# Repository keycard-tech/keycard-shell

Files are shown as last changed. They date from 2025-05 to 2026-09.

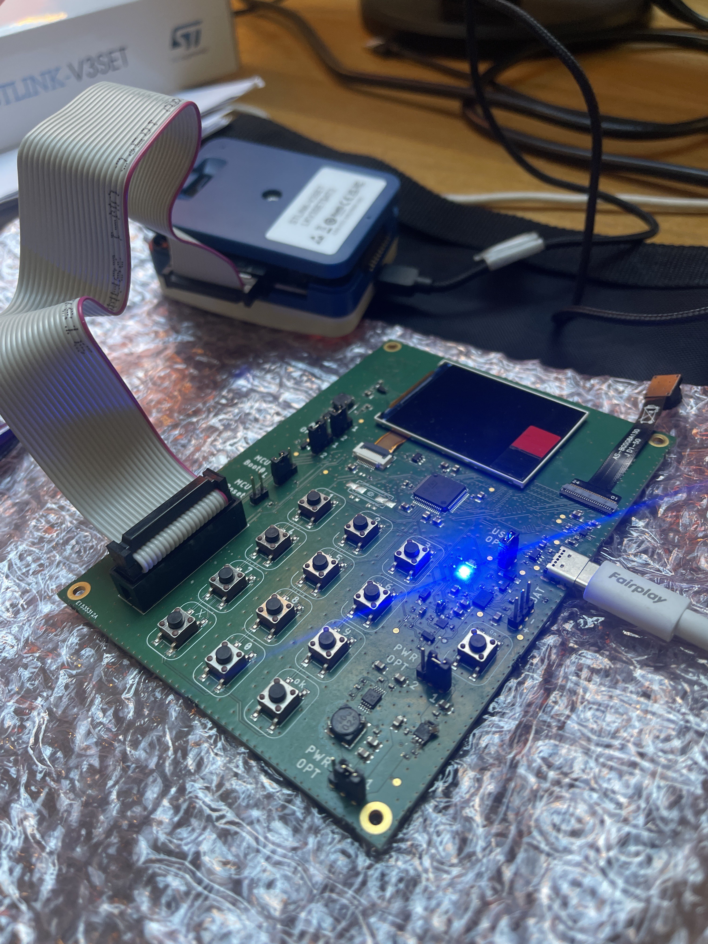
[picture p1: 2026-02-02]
hardware/development_board/IMG_6706.jpg

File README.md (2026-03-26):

# Keycard Shell

Keycard Shell transforms any Keycard into a standalone, air-gapped hardware wallet with built-in keypad, display, camera, and USB (which can be turned off). Fully open-source and EAL6+ certified, it uses ERC-4527 QR codes for secure signing and supports infinite removable backups.

## Main features

### Modular & Open Source

All firmware, hardware designs, and toolchain scripts are fully open source under the MIT license.

### Air-gapped Operation

Scan and display QR codes (ERC-4527) to sign transactions without ever exposing your keys.

### High-Security Secure Element

EAL6+ certified secure element for key storage and signing.

### Removable Smartcards

Support for an infinite number of Keycard smartcards, each with its own key & PIN.

### Wide Compatibility

Works seamlessly with MetaMask, imToken, Rabby, BlueWallet, Sparrow, Specter, and more.

### Built to Last

Powered by a replaceable Nokia BL-4C battery (25+ year expectancy), water & dust resistant.

### Duress PIN

A second PIN stops bad actors from stealing crypto by physical force

## About this repo

This repo contains everything needed to build a Keycard Shell.

### Repo structure

* `app`: the main firmware code. This is what makes everything happen.
* `bootloader`: the bootloader. Since it is non-upgradable we kept its complexity to a minimum.
* `cddl`: contains definitions for the various CBOR messages defined by the UR standard
* `deployment`: git-ignored folder containing the signing keys and build results
* `freertos`: we use FreeRTOS as our task scheduler.
* `hardware`: everything hardware related. From schematics up to case designs.
* `json`: example json files for abi, token and chain db. These files are unused.
* `stm32`: all platform-specific code for the STM32H5 MCU. It also contains the project file for STM32CubeIDE needed to build the firmware.
* `test`: the tests firmware we run in the factory on each unit to check it has been properly assembled.
* `tools`: some tools used during the build process or during development.
* `zcbor`: the library we use to parse CBOR messages.

### Building the firmware

The Keycard Shell firmware build system uses CMake for the main firmware compilation and Python tools for post-processing (signing, image creation, database generation).

#### Getting the Code

First, clone the repository and switch to the release tag you want to build:

```bash
git clone https://github.com/keycard-tech/keycard-shell.git
cd keycard-shell
git checkout v1.1.1   # use the tag matching the official release you want to verify
```

make sure you follow the build instructions directly for the tag you checked out since some steps and toolchain versions can differ.

#### Prerequisites

##### Install Build Tools

**CMake** (3.15 or later) and **Ninja** are required for building the firmware.

On Ubuntu/Debian:
```bash
sudo apt install cmake ninja-build
```

On macOS (with Homebrew):
```bash
brew install cmake ninja
```

On Windows (with Chocolatey):
```bash
choco install cmake ninja
```

Alternatively, download from [cmake.org](https://cmake.org/download/) and [ninja-build.org](https://ninja-build.org/).

##### Install uv

```bash
curl -LsSf https://astral.sh/uv/install.sh | sh
```

or follow your OS instructions for installing uv.

##### Install ARM GCC Toolchain

Required for compiling STM32 firmware. The toolchain is automatically downloaded by the build script:

```bash
./tools/download-toolchain.sh
```

The script supports:
- Linux x86_64
- Linux aarch64
- macOS (Apple Silicon / arm64)
- Windows x86_64

After downloading, the toolchain is installed in `toolchain/`.

#### Setup Signing Keys

Create a `deployment` directory with two files:

- `bootloader-pubkey.txt`: Contains the public key the bootloader will use to verify the firmware. The key must be hex-encoded, uncompressed, and without the leading `04` byte.
- `fw-test-key.txt`: Contains a hex-encoded private key (the private part of the key in `bootloader-pubkey.txt`) used to sign the firmware.

#### Setup Virtual Environment

```bash
uv venv
uv sync
```

#### Build Firmware

```bash
cmake --preset release
cmake --build --preset release
```

#### Verifying the Firmware

After building, run:

```bash
uv run python tools/firmware-hash.py -b build/shellos.bin
```

Download the official binary from the [GitHub releases page](https://github.com/keycard-tech/keycard-shell/releases) and hash it the same way:

```bash
uv run python tools/firmware-hash.py -b ~/Downloads/shellos-<date>-<version>.bin
```

The two hashes must match.

#### Creating a Full Firmware Image

If you want to generate a full image to load on a device you built yourself, take a look at the `tools/create-image.py` script.

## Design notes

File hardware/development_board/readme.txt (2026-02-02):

For security reasons Shell in presales and sales have a locked bootloader that can only run firmwares which have been signed by Keycard CA key. This insures our users that they can trust the software they run. 

For developers who want to develop Shell firmware, you will find in this folder the full design of a development board for Shell

The folder '/devboard_v1' contains this design. Please note that there are some differences in the STM32 pinout between this development board version and shell board.

We'd need someone to update the layout of this dev board based on latest shell designs so that the dev board can actually run the shell builds.

Probably the best way to do this, would be to use the design and schematic from 'serial_run' version and make it in the form factor of this development board 

Get in touch with us either 
- on our discord server https://discord.gg/uJAXk7jFhZ
- our here with a GitHub issue or GitHub discussion

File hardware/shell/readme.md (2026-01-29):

This directory contains the full open-source design for Keycard Shell. It includes electronics, mechanical parts, and certification documents grouped by release series.

## Versions
- `serial_run` corresponds to the design of Keycard Shell launched officially in January 2026
- `pilot_run` ⚠️ deprecated 
- `prototype_v2` ⚠️ deprecated

## Detail of content 
- electronic design: schematics (PDF and editable files), Gerbers, bill of materials, and PCB data archives
- mechanical design: 3D `.step` files for each part, 2D definitions, and a full `.step` of the assembled Keycard Shell
- list of parts of the full assembly, including reference sub-assemblies like screen, battery, camera, and packaging
- certification: full qualification and regulatory reports covering EMC, safety, and transportation

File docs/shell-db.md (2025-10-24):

# Keycard Shell Database

The Keycard Shell Database contains data about Ethereum ABIs, Chains and ERC20 tokens. The script contained in `tools/shell-db.py` is able to generate the database binary files starting from JSON files. For details about the format of the input JSON files look at:

* Ethereum ABI: list of functions, as generated by the [Solidity compiler](https://docs.soliditylang.org/en/latest/abi-spec.html#json)
* Chainlist: format defined by [https://chainlist.org/](https://chainlist.org/)
* ERC20 List: format defined by [https://tokenlists.org/](https://tokenlists.org/)

You are able to reproduce the bin file used to update the database on your Keycard Shell by downloading the source JSON files from https://shell.keycard.tech/update/db-version-history and following the below instructions. The generated file will be identical to the one generated by us, except for the last 64 bytes which are the signature.

## Requirements

All commands in this guide assume you are in the keycard-shell repository. Adjust paths accordingly if needed.

You need to have Python >= 3.12 and install the dependencies with

`pip install -r tools/requirements.txt`

## Building the database

Once you have downloaded the source files for the database version you wish to reproduce, unzip the files and run the following command.

`python tools/shell-db.py -t /path/to/json/files/erc20.json -c /path/to/json/files/chain.json -a /path/to/json/files/abi.json -v VERSIONDATE -d -o db-out.bin`

you can then verify that the binary file included in the downloaded zip and file you just generated differ only in the last 64 bytes. The easiest way to do this is to run the included hashing tool (check the code, it just does SHA256 excluding the last 64 bytes) on both files and check that the output is the same.

`python tools/database-hash.py -b db-out.bin`

and

`python tools/database-hash.py -b /path/to/json/files/db.bin`

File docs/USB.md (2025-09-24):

# Keycard Shell USB protocol

Keycard Shell presents itself to the USB host a HID device with VID 0x1209 and PID 0x21f7. The protocol has been inspired by the one by used by Ledger, being compatible at the transport layer but diverging at the command level.

## Command transport

Keycard Shell exchanges commands with the host following a format closely resembling ISO7816 APDUs. Communication is always started by the host by sending a C-APDU and will receive a single R-APDU in reply by Shell. Timeouts should be handled at USB host level but must account for the fact that many actions require user interaction before a R-APDU is generated.

### C-APDU format

* CLA: 1 byte, set to 0xe0
* INS: 1 byte, identifies the command to execute
* P1: 1 byte, first parameter of the command. Used mostly for command chaining
* P2: 1 byte, second parameter of the command
* Lc: 1 byte, 0-255, length of following Data field
* Data: additional data length. Absent if Lc = 0

### R-APDU format

* Data: 0-253 bytes, response data
* Status Words (SW): 2 bytes error code of the command.

### Command chaining

Since C-APDU are limited to 255 bytes for their data field, it is often necessary to split the payload across multiple APDUs. This is achieved the following way:

1. the host prepares the full payload and splits in chunks of maximum 255 bytes
2. the first chunk is sent with P1 = 0
3. Shell will respond with SW = 0x9000 and no other response data (unless this was the only chunk)
4. all other chunks are sent with P1 = 1
5. Shell will acknowledge each intermediate chunk with SW = 0x9000 while the response to the last chunk will contain the actual reponse.

For this chaining scheme to work Shell must be able to detect when data ends. The way this is handled depends on each command but it either involves including the total length in the first segment or by transmitting data that instrinsically allows detecting its end.

### Encoding conventions

1. All multibyte integers are encoded in big endian byte order
2. BIP32 paths are encoded by 1 byte representing the number of elements (max 10) followed by a sequence of 32-bit integers

### Status Words used by Shell:

* 0x9000: no error
* 0x61XX: more data available (XX is how much data will be in the next chunk)
* 0x6e00: invalid CLA
* 0x6d00: invalid INS (unknown command)
* 0x6982: operation denied (usually by the user)
* 0x6985: conditions not satified
* 0x6a80: invalid Data field
* 0x6501: feature not supported
* 0x6fXX: internal error

## Commands

### GET RESPONSE

* INS: 0xc0
* P1: 0x00
* P2: 0x00
* Data: None

This is a transport level command. In case the SW of the latest received R-APDU was 0x61XX send this command to receive the next chunk of the response. Repeat until you get a SW different from 0x61XX. 

If sent where not more data available, the command will respond with SW = 0x6985.

### GET DEVICE INFO

* INS: 0x06
* P1: 0x00
* P2: 0x00
* Data: None

Returns informations about the device. The format is as follow:

* Firmware version: 3 bytes, representing major, minor, patch revision version respectively.
* Database version: 4 bytes. It's integer value is a date in YYYYMMDD format.
* Device UID: 16 bytes. Unique identifier of this Shell unit.
* Public Key: 33 bytes. A public key that can be used for device verification purposes.

### GET PUBLIC

* INS: 0x02
* P1: 0x00
* P2: 0x00 for normal public key, 0x01 for extended public key
* Data: BIP32 path

Exports the public key of the given BIP32 derivation path. This operation requires user approval. The output format is as follows:

* Length of fingerprint: 1 byte
* Fingerprint: 4 bytes, the master key fingerprint. Useful to identify the wallet.
* Length of public key: 1 byte
* Public key: the public key either in compressed (33-bytes) or uncompressed (65 bytes).
* Length of chain code: 1 byte. If P2 = 0, the value is always 0.
* Chain code: extension to the public key, allowing the client to derive deeper level of public keys

### SIGN ETH TX

* INS: 0x04
* P1: used for command chaining
* P2: 0x00
* Data: BIP32 path, unsigned Ethereum transaction

Signs the given Ethereum transaction. This operation requires user approval. Returns a 65-bytes signature in (v, r, s) format.

### SIGN ETH MSG

* INS: 0x08
* P1: used for command chaining
* P2: 0x00
* Data: BIP32 path, message length on 4 bytes, message to sign

Signs the given message in a way compatible with Ethereum's `personal_sign` function. This operation requires user approval. Returns a 65-bytes signature in (v, r, s) format.

### SIGN EIP712

* INS: 0x0c
* P1: used for command chaining
* P2: 0x00
* Data: BIP32 path, message length on 4 bytes, EIP712 message to sign

Signs the given EIP712 message. This operation requires user approval. Returns a 65-bytes signature in (v, r, s) format.

### SIGN PSBT

* INS: 0x0e
* P1: used for command chaining
* P2: 0x00
* Data: PSBT length on 4 bytes, PSBT to sign

Signs the given PSBT. This operation requires user approval. Returns the entire PSBT with added signatures. Retrieving the full response is likely to require the usage of the `GET RESPONSE` command.

### FW UPGRADE

* INS: 0xf2
* P1: used for command chaining
* P2: 0x00
* Data: firmware length on 4 bytes, firmware to load

Performs a firmware upgrade. This operation requires user approval and the firmware's signature will be verified. The length fo each data chunk must be a multiple of 16 bytes, meaning that the maximum chunk length is 240 bytes. Shell will reply with SW = 0x9000 on success and reboot, which will interrupt the USB connection.

### DB UPGRADE

* INS: 0xf4
* P1: used for command chaining
* P2: 0x00
* Data: databse length on 4 bytes, database to load

Performs a database upgrade. This operation requires user approval and the database's signature will be verified.

## HID framing

Since we are using the USB HID profile, the APDUs will need to be packed into HID frames, which have a length of 64 bytes and thus will require further segmentation/reassembly.

Each frame has the following format

Channel ID: 2 bytes, arbitrarely chosen by the host and repeated by Shell
Frame type: 1 byte. Set to 0x05 for APDU and 0x02 for PING
Segment number: 2 bytes indicating the current segment number (starting from 0)
Total data length: 2 bytes, only present if the segment number = 0 and is the total length of the APDU being transmitted
Data: the chunk of the APDU being transmitted, filling the remaining bytes of the HID frame

If frame type is PING, the Shell will answer with the exact same data received. This is ony useful for link diagnostic.

The APDU frame type is used for both C-APDU and R-APDU and the segmentation/reassembly procedure are exactly the same for both.

### Segmentation

1. Split the data to send into chunks of (64 - 5) bytes, with the first chunk being (64 - 7) bytes.
2. Send the first chunk with segment number = 0 and total data length set to the APDU size.
3. If there is more data to send, increment segment number by 1 and send the next chunk.
4. Repeat until no more chunks. Signal the upper layer that transmission succeded.

### Reassembly

1. If segment number == 0 reset the receiving buffer and set it's final length to the to value of the total data length field.
2. Append the data chunk to the receiving buffer. Increment the expected segment number by 1.
3. Upon receiving the next chunk (if any) check the segment number to matches the expected segment number and append its data to the receiving buffer.
4. When received data matches the total data length, signal the upper layer that reception succeded. Note that the last chunk might contain extra bytes since HID frames are always 64 bytes long. These bytes must be ignored and not added to the receiving buffer.

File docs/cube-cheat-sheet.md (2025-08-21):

# STM3 Programmer CLI cheatsheet

Some commands useful during development

## Write protect bootloader

```shell
.\STM32_Programmer_CLI.exe -c port=SWD ap=1 mode=Hotplug -ob wrpsgn1=0xfffffffe -ob wrpsgn2=0xfffffffe
```

## Disable write protection

```shell
.\STM32_Programmer_CLI.exe -c port=SWD ap=1 mode=Hotplug -ob wrpsgn1=0xffffffff -ob wrpsgn2=0xffffffff
```

## Product state Provisioning

```shell
.\STM32_Programmer_CLI.exe -c port=SWD ap=1 mode=Hotplug -ob product_state=0x17
```

## Product state Locked

```shell
.\STM32_Programmer_CLI.exe -c port=SWD ap=1 mode=Hotplug -ob product_state=0x5c
```

## Swap banks

```shell
.\STM32_Programmer_CLI.exe -c port=SWD ap=1 mode=Hotplug -ob swap_bank=0
```

## Erase all

```shell
.\STM32_Programmer_CLI.exe -c port=SWD ap=1 mode=Hotplug -e all
```

## Erase bootloader

```shell
.\STM32_Programmer_CLI.exe -c port=SWD ap=1 mode=Hotplug -e [0 3] -e [128 131]
```

## Erase firmware

```shell
.\STM32_Programmer_CLI.exe -c port=SWD ap=1 mode=Hotplug -e [4 79] -e [132 207]
```

## Download full

```shell
.\STM32_Programmer_CLI.exe -c port=SWD ap=1 mode=Hotplug --skiperase -w stm32h5.bin 0x08000000 -v
```

## Download bootloader

```shell
.\STM32_Programmer_CLI.exe -c port=SWD ap=1 mode=Hotplug --skiperase -w stm32-bootloader.bin 0x08000000 -v
.\STM32_Programmer_CLI.exe -c port=SWD ap=1 mode=Hotplug --skiperase -w stm32-bootloader.bin 0x08100000 -v
```

## Download firmware

```shell
.\STM32_Programmer_CLI.exe -c port=SWD ap=1 mode=Hotplug --skiperase -w stm32.bin 0x08008000 -v
.\STM32_Programmer_CLI.exe -c port=SWD ap=1 mode=Hotplug --skiperase -w stm32.bin 0x08108000 -v
```

## Full bootloader replace sequence

```shell
.\STM32_Programmer_CLI.exe -c port=SWD ap=1 mode=Hotplug -ob wrpsgn1=0xffffffff -ob wrpsgn2=0xffffffff
.\STM32_Programmer_CLI.exe -c port=SWD ap=1 mode=Hotplug -ob swap_bank=0
.\STM32_Programmer_CLI.exe -c port=SWD ap=1 mode=Hotplug -e [0 3] -e [128 131]
.\STM32_Programmer_CLI.exe -c port=SWD ap=1 mode=Hotplug --skiperase -w C:\Users\tanuki\git\keycard-pro\stm32\BL\stm32-bootloader.bin 0x08000000 -v
.\STM32_Programmer_CLI.exe -c port=SWD ap=1 mode=Hotplug --skiperase -w C:\Users\tanuki\git\keycard-pro\stm32\BL\stm32-bootloader.bin 0x08100000 -v
.\STM32_Programmer_CLI.exe -c port=SWD ap=1 mode=Hotplug -ob wrpsgn1=0xfffffffe -ob wrpsgn2=0xfffffffe
```

## Full fw replace sequence

```shell
.\STM32_Programmer_CLI.exe -c port=SWD ap=1 mode=Hotplug -ob swap_bank=0
.\STM32_Programmer_CLI.exe -c port=SWD ap=1 mode=Hotplug -e [4 79] -e [132 207]
.\STM32_Programmer_CLI.exe -c port=SWD ap=1 mode=Hotplug --skiperase -w stm32.bin 0x08008000 -v
.\STM32_Programmer_CLI.exe -c port=SWD ap=1 mode=Hotplug --skiperase -w stm32.bin 0x08108000 -v
```

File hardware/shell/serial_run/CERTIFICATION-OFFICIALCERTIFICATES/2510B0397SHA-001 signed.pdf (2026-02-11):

Disclaimer: This document is controlled and has been released electronically. Only the version on the IECEE Website is the current document version

Test Report issued under the responsibility of:

### TEST REPORT IEC 62368-1

## Audio/video, information and communication technology equipment Part 1: Safety requirements

Report Number | : | 2510B0397SHA-001
Date of issue | : | 2026-02-02
Total number of pages | : | 57 pages
Name of Testing Laboratory preparing the Report | : | Intertek Testing Services (Shanghai FTZ) Co., Ltd.
Applicant’s name | : | Status Research and Development GmbH
Address | : | Baarerstrasse 10, 6302 Zug, Switzerland

Test specification:

Standard | : | UL 62368-1:2019 Ed.3+R:22Oct2021
| CSA C22.2#62368-1:2019 Ed.3+U1
Test procedure | : | Testing
Non-standard test method | : | N/A
TRF template used | : | IECEE OD-2020-F1:2021, Ed.1.4
Test Report Form No | : | IEC62368_1E
Test Report Form(s) Originator.... : | UL(US)
Master TRF | : | Dated 2022-04-14

Copyright © 2022 IEC System of Conformity Assessment Schemes for Electrotechnical Equipment and Components (IECEE System). All rights reserved.

This publication may be reproduced in whole or in part for non-commercial purposes as long as the IECEE is acknowledged as copyright owner and source of the material. IECEE takes no responsibility for and will not assume liability for damages resulting from the reader's interpretation of the reproduced material due to its placement and context.
If this Test Report Form is used by non-IECEE members, the IECEE/IEC logo and the reference to the CB Scheme procedure shall be removed.

This report is not valid as a CB Test Report unless signed by an approved CB Testing Laboratory and appended to a CB Test Certificate issued by an NCB in accordance with IECEE 02.

General disclaimer:

The test results presented in this report relate only to the object tested.
This report shall not be reproduced, except in full, without the written approval of the Issuing CB Testing Laboratory. The authenticity of this Test Report and its contents can be verified by contacting the NCB, responsible for this Test Report.

Page 2 of 57 | Report No. 2510B0397SHA-001

TRF No. IEC62368_1E

Test item description | : | Keycard shell
Trade Mark(s) | : | Keycard
Manufacturer | : | Same as applicant
Model/Type reference | : | Shell
Ratings | : | 5Vdc, 1A, Class III

Responsible Testing Laboratory (as applicable), testing procedure and testing location(s):

| CB Testing Laboratory: | Intertek Testing Services (Shanghai FTZ) Co., Ltd.
Testing location/ address | : | | Building 86, No.1198, Qinzhou North Road, Shanghai, China
Tested by (name, function, signature) ....... : | Henry Huang/ Adage Zhang (Engineer)
Approved by (name, function, signature) .. : | Sam Li (Mandated Reviewer)
| Testing procedure: CTF Stage 1:
Testing location/ address | :

Tested by (name, function, signature) ....... :

Approved by (name, function, signature) .. :

| Testing procedure: CTF Stage 2:
Testing location/ address | :
Tested by (name, function, signature) |

Witnessed by (name, function, signature). :

Approved by (name, function, signature) .. :

| Testing procedure: CTF Stage 3:
| Testing procedure: CTF Stage 4:
Testing location/ address | :

Tested by (name, function, signature) ....... :

Witnessed by (name, function, signature). :

Approved by (name, function, signature) .. :

Supervised by (name, function, signature) :

Page 3 of 57 | Report No. 2510B0397SHA-001

TRF No. IEC62368_1E

List of Attachments (including a total number of pages in each attachment): Page 48 - 54: National differences for USA and Canada
Page 55 - 57: Photograph of the Equipment under test (EUT).

Summary of testing:

All tests are performed and the most disadvantageous results are recorded. We conclude that the appliances comply with this standard.

Tests performed (name of test and test clause):
5.2, Classification of electrical energy sources

5.4.1.4, 6.3, 6.4, 9.0, B.2.6, B.3, B.4,

Annex G.5.3, G.5.4, Heating test and abnormal &fault condition test

6.2.2, Electrical power sources (PS) measurements for classification

Annex B.2.5 Input test

Annex B.3, B.4, Abnormal operating and fault condition tests

Annex M.3, Protection circuits for batteries provided within the equipment

Annex M.4.2, Charging safeguards for equipment containing a secondary lithium battery

Testing location:
Intertek Testing Services (Shanghai FTZ) Co., Ltd. Building 86, No.1198, Qinzhou North Road, Shanghai, China

Summary of compliance with National Differences (List of countries addressed):

National differences for USA and Canada have been checked.

The product fulfils the requirements of UL 62368-1:2019 Ed.3+R:22Oct2021 and

CSA C22.2#62368-1:2019 Ed.3+U1

Page 4 of 57 | Report No. 2510B0397SHA-001

TRF No. IEC62368_1E

Use of uncertainty of measurement for decisions on conformity (decision rule) :

No decision rule is specified by the IEC standard, when comparing the measurement result with the applicable limit according to the specification in that standard. The decisions on conformity are made without applying the measurement uncertainty (“simple acceptance” decision rule, previously known as “accuracy method”).

Other:… (to be specified, for example when required by the standard or client, or if national accreditation requirements apply)

Information on uncertainty of measurement:
The uncertainties of measurement are calculated by the laboratory based on application of criteria given by OD-5014 for test equipment and application of test methods, decision sheets and operational procedures of IECEE.
IEC Guide 115 provides guidance on the application of measurement uncertainty principles and applying the decision rule when reporting test results within IECEE scheme, noting that the reporting of the measurement uncertainty for measurements is not necessary unless required by the test standard or customer.

Calculations leading to the reported values are on file with the NCB and testing laboratory that conducted the testing.

Copy of marking plate:

The artwork below may be only a draft. The use of certification marks on a product must be authorized by the respective NCBs that own these marks.

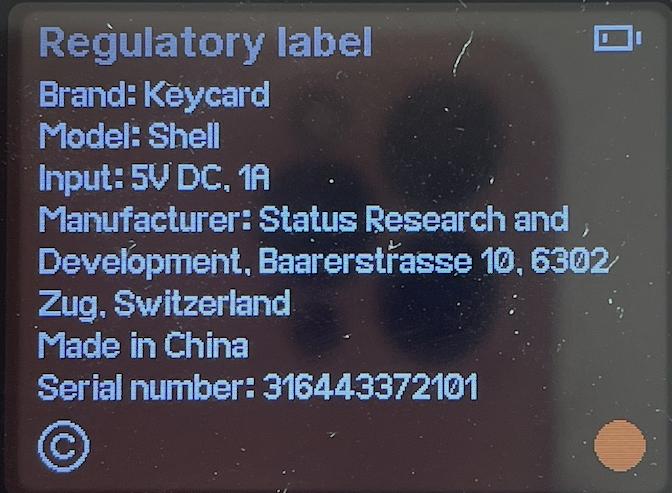
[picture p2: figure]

Page 5 of 57 | Report No. 2510B0397SHA-001

TRF No. IEC62368_1E

Test item particulars:

Product group | : | end product | built-in component
Classification of use by | : | Ordinary person | Children likely present
Instructed person
Skilled person
Supply connection | : | AC mains | DC mains
not mains connected:
| | ES1 | ES2 | ES3
Supply tolerance | : | +10%/-10%
+20%/-15%
| + | %/ - | %
| None
Supply connection – type | : | pluggable equipment type A -
non-detachable supply cord appliance coupler
direct plug-in
pluggable equipment type B -non-detachable supply cord appliance coupler
permanent connection
mating connector
other: Not direct connected to the mains Considered current rating of protective
device | :

A;
Location: | building | equipment
| N/A
Equipment mobility | : | movable | hand-held | transportable
direct plug-in | stationary | for building-in
wall/ceiling-mounted | SRME/rack-mounted
| other:
Overvoltage category (OVC) | : | OVC I | OVC II | OVC III
| OVC IV
other: Not direct connected to the mains
Class of equipment | : | Class I | Class II | Class III
Not classified
Special installation location | : | N/A | restricted access area
outdoor location
Pollution degree (PD) | : | PD 1 | PD 2 | PD 3
Manufacturer’s specified Tma | : 40 °C | Outdoor: minimum | °C
IP protection class | : | IPX0 | | IP___
Power systems | : | TN | TT | IT - | V L-L
not AC mains
Altitude during operation (m) | : | 2000 m or less | m
Altitude of test laboratory (m) | : | 2000 m or less | m
Mass of equipment (kg) | : <1 kg

Page 6 of 57 | Report No. 2510B0397SHA-001

TRF No. IEC62368_1E

Possible test case verdicts:

- test case does not apply to the test object....: N/A
- test object does meet the requirement | : P (Pass)
- test object does not meet the requirement....: F (Fail)

Testing:

Date of receipt of test item | : 2025-10-21
Date (s) of performance of tests | : 2025-10-21 to 2025-12-8

General remarks:
"(See Enclosure #)" refers to additional information appended to the report.
"(See appended table)" refers to a table appended to the report.
Throughout this report a | comma / | point is used as the decimal separator.
Determination of the test conclusion is based on IEC Guide 115 in consideration of measurement uncertainty.
This report is for the exclusive use of Intertek's Client and is provided pursuant to the agreement between Intertek and its Client. Intertek's responsibility and liability are limited to the terms and conditions of the agreement. Intertek assumes no liability to any party, other than to the Client in accordance with the agreement, for any loss, expense or damage occasioned by the use of this report. Only the Client is authorized to permit copying or distribution of this report and then only in its entirety. Any use of the Intertek name or one of its marks for the sale or advertisement of the tested material, product or service must first be approved in writing by Intertek. The observations and test results in this report are relevant only to the sample tested. This report by itself does not imply that the material, product, or service is or has ever been under an Intertek certification program.
When determining the test conclusion, the Measurement Uncertainty of test has been considered.

Manufacturer’s Declaration per sub-clause 4.2.5 of IECEE 02:

The application for obtaining a CB Test Certificate
includes more than one factory location and a
declaration from the Manufacturer stating that the
sample(s) submitted for evaluation is (are) representative of the products from each factory
has been provided | :
| | Yes
| | Not applicable

When differences exist; they shall be identified in the General product information section.

Name and address of factory (ies) | : ALTYOR Industries (Shanghai) Co., Ltd

152/1421 Zhuan Xing Dong Road Minhang District,

Shanghai, 201108, CHINA

General product information and other remarks:

The EUT is a keycard shell, class III of equipment for indoor use only, which supplied by built-in lithium battery, 3.7Vdc, the adaptor output is considered as ES1 and PS1 circuit.

Maximum recommended ambient (Tmra):40℃

Model Differences
N/A

Page 7 of 57 | Report No. 2510B0397SHA-001

TRF No. IEC62368_1E

OVERVIEW OF ENERGY SOURCES AND SAFEGUARDS

Clause | Possible Hazard
5 | Electrically-caused injury
Class and Energy Source (e.g. ES3: Primary circuit) | Body Part (e.g. Ordinary) | Safeguards
B | S | R
ES1: All circuits | Ordinary | N/A | N/A | N/A
6 | Electrically-caused fire
Class and Energy Source (e.g. PS2: 100 Watt circuit) | Material part (e.g. Printed board) | Safeguards
| | B | 1 st S | 2 nd S
PS1: Input circuits | All combustible materials on mainboard | N/A | N/A | N/A
PS1: Battery output circuits | All combustible materials on mainboard | N/A | N/A | N/A
7 | Injury caused by hazardous substances
Class and Energy Source (e.g. Ozone) | Body Part (e.g., Skilled) | Safeguards
| | B | S | R
Li-ion battery | Ordinary | Internal protection circuit | Enclosure | N/A
8 | Mechanically-caused injury
Class and Energy Source (e.g. MS3: Plastic fan blades) | Body Part (e.g. Ordinary) | Safeguards
| | B | S | R
MS1: Sharp edges and corners | Ordinary | N/A | N/A | N/A
MS1: Equipment mass | Ordinary | N/A | N/A | N/A
9 | Thermal burn
Class and Energy Source (e.g. TS1: Keyboard caps) | Body Part (e.g., Ordinary) | Safeguards
| | B | S | R
TS1: Accessible part | Ordinary | N/A | N/A | N/A
10 | Radiation
Class and Energy Source (e.g. RS1: PMP sound output) | Body Part (e.g., Ordinary) | Safeguards
| | B | S | R
N/A | N/A | N/A | N/A | N/A

Supplementary Information:

“B” – Basic Safeguard; “S” – Supplementary Safeguard; “R” – Reinforced Safeguard

a) represent for “Ignition not occur; not greater than 90% of the spontaneous ignition temperature limit”

Page 8 of 57 | Report No. 2510B0397SHA-001

TRF No. IEC62368_1E

ENERGY SOURCE DIAGRAM

Optional. Manufacturers are to provide the energy sources diagram identify declared energy sources and identifying the demarcations are between power sources. Recommend diagram be provided included in power supply and multipart systems.

Insert diagram below. Example diagram designs are; Block diagrams; image(s) with layered data; mechanical drawings

ES | PS | MS | TS | RS

Page 9 of 57 | Report No. 2510B0397SHA-001

IEC 62368-1

Clause | Requirement + Test | Result - Remark | Verdict

TRF No. IEC62368_1E

4 | GENERAL REQUIREMENTS | P
4.1.1 | Acceptance of materials, components and subassemblies | See appended table 4.1.2. | P
4.1.2 | Use of components | (See appended table 4.1.2) | P
4.1.3 | Equipment design and construction | No accessible part which could cause injury. | P
4.1.4 | Specified ambient temperature for outdoor use (oC) | : | | N/A
4.1.5 | Constructions and components not specifically covered | | N/A
4.1.8 | Liquids and liquid filled components (LFC) | (See G.15) | N/A
4.1.15 | Markings and instructions | (See Annex F) | P
4.4.3 | Safeguard robustness | | N/A
4.4.3.1 | General | | N/A
4.4.3.2 | Steady force tests | (See Clause T.3, T.4, T.5) | N/A
4.4.3.3 | Drop tests | | N/A
4.4.3.4 | Impact tests | | N/A
4.4.3.5 | Internal accessible safeguard tests | | N/A
4.4.3.6 | Glass impact tests | (See Clause T.9, Annex U) | N/A
4.4.3.7 | Glass fixation tests | | N/A
| Glass impact test (1J) | | N/A
| Push/pull test (10 N) | | N/A
4.4.3.8 | Thermoplastic material tests | (See Clause T.8) | N/A
4.4.3.9 | Air comprising a safeguard | | N/A
4.4.3.10 | Accessibility, glass, safeguard effectiveness | | N/A
4.4.4 | Displacement of a safeguard by an insulating liquid | | N/A
4.4.5 | Safety interlocks | (See Annex K) | N/A
4.5 | Explosion | | P
4.5.1 | General | (See Annex M for batteries) | P
4.5.2 | No explosion during normal/abnormal operating condition | (See Clause B.2, B.3) | P
| No harm by explosion during single fault conditions | (See Clause B.4) | P
4.6 | Fixing of conductors | | N/A
| Fix conductors not to defeat a safeguard | | N/A
| Compliance is checked by test | : | (See Clause T.2) | N/A
4.7 | Equipment for direct insertion into mains socket–outlets | | N/A

Page 10 of 57 | Report No. 2510B0397SHA-001

IEC 62368-1

Clause | Requirement + Test | Result - Remark | Verdict

TRF No. IEC62368_1E

4.7.2 | Mains plug part complies with relevant standard .. : | | N/A
4.7.3 | Torque (Nm) | : | | N/A
4.8 | Equipment containing coin/button cell batteries | | N/A
4.8.1 | General | | N/A
4.8.2 | Instructional safeguard | : | | N/A
4.8.3 | Battery compartment door/cover construction | | N/A
| Open torque test | | N/A
4.8.4.2 | Stress relief test | | N/A
4.8.4.3 | Battery replacement test | | N/A
4.8.4.4 | Drop test | | N/A
4.8.4.5 | Impact test | | N/A
4.8.4.6 | Crush test | | N/A
4.8.5 | Compliance | | N/A
| 30N force test with test probe | | N/A
| 20N force test with test hook | | N/A
4.9 | Likelihood of fire or shock due to entry of conductive object | | N/A
4.10 | Component requirements | | N/A
4.10.1 | Disconnect Device | (See Annex L) | N/A
4.10.2 | Switches and relays | (See Annex G) | N/A
5 | ELECTRICALLY-CAUSED INJURY | P
5.2 | Classification and limits of electrical energy sources | P
5.2.2 | ES1, ES2 and ES3 limits | | P
5.2.2.2 | Steady-state voltage and current limits | : | (See appended table 5.2) | P
5.2.2.3 | Capacitance limits | : | (See appended table 5.2) | N/A
5.2.2.4 | Single pulse limits | : | (See appended table 5.2) | N/A
5.2.2.5 | Limits for repetitive pulses | : | (See appended table 5.2) | N/A
5.2.2.6 | Ringing signals | (See Annex H) | N/A
5.2.2.7 | Audio signals | (See Clause E.1) | N/A
5.3 | Protection against electrical energy sources | | N/A
5.3.1 | General Requirements for accessible parts to ordinary, instructed and skilled persons | | N/A
5.3.1 a) | Accessible ES1/ES2 derived from ES2/ES3 circuits | | N/A
5.3.1 b) | Skilled persons not unintentional contact ES3 bare conductors | | N/A

Page 11 of 57 | Report No. 2510B0397SHA-001

IEC 62368-1

Clause | Requirement + Test | Result - Remark | Verdict

TRF No. IEC62368_1E

5.3.2.1 | Accessibility to electrical energy sources and safeguards | | N/A
| Accessibility to outdoor equipment bare parts | | N/A
5.3.2.2 | Contact requirements | | N/A
| Test with test probe from Annex V | | ⎯
5.3.2.2 a) | Air gap – electric strength test potential (V) | : | (See appended table 5.4.9) | N/A
5.3.2.2 b) | Air gap – distance (mm) | : | | N/A
5.3.2.3 | Compliance | | N/A
5.3.2.4 | Terminals for connecting stripped wire | | N/A
5.4 | Insulation materials and requirements | | N/A
5.4.1.2 | Properties of insulating material | | N/A
5.4.1.3 | Material is non-hygroscopic | | N/A
5.4.1.4 | Maximum operating temperature for insulating materials | : | (See appended table) | N/A
5.4.1.5 | Pollution degrees | : | | N/A
5.4.1.5.2 | Test for pollution degree 1 environment and for an insulating compound | | N/A
5.4.1.5.3 | Thermal cycling test | | N/A
5.4.1.6 | Insulation in transformers with varying dimensions | | N/A
5.4.1.7 | Insulation in circuits generating starting pulses | | N/A
5.4.1.8 | Determination of working voltage | : | (See appended table 5.4.1.8) | N/A
5.4.1.9 | Insulating surfaces | | N/A
5.4.1.10 | Thermoplastic parts on which conductive metallic parts are directly mounted | | N/A
5.4.1.10.2 | Vicat test | : | (See appended table 5.4.1.10.2) | N/A
5.4.1.10.3 | Ball pressure test | : | (See appended table 5.4.1.10.3) | N/A
5.4.2 | Clearances | | N/A
5.4.2.1 | General requirements | | N/A
| Clearances in circuits connected to AC Mains, Alternative method | (See Annex X) | N/A
5.4.2.2 | Procedure 1 for determining clearance | | N/A
| Temporary overvoltage | : | | ⎯
5.4.2.3 | Procedure 2 for determining clearance | | N/A
5.4.2.3.2.2 | a.c. mains transient voltage | : | | ⎯
5.4.2.3.2.3 | d.c. mains transient voltage | : | | ⎯

Page 12 of 57 | Report No. 2510B0397SHA-001

IEC 62368-1

Clause | Requirement + Test | Result - Remark | Verdict

TRF No. IEC62368_1E

5.4.2.3.2.4 | External circuit transient voltage | : | | ⎯
5.4.2.3.2.5 | Transient voltage determined by measurement ......: | | ⎯
5.4.2.4 | Determining the adequacy of a clearance using an electric strength test | : | (See appended table 5.4.2) | N/A
5.4.2.5 | Multiplication factors for clearances and test voltages | : | | N/A
5.4.2.6 | Clearance measurement | : | (See appended table 5.4.2) | N/A
5.4.3 | Creepage distances | | N/A
5.4.3.1 | General | | N/A
5.4.3.3 | Material group | : | | ⎯
5.4.3.4 | Creepage distances measurement | : | (See appended table 5.4.3) | N/A
5.4.4 | Solid insulation | | N/A
5.4.4.1 | General requirements | | N/A
5.4.4.2 | Minimum distance through insulation | : | (See appended table 5.4.4.2) | N/A
5.4.4.3 | Insulating compound forming solid insulation | | N/A
5.4.4.4 | Solid insulation in semiconductor devices | | N/A
5.4.4.5 | Insulating compound forming cemented joints | | N/A
5.4.4.6 | Thin sheet material | | N/A
5.4.4.6.1 | General requirements | | N/A
5.4.4.6.2 | Separable thin sheet material | | N/A
| Number of layers (pcs) | : | | N/A
5.4.4.6.3 | Non-separable thin sheet material | | N/A
| Number of layers (pcs) | : | | N/A
5.4.4.6.4 | Standard test procedure for non-separable thin sheet material | : | (See appended table 5.4.9) | N/A
5.4.4.6.5 | Mandrel test | | N/A
5.4.4.7 | Solid insulation in wound components | | N/A
5.4.4.9 | Solid insulation at frequencies >30 kHz, EP, KR, d, VPW (V) | : | (See appended Table 5.4.4.9) | N/A
| Alternative by electric strength test, tested voltage (V), KR | : | (See appended Tables 5.4.4.9 and 5.4.9) | N/A
5.4.5 | Antenna terminal insulation | | N/A
5.4.5.1 | General | | N/A
5.4.5.2 | Voltage surge test | | N/A
5.4.5.3 | Insulation resistance (MΩ) | : | | N/A
| Electric strength test | : | (See appended table 5.4.9) | N/A

Page 13 of 57 | Report No. 2510B0397SHA-001

IEC 62368-1

Clause | Requirement + Test | Result - Remark | Verdict

TRF No. IEC62368_1E

5.4.6 | Insulation of internal wire as part of supplementary safeguard | | N/A
5.4.7 | Tests for semiconductor components and for cemented joints | | N/A
5.4.8 | Humidity conditioning | | N/A
| Relative humidity (%), temperature (°C), duration (h) | : | | ⎯
5.4.9 | Electric strength test | | N/A
5.4.9.1 | Test procedure for type test of solid insulation.......: | (See appended table 5.4.9) | N/A
5.4.9.2 | Test procedure for routine test | | N/A
5.4.10 | Safeguards against transient voltages from external circuits | | N/A
5.4.10.1 | Parts and circuits separated from external circuits | | N/A
5.4.10.2 | Test methods | | N/A
5.4.10.2.1 | General | | N/A
5.4.10.2.2 | Impulse test | : | (See appended table 5.4.9) | N/A
5.4.10.2.3 | Steady-state test | : | (See appended table 5.4.9) | N/A
5.4.10.3 | Verification for insulation breakdown for impulse test | : | | N/A
5.4.11 | Separation between external circuits and earth | | N/A
5.4.11.1 | Exceptions to separation between external circuits and earth | | N/A
5.4.11.2 | Requirements | | N/A
| SPDs bridge separation between external circuit and earth | | N/A
| Rated operating voltage Uop (V) | : | | ⎯
| Nominal voltage Upeak (V) | : | | ⎯
| Max increase due to variation ΔUsp | : | | ⎯
| Max increase due to ageing ΔUsa | : | | ⎯
5.4.11.3 | Test method and compliance | : | (See appended table 5.4.9) | N/A
5.4.12 | Insulating liquid | | N/A
5.4.12.1 | General requirements | | N/A
5.4.12.2 | Electric strength of an insulating liquid | : | (See appended table 5.4.9) | N/A
5.4.12.3 | Compatibility of an insulating liquid | : | (See appended table 5.4.9) | N/A
5.4.12.4 | Container for insulating liquid | : | | N/A
5.5 | Components as safeguards | | N/A
5.5.1 | General | | N/A

Page 14 of 57 | Report No. 2510B0397SHA-001

IEC 62368-1

Clause | Requirement + Test | Result - Remark | Verdict

TRF No. IEC62368_1E

5.5.2 | Capacitors and RC units | | N/A
5.5.2.1 | General requirement | | N/A
5.5.2.2 | Safeguards against capacitor discharge after disconnection of a connector | : | (See appended table 5.5.2.2) | N/A
5.5.3 | Transformers | | N/A
5.5.4 | Optocouplers | (See sub-clause 5.4 or Clause G.12) | N/A
5.5.5 | Relays | (See sub-clause 5.4) | N/A
5.5.6 | Resistors | (See Clause G.10) | N/A
5.5.7 | SPDs | (See Clause G.8) | N/A
5.5.8 | Insulation between the mains and an external circuit consisting of a coaxial cable | : | | N/A
5.5.9 | Safeguards for socket-outlets in outdoor equipment | | N/A
| RCD rated residual operating current (mA) | : | | ⎯
5.6 | Protective conductor | | N/A
5.6.2 | Requirement for protective conductors | | N/A
5.6 | Protective conductor | | N/A
5.6.2 | Requirement for protective conductors | | N/A
5.6.2.1 | General requirements | | N/A
5.6.2.2 | Colour of insulation | | N/A
5.6.3 | Requirement for protective earthing conductors | | N/A
| Protective earthing conductor size (mm² ) | : | | ⎯
| Protective earthing conductor serving as a reinforced safeguard | | N/A
| Protective earthing conductor serving as a double safeguard | | N/A
5.6.4 | Requirements for protective bonding conductors | | N/A
5.6.4.1 | Protective bonding conductors | | N/A
| Protective bonding conductor size (mm² ) | : | | ⎯
5.6.4.2 | Protective current rating (A) | : | | N/A
5.6.5 | Terminals for protective conductors | | N/A
5.6.5.1 | Terminal size for connecting protective earthing conductors (mm) | : | | N/A
| Terminal size for connecting protective bonding conductors (mm) | : | | N/A
5.6.5.2 | Corrosion | | N/A
5.6.6 | Resistance of the protective bonding system | | N/A

Page 15 of 57 | Report No. 2510B0397SHA-001

IEC 62368-1

Clause | Requirement + Test | Result - Remark | Verdict

TRF No. IEC62368_1E

5.6.6.1 | Requirements | | N/A
5.6.6.2 | Test Method | : | (See appended table 5.6.6) | N/A
5.6.6.3 | Resistance (Ω) or voltage drop | : | (See appended table 5.6.6) | N/A
5.6.7 | Reliable connection of a protective earthing conductor | | N/A
5.6.8 | Functional earthing | | N/A
| Conductor size (mm² ) | : | | N/A
| Class II with functional earthing marking | : | | N/A
| Appliance inlet cl & cr (mm) | : | | N/A
5.7 | Prospective touch voltage, touch current and protective conductor current | | N/A
5.7.2 | Measuring devices and networks | | N/A
5.7.2.1 | Measurement of touch current | | N/A
5.7.2.2 | Measurement of voltage | | N/A
5.7.3 | Equipment set-up, supply connections and earth connections | | N/A
5.7.4 | Unearthed accessible parts | : | (See appended table 5.7.4) | N/A
5.7.5 | Earthed accessible conductive parts | : | (See appended table 5.7.5) | N/A
5.7.6 | Requirements when touch current exceeds ES2 limits | | N/A
| Protective conductor current (mA) | : | | N/A
| Instructional Safeguard | : | | N/A
5.7.7 | Prospective touch voltage and touch current associated with external circuits | | N/A
5.7.7.1 | Touch current from coaxial cables | | N/A
5.7.7.2 | Prospective touch voltage and touch current associated with paired conductor cables | | N/A
5.7.8 | Summation of touch currents from external circuits | | N/A
| a) Equipment connected to earthed external circuits, current (mA) | : | | N/A
| b) Equipment connected to unearthed external circuits, current (mA) | : | | N/A
5.8 | Backfeed safeguard in battery backed up supplies | | N/A
| Mains terminal ES | : | (See appended table 5.8) | N/A
| Air gap (mm) | : | | N/A
6 | ELECTRICALLY- CAUSED FIRE | P
6.2 | Classification of PS and PIS | P
6.2.2 | Power source circuit classifications | : | (See appended table 6.2.2) | P

Page 16 of 57 | Report No. 2510B0397SHA-001

IEC 62368-1

Clause | Requirement + Test | Result - Remark | Verdict

TRF No. IEC62368_1E

6.2.3 | Classification of potential ignition sources | | N/A
6.2.3.1 | Arcing PIS | : | (See appended table 6.2.3.1) | N/A
6.2.3.2 | Resistive PIS | : | (See appended table 6.2.3.2) | N/A
6.3 Safeguards against fire under normal operating and abnormal operating | conditions | | P
6.3.1 | No ignition and attainable temperature value less than 90 % defined by ISO 871 or less than 300 °C for unknown materials | : | (See appended table B.1.5 and B.3) | P
| Combustible materials outside fire enclosure | : | | N/A
6.4 | Safeguards against fire under single fault conditions | | P
6.4.1 | Safeguard method | Control fire spread method. | P
6.4.2 | Reduction of the likelihood of ignition under single fault conditions in PS1 circuits | | N/A
6.4.3 | Reduction of the likelihood of ignition under single fault conditions in PS2 and PS3 circuits | | N/A
6.4.3.1 | Supplementary safeguards | | N/A
6.4.3.2 | Single Fault Conditions | : | (See appended table B.4) | N/A
| Special conditions for temperature limited by fuse | | N/A
6.4.4 | Control of fire spread in PS1 circuits | | P
6.4.5 | Control of fire spread in PS2 circuits | | N/A
6.4.5.2 | Supplementary safeguards | | N/A
6.4.6 | Control of fire spread in PS3 circuits | | N/A
6.4.7 | Separation of combustible materials from a PIS | | N/A
6.4.7.2 | Separation by distance | | N/A
6.4.7.3 | Separation by a fire barrier | | N/A
6.4.8 | Fire enclosures and fire barriers | | N/A
6.4.8.2 | Fire enclosure and fire barrier material properties | | N/A
6.4.8.2.1 | Requirements for a fire barrier | | N/A
6.4.8.2.2 | Requirements for a fire enclosure | | N/A
6.4.8.3 | Constructional requirements for a fire enclosure and a fire barrier | | N/A
6.4.8.3.1 | Fire enclosure and fire barrier openings | | N/A
6.4.8.3.2 | Fire barrier dimensions | | N/A
6.4.8.3.3 | Top openings and properties | | N/A
| Openings dimensions (mm) | : | | N/A
6.4.8.3.4 | Bottom openings and properties | | N/A
| Openings dimensions (mm) | : | | N/A

Page 17 of 57 | Report No. 2510B0397SHA-001

IEC 62368-1

Clause | Requirement + Test | Result - Remark | Verdict

TRF No. IEC62368_1E

| Flammability tests for the bottom of a fire enclosure | (See Clause S.3) | N/A
| Instructional Safeguard | : | | N/A
6.4.8.3.5 | Side openings and properties | | N/A
| Openings dimensions (mm) | : | | N/A
6.4.8.3.6 | Integrity of a fire enclosure, condition met: a), b) or c) | : | | N/A
6.4.8.4 | Separation of a PIS from a fire enclosure and a fire barrier distance (mm) or flammability rating | : | | N/A
6.4.9 | Flammability of insulating liquid | : | | N/A
6.5 | Internal and external wiring | | N/A
6.5.1 | General requirements | | N/A
6.5.2 | Requirements for interconnection to building wiring | : | | N/A
6.5.3 | Internal wiring size (mm² ) for socket-outlets | : | | N/A
6.6 | Safeguards against fire due to the connection to additional equipment | | N/A
7 | INJURY CAUSED BY HAZARDOUS SUBSTANCES | P
7.2 | Reduction of exposure to hazardous substances | N/A
7.3 | Ozone exposure | N/A
7.4 | Use of personal safeguards or personal protective equipment (PPE) | N/A
| Personal safeguards and instructions | : | | ⎯
7.5 | Use of instructional safeguards and instructions | | N/A
| Instructional safeguard (ISO 7010) | : | | ⎯
7.6 | Batteries and their protection circuits | | P
8 | MECHANICALLY-CAUSED INJURY | P
8.2 | Mechanical energy source classifications | P
8.3 | Safeguards against mechanical energy sources | N/A
8.4 | Safeguards against parts with sharp edges and corners | N/A
8.4.1 | Safeguards | | N/A
| Instructional Safeguard | : | | N/A
8.4.2 | Sharp edges or corners | | N/A
8.5 | Safeguards against moving parts | | N/A
8.5.1 | Fingers, jewellery, clothing, hair, etc., contact with MS2 or MS3 parts | | N/A
| MS2 or MS3 part required to be accessible for the function of the equipment | | N/A

Page 18 of 57 | Report No. 2510B0397SHA-001

IEC 62368-1

Clause | Requirement + Test | Result - Remark | Verdict

TRF No. IEC62368_1E

| Moving MS3 parts only accessible to skilled person | N/A
8.5.2 | Instructional safeguard | : | N/A
8.5.4 | Special categories of equipment containing moving parts | N/A
8.5.4.1 | General | N/A
8.5.4.2 | Equipment containing work cells with MS3 parts | N/A
8.5.4.2.1 | Protection of persons in the work cell | N/A
8.5.4.2.2 | Access protection override | N/A
8.5.4.2.2.1 | Override system | N/A
8.5.4.2.2.2 | Visual indicator | N/A
8.5.4.2.3 | Emergency stop system | N/A
| Maximum stopping distance from the point of activation (m) | : | N/A
| Space between end point and nearest fixed mechanical part (mm) | : | N/A
8.5.4.2.4 | Endurance requirements | N/A
| Mechanical system subjected to 100 000 cycles of operation | N/A
| - Mechanical function check and visual inspection | N/A
| - Cable assembly | : | N/A
8.5.4.3 | Equipment having electromechanical device for destruction of media | N/A
8.5.4.3.1 | Equipment safeguards | N/A
8.5.4.3.2 | Instructional safeguards against moving parts ........: | N/A
8.5.4.3.3 | Disconnection from the supply | N/A
8.5.4.3.4 | Cut type and test force (N) | : | N/A
8.5.4.3.5 | Compliance | N/A
8.5.5 | High pressure lamps | N/A
| Explosion test | : | N/A
8.5.5.3 | Glass particles dimensions (mm) | : | N/A
8.6 | Stability of equipment | N/A
8.6.1 | General | N/A
| Instructional safeguard | : | N/A
8.6.2 | Static stability | N/A
8.6.2.2 | Static stability test | : | N/A
8.6.2.3 | Downward force test | N/A

Page 19 of 57 | Report No. 2510B0397SHA-001

IEC 62368-1

Clause | Requirement + Test | Result - Remark | Verdict

TRF No. IEC62368_1E

8.6.3 | Relocation stability | N/A
| Wheels diameter (mm) | : | ⎯
| Tilt test | N/A
8.6.4 | Glass slide test | N/A
8.6.5 | Horizontal force test | : | N/A
8.7 | Equipment mounted to wall, ceiling or other structure | N/A
8.7.1 | Mount means type | : | N/A
8.7.2 | Test methods | N/A
| Test 1, additional downwards force (N) | : | N/A
| Test 2, number of attachment points and test force (N) | : | N/A
| Test 3 Nominal diameter (mm) and applied torque (Nm) | : | N/A
8.8 | Handles strength | N/A
8.8.1 | General | N/A
8.8.2 | Handle strength test | N/A
| Number of handles | : | ⎯
| Force applied (N) | : | ⎯
8.9 | Wheels or casters attachment requirements | N/A
8.9.2 | Pull test | N/A
8.10 | Carts, stands and similar carriers | N/A
8.10.1 | General | N/A
8.10.2 | Marking and instructions | : | N/A
8.10.3 | Cart, stand or carrier loading test | N/A
| Loading force applied (N) | : | N/A
8.10.4 | Cart, stand or carrier impact test | N/A
8.10.5 | Mechanical stability | N/A
| Force applied (N) | : | ⎯
8.10.6 | Thermoplastic temperature stability | N/A
8.11 | Mounting means for slide-rail mounted equipment (SRME) | N/A
8.11.1 | General | N/A
8.11.2 | Requirements for slide rails | N/A
| Instructional Safeguard | : | N/A
8.11.3 | Mechanical strength test | N/A
8.11.3.1 | Downward force test, force (N) applied | : | N/A

Page 20 of 57 | Report No. 2510B0397SHA-001

IEC 62368-1

Clause | Requirement + Test | Result - Remark | Verdict

TRF No. IEC62368_1E

8.11.3.2 | Lateral push force test | N/A
8.11.3.3 | Integrity of slide rail end stops | N/A
8.11.4 | Compliance | N/A
8.12 | Telescoping or rod antennas | N/A
| Button/ball diameter (mm) | : | ⎯
9 | THERMAL BURN INJURY | P
9.2 | Thermal energy source classifications | P
9.3 | Touch temperature limits | P
9.3.1 | Touch temperatures of accessible parts | : | (See appended table) | P
9.3.2 | Test method and compliance | | P
9.4 | Safeguards against thermal energy sources | | N/A
9.5 | Requirements for safeguards | | N/A
9.5.1 | Equipment safeguard | | N/A
9.5.2 | Instructional safeguard | : | | N/A
9.6 | Requirements for wireless power transmitters | | N/A
9.6.1 | General | | N/A
9.6.2 | Specification of the foreign objects | | N/A
9.6.3 | Test method and compliance | : | (See appended table 9.6) | N/A
10 | RADIATION | N/A
10.2 | Radiation energy source classification | N/A
10.2.1 | General classification | | N/A
| Lasers | : | | ⎯
| Lamps and lamp systems | : | | ⎯
| Image projectors | : | | ⎯
| X-Ray | : | | ⎯
| Personal music player | : | | ⎯
10.3 | Safeguards against laser radiation | | N/A
| The standard(s) equipment containing laser(s) comply | : | | N/A
10.4 Safeguards against optical radiation from lamps and lamp systems (including | LED types) | | N/A
10.4.1 | General requirements | | N/A
| Instructional safeguard provided for accessible radiation level needs to exceed | | N/A

Page 21 of 57 | Report No. 2510B0397SHA-001

IEC 62368-1

Clause | Requirement + Test | Result - Remark | Verdict

TRF No. IEC62368_1E

| Risk group marking and location | : | | N/A
| Information for safe operation and installation | | N/A
10.4.2 | Requirements for enclosures | | N/A
| UV radiation exposure | : | (See Annex C) | N/A
10.4.3 | Instructional safeguard | : | | N/A
10.5 | Safeguards against X-radiation | | N/A
10.5.1 | Requirements | | N/A
| Instructional safeguard for skilled persons | : | | ⎯
10.5.3 | Maximum radiation (pA/kg) | : | (See appended tables B.3 & B.4) | ⎯
10.6 | Safeguards against acoustic energy sources | | N/A
10.6.1 | General | | N/A
10.6.2 | Classification | | N/A
| Acoustic output LAeq,T, dB(A) | : | | N/A
| Unweighted RMS output voltage (mV) | : | | N/A
| Digital output signal (dBFS) | : | | N/A
10.6.3 | Requirements for dose-based systems | | N/A
10.6.3.1 | General requirements | | N/A
10.6.3.2 | Dose-based warning and automatic decrease | | N/A
10.6.3.3 | Exposure-based warning and requirements | | N/A
| 30 s integrated exposure level (MEL30) | : | | N/A
| Warning for MEL ≥ 100 dB(A) | : | | N/A
10.6.4 | Measurement methods | | N/A
10.6.5 | Protection of persons | | N/A
| Instructional safeguards | : | | N/A
10.6.6 | Requirements for listening devices (headphones, earphones, etc.) | | N/A
10.6.6.1 | Corded listening devices with analogue input | | N/A
| Listening device input voltage (mV) | : | | N/A
10.6.6.2 | Corded listening devices with digital input | | N/A
| Max. acoustic output LAeq,T, dB(A) | : | | N/A
10.6.6.3 | Cordless listening devices | | N/A
| Max. acoustic output LAeq,T, dB(A) | : | | N/A

Page 22 of 57 | Report No. 2510B0397SHA-001

IEC 62368-1

Clause | Requirement + Test | Result - Remark | Verdict

TRF No. IEC62368_1E

B | NORMAL OPERATING CONDITION TESTS, ABNORMAL OPERATING CONDITION TESTS AND SINGLE FAULT CONDITION TESTS | P
B.1 | General | P
B.1.5 | Temperature measurement conditions | (See appended table B.1.5) | P
B.2 | Normal operating conditions | | P
B.2.1 | General requirements | : | (See Test Item Particulars and appended test tables) | P
| Audio Amplifiers and equipment with audio amplifiers | : | (See Annex E) | N/A
B.2.3 | Supply voltage and tolerances | | N/A
B.2.5 | Input test | : | (See appended table B.2.5) | P
B.3 | Simulated abnormal operating conditions | | P
B.3.1 | General | | P
B.3.2 | Covering of ventilation openings | | N/A
| Instructional safeguard | : | | N/A
B.3.3 | DC mains polarity test | | N/A
B.3.4 | Setting of voltage selector | | N/A
B.3.5 | Maximum load at output terminals | | N/A
B.3.6 | Reverse battery polarity | | N/A
B.3.7 | Audio amplifier abnormal operating conditions | | N/A
B.3.8 | Safeguards functional during and after abnormal operating conditions | : | During an abnormal operating condition that does not lead to a single fault condition, all safeguards are remained effective. After restoration of normal operating conditions, all safeguards are compliant with applicable requirements. | P
B.4 | Simulated single fault conditions | | P
B.4.1 | General | | P
B.4.2 | Temperature controlling device | | N/A
B.4.3 | Blocked motor test | | P
B.4.4 | Functional insulation | | P
B.4.4.1 | Short circuit of clearances for functional insulation | | P

Page 23 of 57 | Report No. 2510B0397SHA-001

IEC 62368-1

Clause | Requirement + Test | Result - Remark | Verdict

TRF No. IEC62368_1E

B.4.4.2 | Short circuit of creepage distances for functional insulation | | P
B.4.4.3 | Short circuit of functional insulation on coated printed boards | | N/A
B.4.5 | Short-circuit and interruption of electrodes in tubes and semiconductors | | P
B.4.6 | Short circuit or disconnection of passive components | | P
B.4.7 | Continuous operation of components | | N/A
B.4.8 | Compliance during and after single fault conditions | : | (See appended table B.4) | P
B.4.9 | Battery charging and discharging under single fault conditions | (See Annex M) | P
C | UV RADIATION | | N/A
C.1 | Protection of materials in equipment from UV radiation | | N/A
C.1.2 | Requirements | | N/A
C.1.3 | Test method | | N/A
C.2 | UV light conditioning test | | N/A
C.2.1 | Test apparatus | : | | N/A
C.2.2 | Mounting of test samples | | N/A
C.2.3 | Carbon-arc light-exposure test | | N/A
C.2.4 | Xenon-arc light-exposure test | | N/A
D | TEST GENERATORS | | N/A
D.1 | Impulse test generators | | N/A
D.2 | Antenna interface test generator | | N/A
D.3 | Electronic pulse generator | | N/A
E | TEST CONDITIONS FOR EQUIPMENT CONTAINING AUDIO AMPLIFIERS | | N/A
E.1 | Electrical energy source classification for audio signals | | N/A
| Maximum non-clipped output power (W) | : | | ⎯
| Rated load impedance (Ω) | : | | ⎯
| Open-circuit output voltage (V) | : | | ⎯
| Instructional safeguard | : | See Clause F.5 | ⎯
E.2 | Audio amplifier normal operating conditions | | N/A
| Audio signal source type | : | | ⎯
| Audio output power (W) | : | | ⎯
| Audio output voltage (V) | : | | ⎯
| Rated load impedance (Ω) | : | | ⎯

Page 24 of 57 | Report No. 2510B0397SHA-001

IEC 62368-1

Clause | Requirement + Test | Result - Remark | Verdict

TRF No. IEC62368_1E

| Requirements for temperature measurement | (See Table B.1.5) | N/A
E.3 | Audio amplifier abnormal operating conditions | (See Table B.3, B.4) | N/A
F | EQUIPMENT MARKINGS, INSTRUCTIONS, AND INSTRUCTIONAL SAFEGUARDS | | P
F.1 | General | | P
| Language | : | In English. | ⎯
F.2 | Letter symbols and graphical symbols | | P
F.2.1 | Letter symbols according to IEC60027-1 | | P
F.2.2 | Graphic symbols according to IEC, ISO or manufacturer specific | | P
F.3 | Equipment markings | | P
F.3.1 | Equipment marking locations | | P
F.3.2 | Equipment identification markings | | P
F.3.2.1 | Manufacturer identification | : | See marking page | P
F.3.2.2 | Model identification | : | See marking page | P
F.3.3 | Equipment rating markings | | P
F.3.3.1 | Equipment with direct connection to mains | | N/A
F.3.3.2 | Equipment without direct connection to mains | | P
F.3.3.3 | Nature of the supply voltage | : | See marking page | P
F.3.3.4 | Rated voltage | : | See marking page | P
F.3.3.5 | Rated frequency | : | | N/A
F.3.3.6 | Rated current or rated power | : | See marking page | P
F.3.3.7 | Equipment with multiple supply connections | | N/A
F.3.4 | Voltage setting device | | N/A
F.3.5 | Terminals and operating devices | | N/A
F.3.5.1 | Mains appliance outlet and socket-outlet markings | : | | N/A
F.3.5.2 | Switch position identification marking | : | | N/A
F.3.5.3 | Replacement fuse identification and rating markings | : | | N/A
| Instructional safeguards for neutral fuse | : | | N/A
F.3.5.4 | Replacement battery identification marking | : | | N/A
F.3.5.5 | Neutral conductor terminal | | N/A
F.3.5.6 | Terminal marking location | | N/A
F.3.6 | Equipment markings related to equipment classification | | N/A
F.3.6.1 | Class I equipment | | N/A

Page 25 of 57 | Report No. 2510B0397SHA-001

IEC 62368-1

Clause | Requirement + Test | Result - Remark | Verdict

TRF No. IEC62368_1E

F.3.6.1.1 | Protective earthing conductor terminal | : | | N/A
F.3.6.1.2 | Protective bonding conductor terminals | : | | N/A
F.3.6.2 | Equipment class marking | : | | N/A
F.3.6.3 | Functional earthing terminal marking | : | | N/A
F.3.7 | Equipment IP rating marking | : | IPX0 | N/A
F.3.8 | External power supply output marking | : | | N/A
F.3.9 | Durability, legibility and permanence of marking | | P
F.3.10 | Test for permanence of markings | | P
F.4 | Instructions | | P
| a) Information prior to installation and initial use | | P
| b) Equipment for use in locations where children not likely to be present | | P
| c) Instructions for installation and interconnection | | N/A
| d) Equipment intended for use only in restricted access area | | N/A
| e) Equipment intended to be fastened in place | | N/A
| f) Instructions for audio equipment terminals | | N/A
| g) Protective earthing used as a safeguard | | N/A
| h) Protective conductor current exceeding ES2 limits | | N/A
| i) Graphic symbols used on equipment | | P
| j) Permanently connected equipment not provided with all-pole mains switch | | N/A
| k) Replaceable components or modules providing safeguard function | | N/A
| l) Equipment containing insulating liquid | | N/A
| m) Installation instructions for outdoor equipment | | N/A
F.5 | Instructional safeguards | | P
G | COMPONENTS | | P
G.1 | Switches | | N/A
G.1.1 | General | | N/A
G.1.2 | Ratings, endurance, spacing, maximum load | | N/A
G.1.3 | Test method and compliance | | N/A
G.2 | Relays | | N/A
G.2.1 | Requirements | | N/A
G.2.2 | Overload test | | N/A

Page 26 of 57 | Report No. 2510B0397SHA-001

IEC 62368-1

Clause | Requirement + Test | Result - Remark | Verdict

TRF No. IEC62368_1E

G.2.3 | Relay controlling connectors supplying power to other equipment | | N/A
G.2.4 | Test method and compliance | | N/A
G.3 | Protective devices | | P
G.3.1 | Thermal cut-offs | | N/A
| Thermal cut-outs separately approved according to IEC 60730 with conditions indicated in a) & b) | | N/A
| Thermal cut-outs tested as part of the equipment as indicated in c) | | N/A
G.3.1.2 | Test method and compliance | | N/A
G.3.2 | Thermal links | | N/A
G.3.2.1 | a) Thermal links tested separately according to IEC 60691 with specifics | | N/A
| b) Thermal links tested as part of the equipment | | N/A
G.3.2.2 | Test method and compliance | | N/A
G.3.3 | PTC thermistors | | P
G.3.4 | Overcurrent protection devices | | N/A
G.3.5 | Safeguards components not mentioned in G.3.1 to G.3.4 | | N/A
G.3.5.1 | Non-resettable devices suitably rated and marking provided | | N/A
G.3.5.2 | Single faults conditions | : | (See appended table B.4) | N/A
G.4 | Connectors | | N/A
G.4.1 | Spacings | | N/A
G.4.2 | Mains connector configuration | : | | N/A
G.4.3 | Plug is shaped that insertion into mains socket-outlets or appliance coupler is unlikely | | N/A
G.5 | Wound components | | P
G.5.1 | Wire insulation in wound components | | N/A
G.5.1.2 | Protection against mechanical stress | | N/A
G.5.2 | Endurance test | | N/A
G.5.2.1 | General test requirements | | N/A
G.5.2.2 | Heat run test | | N/A
| Test time (days per cycle) | : | | ⎯
| Test temperature (°C) | : | | ⎯
G.5.2.3 | Wound components supplied from the mains | | N/A
G.5.2.4 | No insulation breakdown | | N/A

Page 27 of 57 | Report No. 2510B0397SHA-001

IEC 62368-1

Clause | Requirement + Test | Result - Remark | Verdict

TRF No. IEC62368_1E

G.5.3 | Transformers | | N/A
G.5.3.1 | Compliance method | : | | N/A
| Position | : | | N/A
| Method of protection | : | | N/A
G.5.3.2 | Insulation | | N/A
| Protection from displacement of windings | : | | ⎯
G.5.3.3 | Transformer overload tests | | N/A
G.5.3.3.1 | Test conditions | | N/A
G.5.3.3.2 | Winding temperatures | | N/A
G.5.3.3.3 | Winding temperatures - alternative test method | | N/A
G.5.3.4 | Transformers using FIW | | N/A
G.5.3.4.1 | General | | N/A
| FIW wire nominal diameter | : | | ⎯
G.5.3.4.2 | Transformers with basic insulation only | | N/A
G.5.3.4.3 | Transformers with double insulation or reinforced insulation | : | | N/A
G.5.3.4.4 | Transformers with FIW wound on metal or ferrite core | | N/A
G.5.3.4.5 | Thermal cycling test and compliance | | N/A
G.5.3.4.6 | Partial discharge test | | N/A
G.5.3.4.7 | Routine test | | N/A
G.5.4 | Motors | | P
G.5.4.1 | General requirements | | P
G.5.4.2 | Motor overload test conditions | | P
G.5.4.3 | Running overload test | | P
G.5.4.4.2 | Locked-rotor overload test | | P
| Test duration (days) | : | | ⎯
G.5.4.5 | Running overload test for DC motors | | N/A
G.5.4.5.2 | Tested in the unit | | N/A
G.5.4.5.3 | Alternative method | | N/A
G.5.4.6 | Locked-rotor overload test for DC motors | | P
G.5.4.6.2 | Tested in the unit | | P
| Maximum Temperature | : | 73.5°C | P
G.5.4.6.3 | Alternative method | | N/A
G.5.4.7 | Motors with capacitors | | N/A
G.5.4.8 | Three-phase motors | | N/A

Page 28 of 57 | Report No. 2510B0397SHA-001

IEC 62368-1

Clause | Requirement + Test | Result - Remark | Verdict

TRF No. IEC62368_1E

G.5.4.9 | Series motors | N/A
| Operating voltage | : | ⎯
G.6 | Wire Insulation | N/A
G.6.1 | General | N/A
G.6.2 | Enamelled winding wire insulation | N/A
G.7 | Mains supply cords | N/A
G.7.1 | General requirements | N/A
| Type | : | ⎯
G.7.2 | Cross sectional area (mm² or AWG) | : | N/A
G.7.3 | Cord anchorages and strain relief for non-detachable power supply cords | N/A
G.7.3.2 | Cord strain relief | N/A
G.7.3.2.1 | Requirements | N/A
| Strain relief test force (N) | : | N/A
G.7.3.2.2 | Strain relief mechanism failure | N/A
G.7.3.2.3 | Cord sheath or jacket position, distance (mm) ......: | N/A
G.7.3.2.4 | Strain relief and cord anchorage material | N/A
G.7.4 | Cord Entry | N/A
G.7.5 | Non-detachable cord bend protection | N/A
G.7.5.1 | Requirements | N/A
G.7.5.2 | Test method and compliance | N/A
| Overall diameter or minor overall dimension, D (mm) | : | ⎯
| Radius of curvature after test (mm) | : | ⎯
G.7.6 | Supply wiring space | N/A
G.7.6.1 | General requirements | N/A
G.7.6.2 | Stranded wire | N/A
G.7.6.2.1 | Requirements | N/A
G.7.6.2.2 | Test with 8 mm strand | N/A
G.8 | Varistors | N/A
G.8.1 | General requirements | N/A
G.8.2 | Safeguards against fire | N/A
G.8.2.1 | General | N/A
G.8.2.2 | Varistor overload test | N/A
G.8.2.3 | Temporary overvoltage test | N/A
G.9 | Integrated circuit (IC) current limiters | N/A

Page 29 of 57 | Report No. 2510B0397SHA-001

IEC 62368-1

Clause | Requirement + Test | Result - Remark | Verdict

TRF No. IEC62368_1E

G.9.1 | Requirements | | N/A
| IC limiter output current (max. 5A) | : | | ⎯
| Manufacturers’ defined drift | : | | ⎯
G.9.2 | Test Program | | N/A
G.9.3 | Compliance | | N/A
G.10 | Resistors | | N/A
G.10.1 | General | | N/A
G.10.2 | Conditioning | | N/A
G.10.3 | Resistor test | | N/A
G.10.4 | Voltage surge test | | N/A
G.10.5 | Impulse test | | N/A
G.10.6 | Overload test | | N/A
G.11 | Capacitors and RC units | | N/A
G.11.1 | General requirements | | N/A
G.11.2 | Conditioning of capacitors and RC units | | N/A
G.11.3 | Rules for selecting capacitors | | N/A
G.12 | Optocouplers | | N/A
| Optocouplers comply with IEC 60747-5-5 with specifics | | N/A
| Type test voltage Vini,a | : | | ⎯
| Routine test voltage, Vini, b | : | | ⎯
G.13 | Printed boards | | P
G.13.1 | General requirements | | P
G.13.2 | Uncoated printed boards | | P
G.13.3 | Coated printed boards | | N/A
G.13.4 | Insulation between conductors on the same inner surface | | N/A
G.13.5 | Insulation between conductors on different surfaces | | N/A
| Distance through insulation | : | | N/A
| Number of insulation layers (pcs) | : | | ⎯
G.13.6 | Tests on coated printed boards | | N/A
G.13.6.1 | Sample preparation and preliminary inspection | | N/A
G.13.6.2 | Test method and compliance | | N/A
G.14 | Coating on components terminals | | N/A
G.14.1 | Requirements | : | (See Clause G.13) | N/A
G.15 | Pressurized liquid filled components | | N/A

Page 30 of 57 | Report No. 2510B0397SHA-001

IEC 62368-1

Clause | Requirement + Test | Result - Remark | Verdict

TRF No. IEC62368_1E

G.15.1 | Requirements | N/A
G.15.2 | Test methods and compliance | N/A
G.15.2.1 | Hydrostatic pressure test | N/A
G.15.2.2 | Creep resistance test | N/A
G.15.2.3 | Tubing and fittings compatibility test | N/A
G.15.2.4 | Vibration test | N/A
G.15.2.5 | Thermal cycling test | N/A
G.15.2.6 | Force test | N/A
G.15.3 | Compliance | N/A
G.16 | IC including capacitor discharge function (ICX) | N/A
G.16.1 | Condition for fault tested is not required | N/A
| ICX with associated circuitry tested in equipment | N/A
| ICX tested separately | N/A
G.16.2 | Tests | N/A
| Smallest capacitance and smallest resistance specified by ICX manufacturer for impulse test .....: | ⎯
| Mains voltage that impulses to be superimposed on | : | ⎯
| Largest capacitance and smallest resistance for ICX tested by itself for 10000 cycles test | : | ⎯
G.16.3 | Capacitor discharge test | : | N/A
H | CRITERIA FOR TELEPHONE RINGING SIGNALS | N/A
H.1 | General | N/A
H.2 | Method A | N/A
H.3 | Method B | N/A
H.3.1 | Ringing signal | N/A
H.3.1.1 | Frequency (Hz) | : | ⎯
H.3.1.2 | Voltage (V) | : | ⎯
H.3.1.3 | Cadence; time (s) and voltage (V) | : | ⎯
H.3.1.4 | Single fault current (mA): | : | ⎯
H.3.2 | Tripping device and monitoring voltage | N/A
H.3.2.1 | Conditions for use of a tripping device or a monitoring voltage | N/A
H.3.2.2 | Tripping device | N/A
H.3.2.3 | Monitoring voltage (V) | : | N/A

Page 31 of 57 | Report No. 2510B0397SHA-001

IEC 62368-1

Clause | Requirement + Test | Result - Remark | Verdict

TRF No. IEC62368_1E

J | INSULATED WINDING WIRES FOR USE WITHOUT INTERLEAVED INSULATION | N/A
J.1 | General | N/A
| Winding wire insulation | : | | ⎯
| Solid round winding wire, diameter (mm) | : | | N/A
| Solid square and rectangular (flatwise bending) winding wire, cross-sectional area (mm² ) | : | | N/A
J.2/J.3 | Tests and Manufacturing | (See separate test report) | ⎯
K | SAFETY INTERLOCKS | | N/A
K.1 | General requirements | | N/A
| Instructional safeguard | : | | N/A
K.2 | Components of safety interlock safeguard mechanism | | N/A
K.3 | Inadvertent change of operating mode | | N/A
K.4 | Interlock safeguard override | | N/A
K.5 | Fail-safe | | N/A
K.5.1 | Under single fault condition | | N/A
K.6 | Mechanically operated safety interlocks | | N/A
K.6.1 | Endurance requirement | | N/A
K.6.2 | Test method and compliance | : | | N/A
K.7 | Interlock circuit isolation | | N/A
K.7.1 | Separation distance for contact gaps & interlock circuit elements | | N/A
| In circuit connected to mains, separation distance for contact gaps (mm) | : | | N/A
| In circuit isolated from mains, separation distance for contact gaps (mm) | : | | N/A
| Electric strength test before and after the test of K.7.2 | : | (See appended table 5.4.9) | N/A
K.7.2 | Overload test, Current (A) | : | | N/A
K.7.3 | Endurance test | | N/A
K.7.4 | Electric strength test | | N/A
L | DISCONNECT DEVICES | | N/A
L.1 | General requirements | | N/A
L.2 | Permanently connected equipment | | N/A
L.3 | Parts that remain energized | | N/A
L.4 | Single-phase equipment | | N/A
L.5 | Three-phase equipment | | N/A
L.6 | Switches as disconnect devices | | N/A

Page 32 of 57 | Report No. 2510B0397SHA-001

IEC 62368-1

Clause | Requirement + Test | Result - Remark | Verdict

TRF No. IEC62368_1E

L.7 | Plugs as disconnect devices | | N/A
L.8 | Multiple power sources | | N/A
| Instructional safeguard | : | | N/A
M | EQUIPMENT CONTAINING BATTERIES AND THEIR PROTECTION CIRCUITS | | P
M.1 | General requirements | | P
M.2 | Safety of batteries and their cells | | P
M.2.1 | Batteries and their cells comply with relevant IEC standards | : | (see appended table 4.1.2) | P
M.3 | Protection circuits for batteries provided within the equipment | | P
M.3.1 | Requirements | | P
M.3.2 | Test method | | P
| Overcharging of a rechargeable battery | IEC 62133 approved battery pack used, and were considered to meet this requirement. | P
| Excessive discharging | Evaluated in approved (IEC 62133 approved), and were considered to meet this requirement. | P
| Unintentional charging of a non-rechargeable battery | | N/A
| Reverse charging of a rechargeable battery | | P
M.3.3 | Compliance | All internal batteries comply with IEC 62133 were considered to meet this requirement. | P
M.4 | Additional safeguards for equipment containing a portable secondary lithium battery | | P
M.4.1 | General | | P
M.4.2 | Charging safeguards | | P
M.4.2.1 | Requirements | | P
M.4.2.2 | Compliance | : | (See appended table M.4.2) | P
M.4.3 | Fire enclosure | : | | N/A
M.4.4 | Drop test of equipment containing a secondary lithium battery | | N/A
M.4.4.2 | Preparation and procedure for the drop test | | N/A
M.4.4.3 | Drop, Voltage on reference and dropped batteries (V); voltage difference during 24 h period (%): .....: | | N/A
M.4.4.4 | Check of the charge/discharge function | | N/A
M.4.4.5 | Charge / discharge cycle test | | N/A
M.4.4.6 | Compliance | | N/A

Page 33 of 57 | Report No. 2510B0397SHA-001

IEC 62368-1

Clause | Requirement + Test | Result - Remark | Verdict

TRF No. IEC62368_1E

M.5 | Risk of burn due to short-circuit during carrying | N/A
M.5.1 | Requirement | | N/A
M.5.2 | Test method and compliance | | N/A
M.6 | Safeguards against short-circuits | | P
M.6.1 | External and internal faults | Comply with IEC 62133-2:2017 | P
M.6.2 | Compliance | | P
M.7 | Risk of explosion from lead acid and NiCd batteries | | N/A
M.7.1 | Ventilation preventing explosive gas concentration | | N/A
| Calculated hydrogen generation rate | : | | N/A
M.7.2 | Test method and compliance | | N/A
| Minimum air flow rate, Q (m³ /h) | : | | N/A
M.7.3 | Ventilation tests | | N/A
M.7.3.1 | General | | N/A
M.7.3.2 | Ventilation test – alternative 1 | | N/A
| Hydrogen gas concentration (%) | : | | N/A
M.7.3.3 | Ventilation test – alternative 2 | | N/A
| Obtained hydrogen generation rate | : | | N/A
M.7.3.4 | Ventilation test – alternative 3 | | N/A
| Hydrogen gas concentration (%) | : | | N/A
M.7.4 | Marking | : | | N/A
M.8 | Protection against internal ignition from external spark sources of batteries with aqueous electrolyte | | N/A
M.8.1 | General | | N/A
M.8.2 | Test method | | N/A
M.8.2.1 | General | | N/A
M.8.2.2 | Estimation of hypothetical volume VZ (m³ /s) | : | | ⎯
M.8.2.3 | Correction factors | : | | ⎯
M.8.2.4 | Calculation of distance d (mm) | : | | ⎯
M.9 | Preventing electrolyte spillage | | N/A
M.9.1 | Protection from electrolyte spillage | | N/A
M.9.2 | Tray for preventing electrolyte spillage | | N/A
M.10 | Instructions to prevent reasonably foreseeable misuse | | N/A
| Instructional safeguard | : | | N/A
N | ELECTROCHEMICAL POTENTIALS | | N/A
| Material(s) used | : | | ⎯

Page 34 of 57 | Report No. 2510B0397SHA-001

IEC 62368-1

Clause | Requirement + Test | Result - Remark | Verdict

TRF No. IEC62368_1E

O | MEASUREMENT OF CREEPAGE DISTANCES AND CLEARANCES | N/A
| Value of X (mm) | : | | ⎯
P | SAFEGUARDS AGAINST CONDUCTIVE OBJECTS | | N/A
P.1 | General | | N/A
P.2 | Safeguards against entry or consequences of entry of a foreign object | | N/A
P.2.1 | General | | N/A
P.2.2 | Safeguards against entry of a foreign object | | N/A
| Location and Dimensions (mm) | : | | ⎯
P.2.3 | Safeguards against the consequences of entry of a foreign object | | N/A
P.2.3.1 | Safeguard requirements | | N/A
| The ES3 and PS3 keep-out volume in Figure P.3 not applicable to transportable equipment | | N/A
| Transportable equipment with metalized plastic parts | : | | N/A
P.2.3.2 | Consequence of entry test | : | | N/A
P.3 | Safeguards against spillage of internal liquids | | N/A
P.3.1 | General | | N/A
P.3.2 | Determination of spillage consequences | | N/A
P.3.3 | Spillage safeguards | | N/A
P.3.4 | Compliance | | N/A
P.4 | Metallized coatings and adhesives securing parts | | N/A
P.4.1 | General | | N/A
P.4.2 | Tests | | N/A
| Conditioning, TC (°C) | : | | ⎯
| Duration (weeks) | : | | ⎯
Q | CIRCUITS INTENDED FOR INTERCONNECTION WITH BUILDING WIRING | | N/A
Q.1 | Limited power sources | | N/A
Q.1.1 | Requirements | | N/A
| a) Inherently limited output | | N/A
| b) Impedance limited output | | N/A
| c) Regulating network limited output | | N/A
| d) Overcurrent protective device limited output | | N/A
| e) IC current limiter complying with G.9 | | N/A
Q.1.2 | Test method and compliance | : | (See appended table Q.1) | N/A

Page 35 of 57 | Report No. 2510B0397SHA-001

IEC 62368-1

Clause | Requirement + Test | Result - Remark | Verdict

TRF No. IEC62368_1E

| Current rating of overcurrent protective device (A) | : | N/A
Q.2 | Test for external circuits – paired conductor cable | N/A
| Maximum output current (A) | : | N/A
| Current limiting method | : | ⎯
R | LIMITED SHORT CIRCUIT TEST | N/A
R.1 | General | N/A
R.2 | Test setup | N/A
| Overcurrent protective device for test | : | ⎯
R.3 | Test method | N/A
| Cord/cable used for test | : | ⎯
R.4 | Compliance | N/A
S | TESTS FOR RESISTANCE TO HEAT AND FIRE | N/A
S.1 | Flammability test for fire enclosures and fire barrier materials of equipment where the steady state power does not exceed 4 000 W | N/A
| Samples, material | : | ⎯
| Wall thickness (mm) | : | ⎯
| Conditioning (°C) | : | ⎯
| Test flame according to IEC 60695-11-5 with conditions as set out | N/A
| - Material not consumed completely | N/A
| - Material extinguishes within 30s | N/A
| - No burning of layer or wrapping tissue | N/A
S.2 | Flammability test for fire enclosure and fire barrier integrity | N/A
| Samples, material | : | ⎯
| Wall thickness (mm) | : | ⎯
| Conditioning (°C) | : | ⎯
S.3 | Flammability test for the bottom of a fire enclosure | N/A
S.3.1 | Mounting of samples | N/A
S.3.2 | Test method and compliance | N/A
| Mounting of samples | : | ⎯
| Wall thickness (mm) | : | ⎯
S.4 | Flammability classification of materials | N/A
S.5 | Flammability test for fire enclosure materials of equipment with a steady state power exceeding 4 000 W | N/A

Page 36 of 57 | Report No. 2510B0397SHA-001

IEC 62368-1

Clause | Requirement + Test | Result - Remark | Verdict

TRF No. IEC62368_1E

| Samples, material | : | | ⎯
| Wall thickness (mm) | : | | ⎯
| Conditioning (°C) | : | | ⎯
T | MECHANICAL STRENGTH TESTS | | N/A
T.1 | General | | N/A
T.2 | Steady force test, 10 N | : | (See appended table T.2) | N/A
T.3 | Steady force test, 30 N | : | (See appended table T.3) | N/A
T.4 | Steady force test, 100 N | : | (See appended table T.4) | N/A
T.5 | Steady force test, 250 N | : | (See appended table T.5) | N/A
T.6 | Enclosure impact test | (See appended table T.6) | N/A
| Fall test | | N/A
| Swing test | | N/A
T.7 | Drop test | : | (See appended table T.7) | N/A
T.8 | Stress relief test | : | (See appended table T.8) | N/A
T.9 | Glass Impact Test | : | (See appended table T.9) | N/A
T.10 | Glass fragmentation test | | N/A
| Number of particles counted | : | | N/A
T.11 | Test for telescoping or rod antennas | | N/A
| Torque value (Nm) | : | | N/A
U MECHANICAL STRENGTH OF CATHODE RAY TUBES (CRT) AND PROTECTION | AGAINST THE EFFECTS OF IMPLOSION | | N/A
U.1 | General | | N/A
| Instructional safeguard : | | N/A
U.2 | Test method and compliance for non-intrinsically protected CRTs | | N/A
U.3 | Protective screen | | N/A
V | DETERMINATION OF ACCESSIBLE PARTS | | N/A
V.1 | Accessible parts of equipment | | N/A
V.1.1 | General | | N/A
V.1.2 | Surfaces and openings tested with jointed test probes | | N/A
V.1.3 | Openings tested with straight unjointed test probes | | N/A
V.1.4 | Plugs, jacks, connectors tested with blunt probe | | N/A
V.1.5 | Slot openings tested with wedge probe | | N/A
V.1.6 | Terminals tested with rigid test wire | | N/A
V.2 | Accessible part criterion | | N/A

Page 37 of 57 | Report No. 2510B0397SHA-001

IEC 62368-1

Clause | Requirement + Test | Result - Remark | Verdict

TRF No. IEC62368_1E

X ALTERNATIVE METHOD FOR DETERMINING CLEARANCES FOR INSULATION IN | CIRCUITS CONNECTED TO AN AC MAINS NOT EXCEEDING 420 V PEAK (300 V RMS) | N/A
| Clearance | : | (See appended table X) | N/A
Y | CONSTRUCTION REQUIREMENTS FOR OUTDOOR ENCLOSURES | | N/A
Y.1 | General | | N/A
Y.2 | Resistance to UV radiation | | N/A
Y.3 | Resistance to corrosion | | N/A
Y.3 | Resistance to corrosion | | N/A
Y.3.1 | Metallic parts of outdoor enclosures are resistant to effects of water-borne contaminants by | : | | N/A
Y.3.2 | Test apparatus | | N/A
Y.3.3 | Water – saturated sulphur dioxide atmosphere | | N/A
Y.3.4 | Test procedure | : | | N/A
Y.3.5 | Compliance | | N/A
Y.4 | Gaskets | | N/A
Y.4.1 | General | | N/A
Y.4.2 | Gasket tests | | N/A
Y.4.3 | Tensile strength and elongation tests | | N/A
| Alternative test methods | : | | N/A
Y.4.4 | Compression test | | N/A
Y.4.5 | Oil resistance | | N/A
Y.4.6 | Securing means | (See Annex P.4) | N/A
Y.5 | Protection of equipment within an outdoor enclosure | | N/A
Y.5.1 | General | | N/A
Y.5.2 | Protection from moisture | | N/A
| Relevant tests of IEC 60529 or Y.5.3 | : | | N/A
Y.5.3 | Water spray test | | N/A
Y.5.4 | Protection from plants and vermin | | N/A
Y.5.5 | Protection from excessive dust | | N/A
Y.5.5.1 | General | | N/A
Y.5.5.2 | IP5X equipment | | N/A
Y.5.5.3 | IP6X equipment | | N/A
Y.6 | Mechanical strength of enclosures | | N/A
Y.6.1 | General | | N/A
Y.6.2 | Impact test | : | (See Table T.6) | N/A

Page 38 of 57 | Report No. 2510B0397SHA-001

IEC 62368-1

Clause | Requirement + Test | Result - Remark | Verdict

TRF No. IEC62368_1E

5.2 | TABLE: Classification of electrical energy sources | P
Supply Voltage | Location (e.g. circuit designation) | Test conditions | Parameters | ES Class
U (Vdc) | I (mA) | Type¹⁾ | Additional Info 2)
5 Vdc | Input circuits | Normal | 5 Vdc | -- | SS | DC | ES1
| | Abnormal | 5 Vdc | -- | SS | DC
| | Single fault –SC | 5 Vdc | -- | SS | DC
3.7 Vdc | Battery supply | Normal | 3.7 Vdc | -- | SS | DC | ES1
| | Abnormal | 3.7 Vdc | -- | SS | DC
| | Single fault –SC | 3.7 Vdc | -- | SS | DC
Supplementary information: SC= short circuit
1) Type: Steady state (SS), Capacitance (CP), Single pulse (SP), Repetitive pulses (RP), etc.
2) Additional Info: Frequency, Pulse duration, Pulse off time, Capacitance value, etc.
5.4.1.8 | TABLE: Working voltage measurement | N/A
Location | RMS voltage (V) | Peak voltage (V) | Frequency (Hz) | Comments

Supplementary information:

5.4.1.10.2 | TABLE: Vicat softening temperature of thermoplastics | N/A
Method | : | ISO 306 / B50 | ⎯
Object/ Part No./Material | Manufacturer/trademark | Thickness (mm) | T softening (°C)

Supplementary information:

5.4.1.10.3 | TABLE: Ball pressure test of thermoplastics | N/A
Allowed impression diameter (mm) | : | ≤ 2 mm | ⎯
Object/Part No./Material | Manufacturer/trademark | Thickness (mm) | Test temperature (°C) | Impression diameter (mm)

Supplementary information:

Page 39 of 57 | Report No. 2510B0397SHA-001

IEC 62368-1

Clause | Requirement + Test | Result - Remark | Verdict

TRF No. IEC62368_1E

5.4.2, 5.4.3 | TABLE: Minimum Clearances/Creepage distance | N/A
Clearance (cl) and creepage distance (cr) at/of/between: | Up (V) | Urms (V) | Freq 1) (Hz) | Required cl (mm) | cl (mm) | E.S. 2) (V) | Required cr (mm) | cr (mm)

Supplementary information:

1) Only for frequency above 30 kHz
2) Complete Electric Strength voltage (E.S. (V) when 5.4.2.4 applied)
5.4.4.2 | TABLE: Minimum distance through insulation | N/A
Distance through insulation (DTI) at/of | Peak voltage (V) | Insulation | Required DTI (mm) | Measured DTI (mm)

Supplementary information:

5.4.4.9 | TABLE: Solid insulation at frequencies >30 kHz | N/A
Insulation material | EP | Frequency (kHz) | KR | Thickness d (mm) | Insulation | VPW (Vpk)

Supplementary information:

5.4.9 | TABLE: Electric strength tests | N/A
Test voltage applied between: | Voltage shape (Surge, Impulse, AC, DC, etc.) | Test voltage (V) | Breakdown Yes / No

Supplementary information:

5.5.2.2 | TABLE: Stored discharge on capacitors | N/A
Location | Supply voltage (V) | Operating and fault condition ¹⁾ | Switch position | Measured voltage (Vpk) | ES Class

Supplementary information:
X-capacitors installed for testing:
[ ] bleeding resistor rating:
[ ] ICX:
1) Normal operating condition (e.g., normal operation, or open fuse), SC= short circuit, OC= open circuit

Page 40 of 57 | Report No. 2510B0397SHA-001

IEC 62368-1

Clause | Requirement + Test | Result - Remark | Verdict

TRF No. IEC62368_1E

5.6.6 | TABLE: Resistance of protective conductors and terminations | N/A
Location | Test current (A) | Duration (min) | Voltage drop (V) | Resistance (Ω)

Supplementary information:

5.7.4 | TABLE: Unearthed accessible parts | N/A
Location | Operating and fault conditions | Supply Voltage (V) | Parameters | ES
(Vrms or Vpk) | Current (Arms or Apk) | Freq. (Hz) | class Voltage

Supplementary information:

Abbreviation: SC= short circuit; OC= open circuit

5.7.5 | TABLE: Earthed accessible conductive part | N/A
Supply voltage (V) | : | - | ⎯
Phase(s) | : | [ ] Single Phase; [ ] Three Phase: [ ] Delta [ ] Wye
Power Distribution System | : | [ ] TN [ ]TT [ ] IT
Location | Fault Condition No in IEC 60990 clause 6.2.2 | Touch current (mA) | Comment

Supplementary Information:

5.8 | TABLE: Backfeed safeguard in battery backed up supplies | N/A
Location | Supply voltage (V) | Operating and fault condition | Time (s) | Open-circuit voltage (V) | Touch current (A) | ES Class

Supplementary information:

Abbreviation: SC= short circuit, OC= open circuit

6.2.2 | TABLE: Power source circuit classifications | P
Location | Operating and fault condition | Voltage (Vdc) | Current (A) | Max. Power¹⁾ (W) | Time (S) | PS class
Input circuits | Normal | 5 | 0.45 | 2.25 | 3 | PS1
Battery cell output | Overload | 3.7 | 1.5 | 5.6 | 3 | PS1

Supplementary information:

Abbreviation: SC= short circuit; OC= open circuit

Page 41 of 57 | Report No. 2510B0397SHA-001

IEC 62368-1

Clause | Requirement + Test | Result - Remark | Verdict

TRF No. IEC62368_1E

1) Measured after 3 s for PS1 and measured after 5 s for PS2 and PS3.

*:The EUT is supplied by PS2 power source.

6.2.3.1 | TABLE: Determination of Arcing PIS | N/A
Location | Open circuit voltage after 3 s (Vpk) | Measured r.m.s current (A) | Calculated value | Arcing PIS? Yes / No

Supplementary information:

6.2.3.2 | TABLE: Determination of resistive PIS | N/A
Location | Operating and fault condition | Dissipate power (W) | Arcing PIS? Yes / No

Supplementary information:

* Internal circuits components (except battery cell) are regarded as Resistive PIS.

8.5.5 | TABLE: High pressure lamp | N/A
Lamp manufacturer | Lamp type | Explosion method | Longest axis of glass particle (mm) | Particle found beyond 1 m Yes / No

Supplementary information:

9.6 | TABLE: Temperature measurements for wireless power transmitters | N/A
Supply voltage (V) | : | -- | ⎯
Max. transmit power of transmitter (W) | : | -- | ⎯
Foreign objects | w/o receiver and direct contact | with receiver and direct contact | with receiver and at distance of 2 mm | with receiver and at distance of 5 mm
Object ( oC) | Ambient ( oC) | Object ( oC) | Ambient ( oC) | Object ( oC) | Ambient ( oC) | Object ( oC) | Ambient ( oC)

Supplementary information:

Page 42 of 57 | Report No. 2510B0397SHA-001

IEC 62368-1

Clause | Requirement + Test | Result - Remark | Verdict

TRF No. IEC62368_1E

5.4.1.4, 9.3, B.1.5, B.2.6 | TABLE: Temperature measurements | P
Supply voltage (V) | : | 5Vdc charge | 5Vdc charge | 3.7Vdc discharge | 3.7Vdc discharge | ⎯
Ambient temperature during test Tamb (°C) | : | 40.0 | 25.0 | 40.0 | 25.0 | ⎯
Maximum measured temperature T of part/at: | T (°C) | | | | Allowed Tmax (°C)
PCB near Type-C input | 43.5 | - | 40.6 | - | 130
PCB near U4 | 44.1 | - | 45.6 | - | 130
PCB near C31 | 44.0 | - | 44.8 | - | 130
Lithium-Ion Battery Body | 41.9 | - | 42.1 | - | 45/55*
PCB near U7 | 44.0 | - | 45.1 | - | 65
Internal enclosure | 40.9 | - | 41.0 | - | 60

Below temperatures are adjusted to ambient of 25 °C

Outside enclosure | - | 25.4 | - | 25.3 | 60
Temperature T of winding: | t1 (°C) | R1 (Ω) | t2 (°C) | R2 (Ω) | T (°C) | Allowed Tmax (°C) | Insulation class

Supplementary information:

1) Tma should be considered as directed by appliable requirement
2) Tma is not included in assessment of Touch Temperatures (Clause 9)
3) * For battery model BL-4C: Maximum battery charging temperature 45°C, Maximum battery discharging temperature 55°C
B.2.5 | TABLE: Input test | P
U (V) | Hz | I (A) | I rated (A) | P (W) | P rated (W) | Fuse No | I fuse (A) | Condition/status
5 | -- | 0.7 | 1.0 | 3.5 | -- | -- | -- | Normal work condition.

Supplementary information:

N/A

Page 43 of 57 | Report No. 2510B0397SHA-001

IEC 62368-1

Clause | Requirement + Test | Result - Remark | Verdict

TRF No. IEC62368_1E

B.3, B.4 | TABLE: Abnormal operating and fault condition tests | P
Ambient temperature Tamb (°C) | : | 25, if not stated below | ⎯
Power source for EUT: Manufacturer, model/type, outputrating .. : | Chroma 62012P-100-50 1.2KW/100Vdc/50A | ⎯
Component No. | Condition | Supply voltage (Vdc) | Test time | Fuse no. | Fuse current (A) | Observation
U7 | SC | 3.7Vdc | 30min | -- | -- | Circuit protected. No high temperature rise, no hazard.
U4 | SC | 3.7Vdc | 30min | -- | -- | Current Value:0.630A. Circuit normal work. No high temperature rise and no hazard.
C24 | SC | 3.7Vdc | 30min | -- | -- | Circuit protected immediately. No high temperature rise and no hazard.
C31 | SC | 3.7Vdc | 30min | -- | -- | Circuit protected immediately. No high temperature rise and no hazard.
U1 | SC | 3.7Vdc | 30min | -- | -- | Circuit normal work. No high temperature rise and no hazard.
D2 | SC | 5Vdc | 30min | -- | -- | Circuit protected immediately. No high temperature rise and no hazard.
Q1 | SC | 5Vdc | 30min | -- | -- | Circuit protected immediately. No high temperature rise and no hazard.

Supplementary information:

SC= short circuit

Test table is provided to record abnormal and fault conditions for all applicable energy sources including Thermal burn injury. Column “Abnormal/Fault.” Specify if test condition by indicating “Abnormal” then the condition for a Clause B.3 test or “Single Fault” then the condition for Clause B.4.

M.3 | TABLE: Protection circuits for batteries provided within the equipment | P
Is it possible to install the battery in a reverse polarity position? ..... : | No | ⎯
Equipment Specification | Charging
Voltage (V) | Current (A)
3.7 | 0.8
Manufacturer/type | Battery specification
Non-rechargeable batteries | Rechargeable batteries
Discha rging current (A) | Unintentional charging current (A) | Charging | Discharging current (A) | Reverse charging
| Current (A) | current (A) Voltage (V)

Page 44 of 57 | Report No. 2510B0397SHA-001

IEC 62368-1

Clause | Requirement + Test | Result - Remark | Verdict

TRF No. IEC62368_1E

Manufacturer: Status Research & Development Gmbh. Type: BL-4C Max. current during normal condition | -- | -- | 3.7 | 0.4 | 0.4 | --
Manufacturer: Status Research & Development Gmbh. Type: BL-4C Max. current during fault condition | -- | -- | 3.7 | 0.42 | 0.46 | --

Note: The tests of M.3.2 are applicable only when above appropriate data is not available.

Specified battery temperature (oC) | : | 60
Component No. | Fault condition | Charge/ discharge mode | Test time | Temp. ( oC) | Current (A) | Voltage (V) | Observation
BL-4C | R2 | Charging | 7h | Battery: 42.5 Ambient :40.0 | 0.4 | 3.7 | EUT normal operation, no danger, no high temperature.
BL-4C | U1 Pin2-3 | Discharging | 7h | Battery: 42.8 Ambient :40.0 | 0.42 | 3.7 | EUT normal operation, no danger, no high temperature.

Supplementary information:

Abbreviation: SC= short circuit; OC= open circuit NL= no chemical leakage; NS= no spillage of liquid; NE= no explosion; NF= no emission of flame or expulsion of molten metal.

M.4.2 | TABLE: Charging safeguards for equipment containing a secondary lithium battery | P
Maximum specified charging voltage (V) | : | 4.2V | ⎯
Maximum specified charging current (A) | : | 0.8 | ⎯
Highest specified charging temperature (oC) | : | 45
Lowest specified charging temperature (oC) | : | 0
Battery manufacturer/type | Operating and fault condition | Measurement | Observation
Charging voltage (V) | Charging current (A) | Temp. ( oC)
Manufacturer: Status Research & | Normal | 4.2 | 0.44 | Battery:42.1 Ambient:40.0 | Normal working, no danger, no high temperature.

Page 45 of 57 | Report No. 2510B0397SHA-001

IEC 62368-1

Clause | Requirement + Test | Result - Remark | Verdict

TRF No. IEC62368_1E

Development Gmbh Type: BL-4C | Abnormal | 4.2 | 0.44 → 0.01 | Ambient:0.0 | When battery temperature to 1.5°C, the battery charging current from 0.32A to 0.01A. battery stop charging. Protected, can’t charge.
| Abnormal | 4.2 | 0.44 → 0.01 | Ambient:40.0 | When battery temperature to 44.5°C, the battery charging current from 0.44A to 0.01A, battery stop charging. Protected, can’t charge.
| Single fault | 4.2 | 0.01 | Battery:43.3 Ambient:40.0 | No danger, no high temperature.

Supplementary information:

Abbreviation: SC= short circuit; OC= open circuit; MSCV= maximum specified charging voltage; MSCC= maximum specified charging current; HSCT= highest specified charging temperature; LSCT= lowest specified charging temperature

Q.1 | TABLE: Circuits intended for interconnection with building wiring (LPS) | N/A
Output Circuit | Condition | Uoc (V) | Time (s) | Isc (A) | S (VA)
Meas. | Limit | Meas. | Limit

Supplementary Information:

T.2, T.3, T.4, T.5 | TABLE: Steady force test | N/A
Location/Part | Material | Thickness (mm) | Probe | Force (N) | Test Duration (s) Observation

Supplementary information:

T.6, T.9 | TABLE: Impact test | N/A
Location/Part | Material | Thickness (mm) | Height (mm) | Observation

Supplementary information:N/A

T.7 | TABLE: Drop test | N/A
Location/Part | Material | Thickness (mm) | Height (mm) | Observation

Page 46 of 57 | Report No. 2510B0397SHA-001

IEC 62368-1

Clause | Requirement + Test | Result - Remark | Verdict

TRF No. IEC62368_1E

Supplementary information:

T.8 | TABLE: Stress relief test | N/A
Location/Part | Material | Thickness (mm) | Oven Temperature (°C) | Duration (h) Observation

Supplementary information:

X | TABLE: Alternative method for determining minimum clearances distances | N/A
Clearance distanced between: | Peak of working voltage (V) | Required cl (mm) | Measured cl (mm)

Supplementary information:

Page 47 of 57 | Report No. 2510B0397SHA-001

IEC 62368-1

Clause | Requirement + Test | Result - Remark | Verdict

TRF No. IEC62368_1E

4.1.2 | TABLE: Critical components information | P
Object / part No. | Manufacturer/ trademark | Type / model | Technical data | Standard | Mark(s) of conformity¹⁾
2) : - Description | Main body
Plastic enclosure | SABIC INNOVATIVE PLASTICS US L L C | 121R | HB, 60ºC, min. 1.5mm thickness | UL94 & IEC/EN 62368-1 | UL E45329 & Test with appliance
PCB | DONGGUAN DIHE ELECTRONIC CO LTD | DH-M | V-0,130°C, Min. 1.5mm thickness | UL796 & IEC/EN 62368-1 | UL E207844 & Test with appliance
Battery | Status Research & Development Gmbh | RB02 | 3.7VDC 800mAh,2.96Wh | IEC62133-2:2017 & IEC/EN 62368-1 | KTC CB Cer. No. KR-KTC5886& Test with appliance
LCD panel | Shenzhen Osprey Optoelectronics Technology Co.,Ltd | YDP200B00 3 | 34.6mm(H)*47.8 mm(V)*2.13(D) | IEC/EN 62368-1 | Test with appliance

Supplementary information:

1) Provided evidence ensures the agreed level of compliance. See OD-CB2039.
2) Description line content is optional. Main line description needs to clearly detail the component used for testing.
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

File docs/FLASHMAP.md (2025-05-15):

# Keycard Shell Flash Map

Total flash 2mb in 2 banks with 8kb pages and 128-bit writes.

each contiguous segment dedicated to data is called an area. Area addresses are remapped depending on bank swaps. Areas are transparent to higher layers and boundaries are handled internally.

fs entries are written sequentially, without a specific order. Entries are erased by rewriting the page they belong to, with the entries to delete omitted. Finding an entry has linear complexity and so does finding the next empty spot. Erasing is a slow operation and should be avoided whenever possible.

entries cannot spawn across pages. entries cannot spawn across areas.

if a write does not end at a 128-bit boundary and there is no other queued write padding is added to fill the word. The pattern for padding is 0b10XXXXXX where XXXXXX encode the length of the padding. This means that magic number of regular entries cannot have this bit sequence in its least significant byte. Padding is written in each remaining byte, for example if we need to add 3 bytes of padding it would be encoded as `0x83, 0x82, 0x81`

## Area map

Bank 1:

- 32kb bootloader (write protected)
- 608kb fw
- 384kb data

Bank 2:

- 32kb bootloader (write protected)
- 608kb fw
- 384kb data

## Data FS

magic: 2 bytes
len in bytes: 2 bytes (max len == page size)

### Magics

- 0xffff: empty (size 0)
- 0x4348: chain
- 0x3020: erc-20
- 0x5041: pairing
- 0x4f50: options
- 0x4142: ETH ABI

## Chain

- id: 4 bytes
- ticker: null-terminated ASCII
- network name: null-terminated ASCII
- short name: null-terminated ASCII

## ERC-20

- addr count: 1 byte
- sequence of:
  - chain id: 4 bytes
  - address : 20 bytes
- decimals: 1 byte
- ticker: null-terminated ASCII

## ABI

is composed of a function struct containing a linked list of argument structs. Internal pointers set to 0 are equivalent to NULL. Because of its nature length is very variable across entries

### Function struct

- func selector: 4 bytes
- func ext_selector: 4 bytes
- internal pointer to name: 2 bytes
- internal pointer to first argument: 2 bytes
- func attr: 1 byte
- name: null terminated string
- first argument: argument struct

### Argument struct

- argument type: 2 bytes
- internal pointer to next argument: 2 bytes
- internal pointer to child type (for composite types): 2 bytes
- next argument: argument struct
- child type: argument struct

## Pairing

- uid: 16 bytes
- key: 32 bytes
- index: 1 byte

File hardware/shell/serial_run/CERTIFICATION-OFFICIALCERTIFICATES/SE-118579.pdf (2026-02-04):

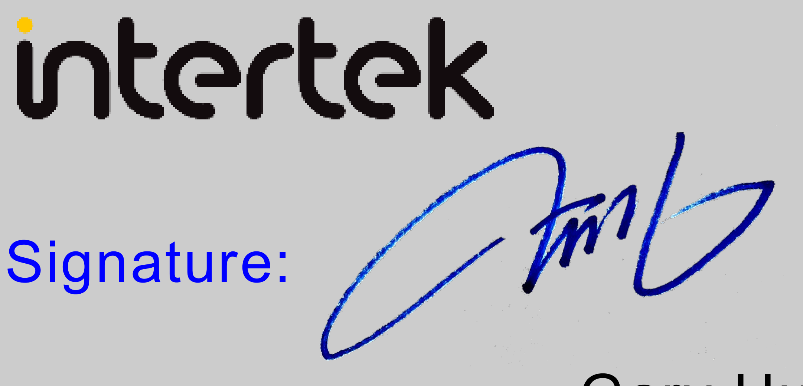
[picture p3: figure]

1/1 | ELJ

Ref. Certif. No.

SE-118579

IEC SYSTEM FOR MUTUAL RECOGNITION OF TEST CERTIFICATES FOR ELECTRICAL EQUIPMENT (IECEE) CB SCHEME

## CB TEST CERTIFICATE

Product | Keycard shell
Name and address of the applicant | Status Research and Development GmbH Baarerstrasse 10, 6302 Zug, Switzerland
Name and address of the manufacturer | Same as applicant

Name and address of the factory

Note: When more than one factory, please report on page 2

ALTYOR Industries (Shanghai) Co., Ltd
152/1421 Zhuan Xing Dong Road Minhang District, Shanghai, 201108, China

Additional Information on page 2

Ratings and principal characteristics | 5Vdc, 1A, Class III
Trademark / Brand (if any) | Keycard
Customer’s Testing Facility (CTF) Stage used | -
Model / Type Ref. | Shell

Additional information (if necessary may also be reported on page 2)

The group and national differences for the CENELEC countries have been checked.

Additional Information on page 2

A sample of the product was tested and found to be in conformity with

IEC 62368-1:2018

As shown in the Test Report Ref. No. which forms part of this Certificate

2510B0392SHA-001

This CB Test Certificate is issued by the National Certification Body

Intertek Semko AB
Torshamnsgatan 43
Box 1103
SE-164 22 Kista, Sweden
Date: 30 January, 2026 | Signature:

### Gary Hu

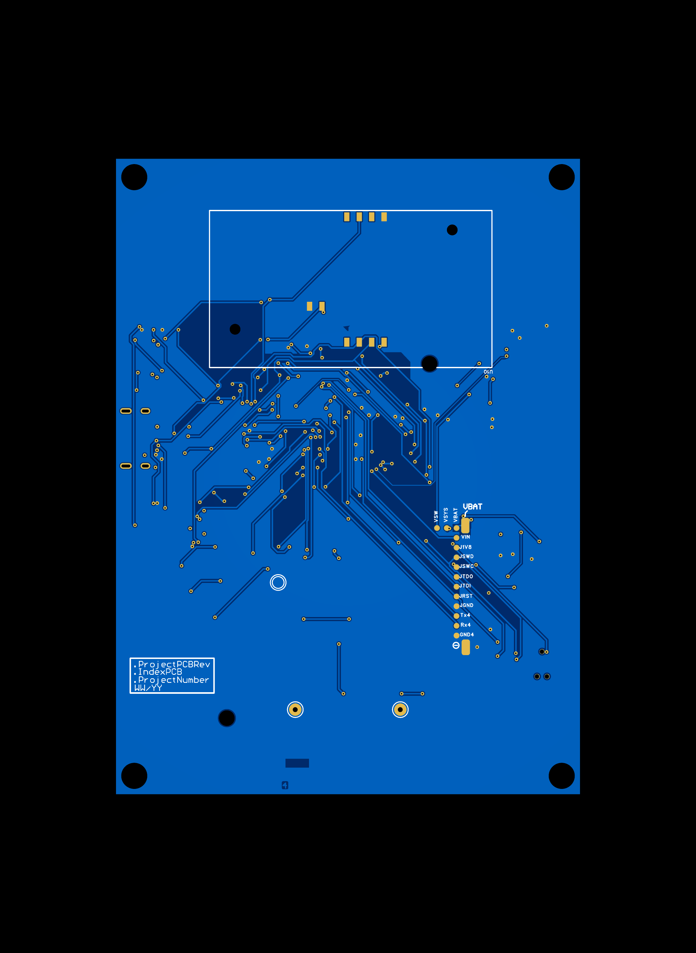
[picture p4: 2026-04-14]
hardware/development_board/devboard_v2/2D_KCP-2282-601-PCBV3.8_2026-03-03_1.png

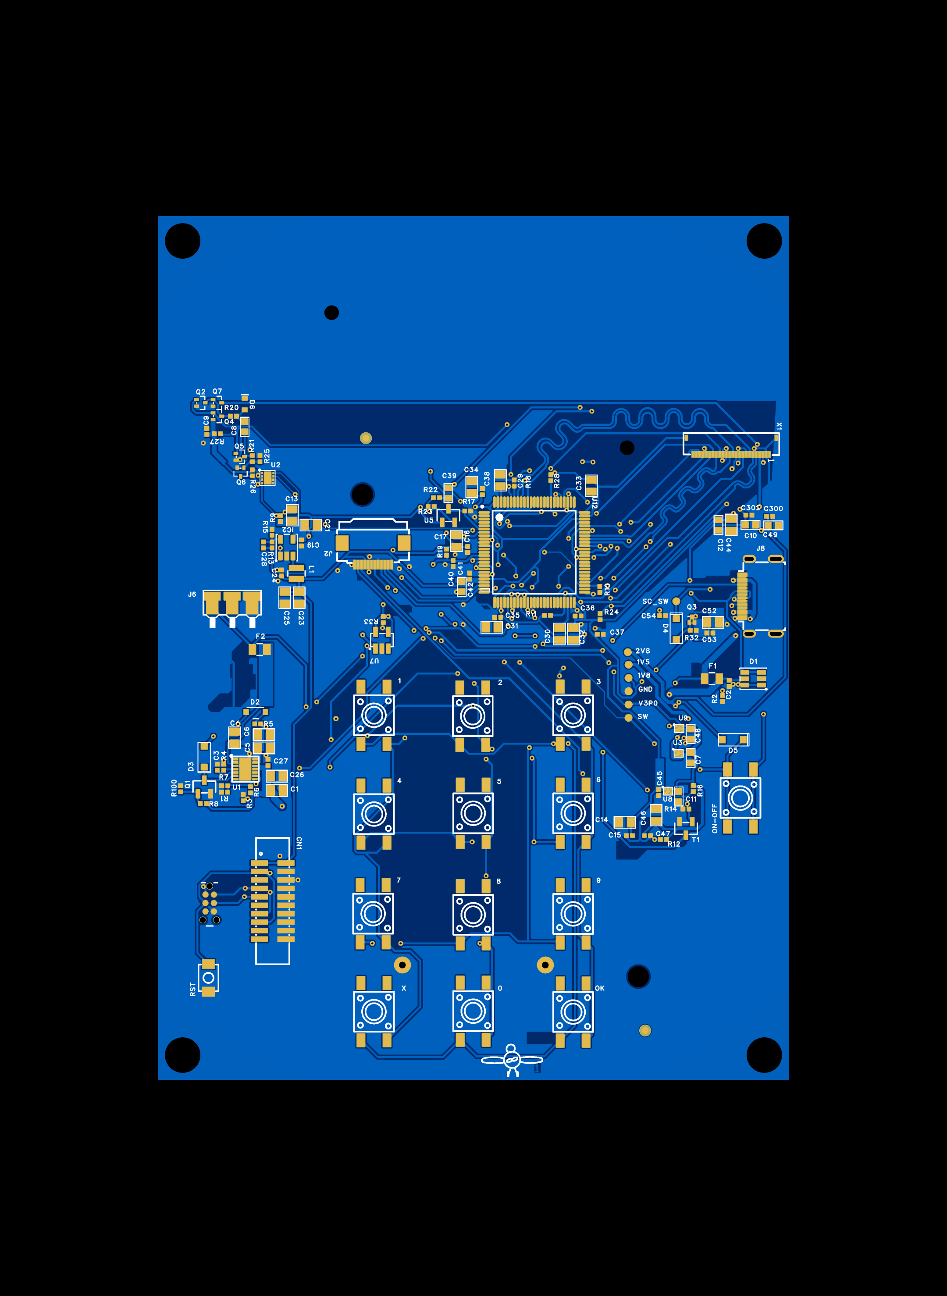
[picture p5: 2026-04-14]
hardware/development_board/devboard_v2/2D_KCP-2282-601-PCBV3.8_2026-03-03.png

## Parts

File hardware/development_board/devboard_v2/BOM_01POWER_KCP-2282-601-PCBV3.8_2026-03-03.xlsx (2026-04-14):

No. | Quantity | Designator | Footprint | Value | Manufacturer Part | Manufacturer | Supplier Part | Supplier | Name | Unique ID | Device | LCSC Part Name | Datasheet | LCSC Stock | LCSC Price | Pin Count | Primary Category | Secondary Category | Comment | JLCPCB Stock | JLCPCB Price | Layer
1 | 21 | 1V5,1V8,2V8,GND,GND4,J1V8,JGND,JRST,JSWC,JSWD,JTDI,JTDO,Rx4,SC_SW,SW,Tx4,V3P0,VBAT,VIN,VSW,VSYS | TESTPOINT 1MM |  |  |  |  |  | TP | 4a4fe6a51a1cc0a2,6c9f92e61b7c87b6,7cdf3eb797e9b109,65b9dc4ad4388d00,73e673facf065865,79d898a6d83a6344,80c733be09004c37,2561eb66f17f6d8d,68368f29bc3e734c,0965216dad8d261e,514519468c844713,61837040637907c0,ba73a10f2c2e20a8,c56bacb3fb01ac9d,c98e5e33ed0cbf90,cf869b2d7173def0,e34d38182fa778ff,eb7a29985d7dcb84,f70ff0b504d1d06d,f634fdef4b12e199,f04816b593461c73 | TP |  |  |  | 0.0349 | 1 |  |  | TP |  |  | T
2 | 1 | B | PLAGE - ROUGE |  |  |  |  |  | TP | fe57bcca61014095 | TP |  |  |  | 0.0349 | 1 |  |  | TP |  |  | T
3 | 18 | C1,C4,C5,C6,C13,C14,C17,C21,C23,C25,C26,C31,C32,C33,C34,C44,C46,C52 | C0805 | 4.7uF | 0805X475M250NT | FH(风华) | C2857998 | LCSC | 4.7uF |  | 0805X475M250NT | 4.7uF ±20% 25V | https://item.szlcsc.com/datasheet/0805X475M250NT/3058809.html |  |  | 2 | Capacitors | Multilayer Ceramic Capacitors MLCC - SMD/SMT | 4.7uF | 36 | 0.0024 | B
4 | 19 | C2,C9,C15,C16,C19,C24,C27,C35,C36,C37,C38,C40,C42,C45,C47,C53,C54,C300,C302 | C0402 | 100nF | 0402B104K500CT | Walsin(华新科) | C152814 | LCSC | 100nF |  | 0402B104K500CT | 100nF ±10% 50V | https://item.szlcsc.com/datasheet/0402B104K500CT/164155.html |  |  | 2 | Capacitors | Multilayer Ceramic Capacitors MLCC - SMD/SMT | 100nF | 3506320 | 0.0004 | T
5 | 1 | C3 | C0402 | 4.7uF | CC0402KRX5R6BB475 | YAGEO(国巨) | C326586 | LCSC | 4.7uF |  | CC0402KRX5R6BB475 | 4.7uF ±10% 10V | https://item.szlcsc.com/datasheet/CC0402KRX5R6BB475/306680.html |  |  | 2 | Capacitors | Multilayer Ceramic Capacitors MLCC - SMD/SMT | 4.7uF | 207401 | 0.0027 | T
6 | 9 | C7,C8,C10,C11,C12,C39,C41,C48,C49 | C0603 | 1uF | 0603X105K500CT | Walsin(华新科) | C141872 | LCSC | 1uF |  | 0603X105K500CT | 1uF ±10% 50V | https://atta.szlcsc.com/upload/public/pdf/source/20181012/C171757_24195D90CC6BA860ED294A8E1EED20EE.pdf |  |  | 2 | Capacitors | Multilayer Ceramic Capacitors MLCC - SMD/SMT | 1uF | 12805 | 0.0015 | T
7 | 1 | C28 | C0402 | 9pF | GJM1555C1H9R0CB01D | muRata(村田) | C85884 | LCSC | 9pF |  | GJM1555C1H9R0CB01D | ±0.25pF 9pF 50V | https://item.szlcsc.com/datasheet/GJM1555C1H9R0CB01D/87060.html |  |  | 2 | Capacitors | Multilayer Ceramic Capacitors MLCC - SMD/SMT | 9pF | 30460 | 0.0024 | T
8 | 2 | C29,C30 | C0805 | 2.2uF | CL21B225KAFNNNE | SAMSUNG(三星) | C19110 | LCSC | 2.2uF |  | CL21B225KAFNNNE | 2.2uF ±10% 25V | https://item.szlcsc.com/datasheet/CL21B225KAFNNNE/19814.html |  |  | 2 | Capacitors | Multilayer Ceramic Capacitors MLCC - SMD/SMT | 2.2uF | 795858 | 0.0023 | T
9 | 1 | CN1 | CONN-SMD_HX-JN1.27-2X10-TP-H4.9 |  | HX JN1.27-2x10 TP H4.9 | hanxia(韩下) | C42455947 | LCSC | HX JN1.27-2x10 TP H4.9 | gge18 | HX JN1.27-2x10 TP H4.9 | 1.27mm 2x10P 排数:2 每排P数:10 | https://item.szlcsc.com/datasheet/HX%2520JN1.27-2x10%2520TP%2520H4.9/44524770.html |  |  | 20 | Connectors | IDC Connectors | HX JN1.27-2x10 TP H4.9 | 349 | 0.0563 | T
10 | 1 | D1 | SOT-563_L1.6-W1.2-P0.50-LS1.6-BL |  | 82400152 | TECH PUBLIC(台舟) | C22435121 | LCSC | 82400152 |  | 82400152_C22435121 | 低电容TVS二极管阵列 | https://item.szlcsc.com/datasheet/82400152/24062289.html |  |  | 6 | Circuit Protection | ESD and Surge Protection (TVS/ESD) | 82400152 | 4005 | 0.0106 | T
11 | 1 | D2 | OSRAM LRY8SFU1V21 |  | LR Y8SF-U1V2-1-0-20-R18-Z | OSRAM | C2899969 | LCSC | LR_Y8SF-U1V2-1 | cca08e5caf06c018 | LR_Y8SF-U1V2-1 |  |  |  | 0.0349 | 2 |  |  | LR_Y8SF-U1V2-1 |  |  | T
12 | 1 | D3 | SOD-123_L2.7-W1.6-LS3.7-RD-1 |  | MBR0530 | YANGJIE(扬杰) | C699108 | LCSC | MBR0530 |  | MBR0530_C699108 | 电压:30V 电流:500mA | https://item.szlcsc.com/datasheet/MBR0530/733800.html |  |  | 2 | Diodes | Schottky Diodes | MBR0530 | 4211 | 0.0066 | T
13 | 2 | D4,D5 | SOD-123_L2.7-W1.6-LS3.7-RD-1 |  | MBR0530T1G | onsemi(安森美) | C82046 | LCSC | MBR0530T1G |  | MBR0530T1G | 电压:30V 电流:500mA | https://item.szlcsc.com/datasheet/MBR0530T1G/83201.html |  |  | 2 | Diodes | Schottky Diodes | MBR0530T1G | 19589 | 0.0105 | B
14 | 1 | D6 | SOD-523_L1.2-W0.8-LS1.6-RD |  | BZX585-C3V0,115 | Nexperia(安世) | C550648 | LCSC | BZX585-C3V0,115 |  | BZX585-C3V0,115 | 稳压二极管 | https://item.szlcsc.com/datasheet/BZX585-C3V0%252C115/571729.html |  |  | 2 | Diodes | Zener Diodes | BZX585-C3V0,115 | 1167 | 0.0194 | T
15 | 1 | F1 | 0805 - FUSE |  | 0805L050WR | Littelfuse | C207022 | LCSC | 0ZCK0075FF2E | 09f31a4987c8a883,dce76cdd9f7f4243 | 0ZCK0075FF2E |  |  |  | 0.0349 | 2 |  |  | 0ZCK0075FF2E,BNP05000F000 |  |  | T
 | 1 | F2 | 0805 - FUSE |  | 0805L050WR | Littelfuse | C207022 | LCSC | BNP05000F000 |  | BNP05000F000 |  |  |  |  |  |  |  |  |  |  | T
17 | 1 | IC2 | SOT23-5 0.95 VAR AA |  | SY8088IAAC | Silergy | C479072 | LCSC | SY8088IAAC | 9c081cc57a023191 | SY8088IAAC |  |  |  | 0.0349 | 5 |  |  | SY8088IAAC |  |  | T
18 | 1 | J2 | GCT FFC2B35-12-G |  | FPC-05F-12PH20 | XUNPU | C2856799 | LCSC | FFC2B35-12-G | 1fb9863844ab5169 | FFC2B35-12-G |  |  |  | 0.0349 | 12 |  |  | FFC2B35-12-G |  |  | B
19 | 1 | J6 | TE 19826331 |  | 1982633-1 | TE Connectivity | C5877665 | LCSC | 1982633-1 | be1703a8306ee88a | 1982633-1 |  |  |  | 0.0349 | 6 |  |  | 1982633-1 |  |  | T
20 | 1 | J8 | ANTENK U6252-35C |  | TYPE-C 16P CB1.6 073 | SHOU HAN | C2906290 | LCSC | U6252-35c | 5c2e899d33916bcd | U6252-35c |  |  |  | 0.0349 | 16 |  |  | U6252-35c |  |  | T
21 | 1 | L1 | IND-SMD_L2.5-W2.0-1 | 2.2uH | BWVF002520122R2M00 | Chilisin(奇力新) | C2838263 | LCSC | 2.2uH |  | BWVF002520122R2M00 | 2.2uH ±20% 1.8A | https://item.szlcsc.com/datasheet/BWVF002520122R2M00/3012588.html |  |  | 2 | Inductors, Coils, Chokes | Power Inductors | 2.2uH | 60 | 0.0073 | T
22 | 1 | M | PLAGE - NOIRE |  |  |  |  |  | TP | dcc3ce6d5d8a1361 | TP |  |  |  | 0.0349 | 1 |  |  | TP |  |  | T
23 | 2 | Mire Top 1,Mire Top 2 | MIRE |  |  |  |  |  | DNI | 6dfc160cef736230,c06f29e3df15be78 | DNI |  |  |  | 0.0349 | 0 |  |  | DNI |  |  | T
24 | 1 | P210 | TC2030-MCP-NL |  |  |  |  |  | TC2030-MCP-NL | 252b89c920cef1b9 | TC2030-MCP-NL |  |  |  | 0.0349 | 6 |  |  | TC2030-MCP-NL |  |  | T
25 | 1 | Q3 | SOT-723_L1.2-W0.8-P0.40-LS1.2-BR |  | RZM002P02T2L | ROHM(罗姆) | C253531 | LCSC | RZM002P02T2L |  | RZM002P02T2L | 1个P沟道 耐压:20V 电流:200mA | https://item.szlcsc.com/datasheet/RZM002P02T2L/248221.html |  |  | 3 | Transistors/Thyristors | MOSFETs | RZM002P02T2L | 6857 | 0.0086 | T
26 | 1 | Q4 | SC-89-3_L1.6-W0.9-P1.00-LS1.6-BR |  | RE1C001ZPTL | ROHM(罗姆) | C703629 | LCSC | RE1C001ZPTL |  | RE1C001ZPTL | 1个P沟道 耐压:20V 电流:100mA | https://item.szlcsc.com/datasheet/RE1C001ZPTL/739440.html |  |  | 3 | Transistors/Thyristors | MOSFETs | RE1C001ZPTL | 4229 | 0.0074 | T
27 | 4 | Q2,Q5,Q6,Q7 | SC-89-3_L1.6-W0.9-P1.00-LS1.6-BR |  | RE1C001UNTCL | ROHM(罗姆) | C253519 | LCSC | RE1C001UNTCL |  | RE1C001UNTCL | 1个N沟道 耐压:20V 电流:100mA | https://item.szlcsc.com/datasheet/RE1C001UNTCL/248209.html |  |  | 3 | Transistors/Thyristors | MOSFETs | RE1C001UNTCL | 4358 | 0.0056 | T
28 | 1 | Q1 | SOT-23-3_L2.9-W1.3-P0.95-LS2.4-BR |  | BSS123-TP | MCC(美微科) | C6521970 | LCSC | BSS123-TP |  | BSS123-TP | 1个N沟道 耐压:100V | https://item.szlcsc.com/datasheet/BSS123-TP/7475168.html |  |  | 3 | Transistors/Thyristors | MOSFETs | BSS123-TP | 97 | 0.0045 | T
29 | 1 | R1 | R0402 |  | ERTJ0EP473GM | PANASONIC(松下) | C336818 | LCSC | ERTJ0EP473GM |  | ERTJ0EP473GM | 47kΩ 电阻精度:±2% 4050K | https://atta.szlcsc.com/upload/public/pdf/source/20200515/C336818_004B4ED78297A1741FE5637305D6F19D.pdf |  |  | 2 | Sensors | NTC Thermistors | ERTJ0EP473GM | 0 | 0.0209 | T
30 | 3 | R2,R3,R4 | R0402 | 5.1kΩ | RC0402FR-075K1L | YAGEO(国巨) | C105872 | LCSC | 5.1kΩ |  | RC0402FR-075K1L | 厚膜电阻 5.1kΩ ±1% 62.5mW | https://item.szlcsc.com/datasheet/RC0402FR-075K1L/107087.html |  |  | 2 | Resistors | Chip Resistor - Surface Mount | 5.1kΩ | 1186629 | 0.0002 | B
31 | 1 | R5 | R0402 | 200Ω | RC0402FR-07200RL | YAGEO(国巨) | C114764 | LCSC | 200Ω |  | RC0402FR-07200RL | 厚膜电阻 200Ω ±1% 62.5mW | https://item.szlcsc.com/datasheet/RC0402FR-07200RL/116008.html |  |  | 2 | Resistors | Chip Resistor - Surface Mount | 200Ω | 482200 | 0.0002 | T
32 | 1 | R6 | R0402 | 40.2kΩ | RC0402FR-0740K2L | YAGEO(国巨) | C137983 | LCSC | 40.2kΩ |  | RC0402FR-0740K2L | 厚膜电阻 40.2kΩ ±1% 62.5mW | https://item.szlcsc.com/datasheet/RC0402FR-0740K2L/149299.html |  |  | 2 | Resistors | Chip Resistor - Surface Mount | 40.2kΩ | 137153 | 0.0002 | T
33 | 1 | R7 | R0402 | 118kΩ | RC0402FR-07118KL | YAGEO(国巨) | C295873 | LCSC | 118kΩ |  | RC0402FR-07118KL | 厚膜电阻 118kΩ ±1% 62.5mW | https://item.szlcsc.com/datasheet/RC0402FR-07118KL/280290.html |  |  | 2 | Resistors | Chip Resistor - Surface Mount | 118kΩ | 1279 | 0.0001
34 | 7 | R8,R11,R17,R18,R19,R20,R24 | R0402 | 10kΩ | RC0402FR-0710KL | YAGEO(国巨) | C60490 | LCSC | 10kΩ |  | RC0402FR-0710KL | 厚膜电阻 10kΩ ±1% 62.5mW | https://item.szlcsc.com/datasheet/RC0402FR-0710KL/61542.html |  |  | 2 | Resistors | Chip Resistor - Surface Mount | 10kΩ | 5017646 | 0.0002
35 | 5 | R9,R10,R14,R16,R28 | R0402 | 100kΩ | RC0402FR-07100KL | YAGEO(国巨) | C60491 | LCSC | 100kΩ |  | RC0402FR-07100KL | 厚膜电阻 100kΩ ±1% 62.5mW | https://item.szlcsc.com/datasheet/RC0402FR-07100KL/61543.html |  |  | 2 | Resistors | Chip Resistor - Surface Mount | 100kΩ | 4312182 | 0.0002
36 | 1 | R12 | 0402 - RESISTOR | 10Ω | RC0402FR-0710RL | YAGEO(国巨) | C138066 | LCSC | RC0402FR-0710RL | 15ac9218146e0f4b | RC0402FR-0710RL |  |  |  | 0.0349 | 2 |  |  | RC0402FR-0710RL
37 | 1 | R13 | R0402 | 205kΩ | RC0402FR-07205KL | YAGEO(国巨) | C477669 | LCSC | 205kΩ |  | RC0402FR-07205KL | 厚膜电阻 205kΩ ±1% 62.5mW | https://atta.szlcsc.com/upload/public/pdf/source/20200715/C477669_32E25EE4E2F5525602D1707108E038B4.pdf |  |  | 2 | Resistors | Chip Resistor - Surface Mount | 205kΩ | 14066 | 0.0002
38 | 1 | R15 | R0402 | 49.9kΩ | RC0402FR-0749K9L | YAGEO(国巨) | C137969 | LCSC | 49.9kΩ |  | RC0402FR-0749K9L | 厚膜电阻 49.9kΩ ±1% 62.5mW | https://item.szlcsc.com/datasheet/RC0402FR-0749K9L/149285.html |  |  | 2 | Resistors | Chip Resistor - Surface Mount | 49.9kΩ | 291507 | 0.0002
39 | 5 | R21,R22,R25,R32,R100 | R0402 | 220kΩ | RC0402FR-07220KL | YAGEO(国巨) | C138030 | LCSC | 220kΩ |  | RC0402FR-07220KL | 厚膜电阻 220kΩ ±1% 62.5mW | https://item.szlcsc.com/datasheet/RC0402FR-07220KL/149346.html |  |  | 2 | Resistors | Chip Resistor - Surface Mount | 220kΩ | 116389 | 0.0002
40 | 1 | R23 | R0402 | 75kΩ | RC0402FR-0775KL | YAGEO(国巨) | C137935 | LCSC | 75kΩ |  | RC0402FR-0775KL | 厚膜电阻 75kΩ ±1% 62.5mW | https://item.szlcsc.com/datasheet/RC0402FR-0775KL/149251.html |  |  | 2 | Resistors | Chip Resistor - Surface Mount | 75kΩ | 169995 | 0.0002
41 | 1 | R26 | R0402 | 750kΩ | RC0402FR-07750KL | YAGEO(国巨) | C137937 | LCSC | 750kΩ |  | RC0402FR-07750KL | 厚膜电阻 750kΩ ±1% 62.5mW | https://item.szlcsc.com/datasheet/RC0402FR-07750KL/149253.html |  |  | 2 | Resistors | Chip Resistor - Surface Mount | 750kΩ | 301858 | 0.0002
42 | 1 | R27 | R0201 | 1MΩ | RC0201FR-071ML | YAGEO(国巨) | C295786 | LCSC | 1MΩ |  | RC0201FR-071ML | 厚膜电阻 1MΩ ±1% 50mW | https://item.szlcsc.com/datasheet/RC0201FR-071ML/280203.html |  |  | 2 | Resistors | Chip Resistor - Surface Mount | 1MΩ | 281995 | 0.0002
43 | 1 | R33 | R0402 | 11.5kΩ | RC0402FR-0711K5L | YAGEO(国巨) | C295874 | LCSC | 11.5kΩ |  | RC0402FR-0711K5L | 厚膜电阻 11.5kΩ ±1% 62.5mW | https://atta.szlcsc.com/upload/public/pdf/source/20180927/C295883_E8D83085EA81BD7DE0B2B681138C15EE.pdf |  |  | 2 | Resistors | Chip Resistor - Surface Mount | 11.5kΩ | 2339 | 0.0001
44 | 1 | RST | SW-SMD_L4.0-W3.0-LS4.8 |  | TS-1071AS-A1B3-D4 | Yuandi(元迪) | C492861 | LCSC | TS-1071AS-A1B3-D4 | gge44_1 | TS-1071AS-A1B3-D4 | 4*3*2mm 立贴 轻触开关 | https://atta.szlcsc.com/upload/public/pdf/source/20200427/C492861_8410BFD0129EF5D536AF148AD1D8A09B.pdf |  |  | 2 | Switches | Tactile Switches | TS-1071AS-A1B3-D4 | 5203 | 0.0124
45 | 14 | 0,1,2,3,4,5,6,7,8,9,X,OK,ON-OFF | KEY-SMD_4P-L6.0-W6.0-P3.90-LS9.0 |  | TS-1095PS-A1B2-C3D2 | Yuandi(元迪) | C2834918 | LCSC | TS-1095PS-A1B2-C3D2 | gge4,gge6,gge7,gge8,gge9,gge10,gge11,gge12,gge13,gge14,gge15,gge16,gge17 | TS-1095PS-A1B2-C3D2 | 6*6*4.3mm 立贴 轻触开关 | https://item.szlcsc.com/datasheet/TS-1095PS-A1B2-C3D2/2997598.html |  |  | 4 | Switches | Tactile Switches | TS-1095PS-A1B2-C3D2 | 59752 | 0.0083
46 | 1 | T1 | SOT-23-3_L2.9-W1.6-P1.90-LS2.8-BR |  | NTR3C21NZT1G | TECH PUBLIC(台舟) | C5123937 | LCSC | NTR3C21NZT1G |  | NTR3C21NZT1G | 耐压:20V 电流:6.5A | https://item.szlcsc.com/datasheet/NTR3C21NZT1G/5718404.html |  |  | 3 | Transistors/Thyristors | MOSFETs | NTR3C21NZT1G | 4710 | 0.0123
47 | 1 | U1 | QFN14-0.5-3S4 |  | MP2607DL-LF-P | Monolithic Power Systems Inc. | 1589-1136-2-ND | Digikey | MP2607DL-LF-P | 1bdc0ab44f99f92d | MP2607DL-LF-P |  |  |  | 0.0349 | 15 |  |  | MP2607DL-LF-P
48 | 1 | U2 | TOREX USP-8B06 |  | XC6194AA05ER-G | TOREX | C3229348 | LCSC | XC6194AA05ER-G | 48f0ae2437312dae | XC6194AA05ER-G |  |  |  | 0.0349 | 9 |  |  | XC6194AA05ER-G
49 | 1 | U3 | ON SEMI NCV8160AMX330TBG |  | NCP115AMX150TCG | onsemi | C892042 | LCSC | NCP115AMX150TCG | 2dbbb3175ebf36d7,484e3008dca2bfa8,66797bcd97f4f6c2 | NCP115AMX150TCG |  |  |  | 0.0349 | 5 |  |  | NCP115AMX150TCG,NCP115AMX180TCG,NCP115AMX280TCG
 | 1 | U8 |  |  | NCP115AMX180TCG | onsemi | C603501 | LCSC | NCP115AMX180TCG |  | NCP115AMX180TCG
 | 1 | U9 |  |  | NCP115AMX280TCG | onsemi | C603502 | LCSC | NCP115AMX280TCG |  | NCP115AMX280TCG
50 | 1 | U5 | SOT-23-3_L3.0-W1.7-P0.95-LS2.9-BR |  | TLVH431AQDBZRG4 | TI(德州仪器) | C2157199 | LCSC | TLVH431AQDBZRG4 |  | TLVH431AQDBZRG4 | TLVH431AQDBZRG4 | https://www.ti.com/cn/lit/gpn/tlvh431 |  |  | 3 | Power Management (PMIC) | Voltage Reference | TLVH431AQDBZRG4 | 0 | 0.0779
51 | 1 | U7 | SOT-23-5_L2.9-W1.6-P0.95-LS2.8-TL |  | ESDS312DBVR | TI(德州仪器) | C1976412 | LCSC | ESDS312DBVR |  | ESDS312DBVR | ESDS312DBVR | https://www.ti.com/cn/lit/gpn/esds314 |  |  | 5 | Circuit Protection | ESD and Surge Protection (TVS/ESD) | ESDS312DBVR | 4566 | 0.0421
52 | 1 | U10 | SD-SMD_5145300-3 |  | 5145300-3 | TE Connectivity(泰科电子) | C5261038 | LCSC | 5145300-3 | gge2 | 5145300-3 | Smart卡 卡座 | https://item.szlcsc.com/datasheet/5145300-3/5983702.html |  |  | 10 | Connectors | SIM Card Connectors | 5145300-3 | 0 | 0.2775
53 | 1 | U12 | LQFP-100_L14.0-W14.0-P0.50-LS16.0-BL |  | STM32H573VIT6 | ST(意法半导体) | C7545121 | LCSC | STM32H573VIT6 | gge5 | STM32H573VIT6 | Arm Cortex-M33 32位MCU+TrusZone+浮点运算单元（FPU） | https://item.szlcsc.com/datasheet/STM32H573VIT6/8655963.html |  |  | 100 | Embedded Processors & Controllers | Microcontrollers (MCU/MPU/SOC) | STM32H573VIT6 | 519 | 1.5076
54 | 1 | X1 | HCTL HC-FPC-05-09-24RLTAG |  |  |  |  |  | HC-FPC-05-09-24RLTAG | 220c9828e5ec91fa | HC-FPC-05-09-24RLTAG |  |  |  | 0.0349 | 25 |  |  | HC-FPC-05-09-24RLTAG

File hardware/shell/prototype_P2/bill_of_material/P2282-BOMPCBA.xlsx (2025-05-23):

 | BOM VERSION |  | KCP-2282-603 BOM V0.0 |  | USD/RMB | 7.17
 | BOM.xlsx | Sheet1 | June 2024 - MAIN PCBA |  | EUR/RMB | 7.87
 |  |  |  |  | YEN/RMB | 0.06
P2282 - STATUS KCARD - BOM PCBA
Marker | Fx | Family | Description | Qty | Manufacturer | Manufacturer P/N | Vendor | MOQ | SPQ | L/T | Marker | Description | Qty | Manufacturer | Manufacturer P/N
MAIN PCBA - KCP-2282-603 BOM V3.2
C1, C4, C5, C6, C13, C14, C17, C21, C23, C25, C26, C31, C32, C33, C34, C44, C46, C52 |  |  | CAP X5R 4.7µF 25V ±10% 0805 | 18 | WALSIN | 0805X475M250CT | JULAN | 3000 | 3000 | 8 | #N/A | #N/A | #N/A | #N/A | #N/A
C2, C9, C15, C16, C19, C22, C24, C27, C35, C36, C37, C38, C40, C42, C43, C45, C47, C53, C54 |  |  | CAP X7R 100nF 50V ±10% 0402 | 19 | WALSIN | 0402B104K500CT | bichi | 10000 | 10000 | 8 | #N/A | #N/A | #N/A | #N/A | #N/A
C3 |  |  | CAP X5R 4.7µF 10V ±10% 0402 | 1 | YAGEO | CC0402KRX5R6BB475 | boao | 10000 | 10000 | 12 | #N/A | #N/A | #N/A | #N/A | #N/A
C7, C8, C10, C11, C12, C39, C41, C48, C49 |  |  | CAP X5R 1µF 50V ±10% 0603 | 9 | WALSIN | 0603X105K500CT | boao | 4000 | 4000 | 12 | #N/A | #N/A | #N/A | #N/A | #N/A
C28 |  |  | CAP COG 9pF 50V ±0.1pF 0402 | 1 | YAGEO | 0402N9R0B500CT | bichi | 10000 | 10000 | 8 | #N/A | #N/A | #N/A | #N/A | #N/A
C29, C30 |  |  | CAP X5R 2.2µF 50V ±10% 0805 | 2 | WALSIN | 0805X225M500CT | JULAN | 3000 | 3000 | 8 | #N/A | #N/A | #N/A | #N/A | #N/A
D1 |  |  | diode TVS, 82400 Series, Bidirectionelle | 1 | Würth | 824001 | WURTH | 3000 | 3000 | 14
D2 |  |  | Osram Opto Micro SIDELED Series Red LED, 120 Source: Datasheet | 1 | OSRAM | LR_Y8SF-U1V2-1 | ARROW | 3000 | 3000 | 12
D3, D4, D5 |  |  | Schottky Rectifier, 30 V, 500 mA, Single | 3 | ON SEMI | MBR0530-TP | FUTURE | 3000 | 3000 | 10
F1 |  |  | BEL FUSE - CIRCUIT PROTECTION - 0ZCK0050FF2E - Resettable Fuse, PPTC, 0805 (2012 Metric), 0ZCK Series, 6 VDC, 500 mA, 1 A, 0.1 s Source: Datasheet | 1 |  | BNP05000F000 | BETTER | 5000 | 5000 | 3
F2 |  |  | PTC Resettable Fuse 0.75A(hold) 1.5A(trip) 6VDC 40A 0.6W 0.2s 0.09Ohm SMD Solder Pad 0805 T/R Automotive Source: Datasheet | 1 | Bel Circuit Protection | 0ZCK0075FF2E | boao | 3000 | 3000 | 6 | #N/A | #N/A | #N/A | #N/A | #N/A
IC2 |  |  | TPS62000DGSG4, Switching Regulator, Buck Controller, 600mA, Adjustable, 0.8 to 5.5V, 1000kHz, 10-Pin MSOP, VSSOP | 1 | Silergy Corp | SY8088IAAC |  | 3000 | 3000 | 6
J2 |  |  | 0.5mm Side entry Flat Flexible Cable Connector, 12pin, bottom contacts | 1 | GCT | FFC2B35-12-G | Future | 2000 | 2000 | 10
J4 |  |  | Connecteurs FFC et FPC FFC/FPC 6 positions, 1mm, right angle, bottom contact | 1 | JUSHO | AFA07-S06FCA-00 |  | 1500 | 1500 | 6
J6 |  |  | Connecteurs carte Ã carte et mezzanine BATTERY CONN 3 POSITION | 1 | TE Connectivity | 1982633-1 | Future | 5000 | 5000 | 12 | #N/A | #N/A | #N/A | #N/A | #N/A
J8 |  |  | Connecteurs USB USB C Rec 16P 3u" Mid Mnt 1.6mm O-set SMT L = 6.5mm S-Spring | 1 |  | U6252-35C | Antenk | 5000 | 5000 | 6
L1 |  |  | IND 10µH, 30%, 1.3A 65mOhm - 6x6 | 1 | CHILISIN | BWVF002520122R2M00 | JULAN | 2000 | 2000 | 4
Q1 |  |  | MOS N 100V 170mA Rds6R - SOT23 | 1 | MCC | BSS123-TP | FUTURE | 3000 | 3000 | 14
Q2, Q5, Q6, Q7 |  |  | MOS N 20V 100mA Rds3.5R | 4 | ROHM SEMI | RE1C001UNTCL | boao | 3000 | 3000 | 12 | #N/A | #N/A | #N/A | #N/A | #N/A
Q3 |  |  | MOS P 20V 200mA Rds1.2R | 1 | ROHM SEMI | RZM002P02T2L | JULAN | 8000 | 8000 | 12 | #N/A | #N/A | #N/A | #N/A | #N/A
Q4 |  |  | MOS P 20V 100mA Rds3.8R | 1 | ROHM SEMI | RE1C001ZPTL | bichi | 3000 | 3000 | 12 | #N/A | #N/A | #N/A | #N/A | #N/A
R1 |  |  | CTN 47k 2% B(25/50) 4050K 0/+1% - 0402 | 1 | PANASONIC | ERT-J0EP473GM | JULAN | 10000 | 10000 | 12 | #N/A | #N/A | #N/A | #N/A | #N/A
R2, R3, R4 |  |  | RES 5.1k 63mW 1% 0402 | 3 | YAGEO | RC0402FR-075K1L | boao | 10000 | 10000 | 15 | #N/A | #N/A | #N/A | #N/A | #N/A
R5 |  |  | RES 200R 63mW 1% 0402 | 1 | YAGEO | RC0402FR-07200RL | boao | 10000 | 10000 | 15 | #N/A | #N/A | #N/A | #N/A | #N/A
R6 |  |  | RES 40.2k 63mW 1% 0402 | 1 | YAGEO | RC0402FR-0740K2L | boao | 10000 | 10000 | 15 | #N/A | #N/A | #N/A | #N/A | #N/A
R7 |  |  | RES 118k 63mW 1% 0402 | 1 | YAGEO | RC0402FR-07118KL | boao | 10000 | 10000 | 15 | #N/A | #N/A | #N/A | #N/A | #N/A
R8, R9, R10, R14, R16, R28 |  |  | RES 100k 63mW 1% 0402 | 6 | YAGEO | RC0402FR-07100KL | boao | 10000 | 10000 | 15 | #N/A | #N/A | #N/A | #N/A | #N/A
R11, R17, R18, R19, R20, R24 |  |  | RES 10k 63mW 1% 0402 | 6 | YAGEO | RC0402FR-0710KL | boao | 10000 | 10000 | 15 | #N/A | #N/A | #N/A | #N/A | #N/A
R12 |  |  | RES 10R 63mW 1% 0402 | 1 | YAGEO | RC0402FR-0710RL | Future | 10000 | 10000 | 15 | #N/A | #N/A | #N/A | #N/A | #N/A
R13 |  |  | RES 665k 63mW 1% 0402 | 1 | YAGEO | RC0402FR-07205KL | boao | 10000 | 10000 | 15 | #N/A | #N/A | #N/A | #N/A | #N/A
R15 |  |  | RES 115k 63mW 1% 0402 | 1 | YAGEO | RC0402FR-0749K9L | boao | 10000 | 10000 | 15 | #N/A | #N/A | #N/A | #N/A | #N/A
R21, R22, R25, R32 |  |  | RES 220k 63mW 1% 0402 | 4 | YAGEO | RC0402FR-07220KL | boao | 10000 | 10000 | 15 | #N/A | #N/A | #N/A | #N/A | #N/A
R23 |  |  | RES 75k 63mW 1% 0402 | 1 | YAGEO | RC0402FR-0775KL | boao | 10000 | 10000 | 15 | #N/A | #N/A | #N/A | #N/A | #N/A
R26 |  |  | RES 750k 63mW 1% 0402 | 1 | YAGEO | RC0402FR-07750KL | boao | 10000 | 10000 | 15 | #N/A | #N/A | #N/A | #N/A | #N/A
R27 |  |  | RES 1M 63mW 1% 0402 | 1 | YAGEO | RC0201FR-071ML | boao | 10000 | 10000 | 15 | #N/A | #N/A | #N/A | #N/A | #N/A
R33 |  |  | RES 11k5 63mW 1% 0402 | 1 | YAGEO | RC0402FR-0711K5L | boao | 10000 | 10000 | 15 | #N/A | #N/A | #N/A | #N/A | #N/A
S1, S2, S5, S6, S7, S8, S9, S10, S11, S12, S13, S14 |  |  | Tactile "Key-Pad" Dome Switches | 12 | XKB Connectivity | TS-3737-B | XKB | 4000 | 4000 | 6
S3 |  |  | Interrupteurs de contact '3.5*3.0*1.25 | 1 |  | TS-1821C | Sofng | 3000 | 3000 | 4
T1 |  |  | MOS N 20V 3.6A Rds24mR - SOT23 | 1 |  | 2N7002K | Future | 3000 | 3000 | 12 | #N/A | #N/A | #N/A | #N/A | #N/A
U1 |  |  | Li + LINEAR Charger WithSystem Power Path Management | 1 |  |  | JULAN | 5000 | 5000 | 0 | #N/A | #N/A | #N/A | #N/A | #N/A
U2 |  |  | Power saving Push Button Load switch | 1 | TOREX | XC6194AA05ER-G | JULAN | 5000 | 5000 | 12
U3 |  |  | LDO Regulator - High PSRR - 300mA - Input Voltage 1.7V/5.5V - Ouput Voltage 1.5V | 1 | ON SEMI | NCP115AMX150TCG | JULAN | 12000 | 3000 | 12
U4 |  |  | Arm Â® Cortex Â® -M33 32-bit MCU+TrusZoneÂ® + FPU, 375 DMIPS 250 MHz, 2-Mbyte flash memory, 640 Kbytes RAM, Crypt | 1 | STMicroelectronics | STM32H573VIT6 | JULAN | 1000 | 1000 | 12 | #N/A | #N/A | #N/A | #N/A | #N/A
U5 |  |  | Low voltage adjustable 1.5% precision shunt regulators, SOT23 | 1 | TEXAS | TLVH431AQDBZR | JULAN | 6000 | 6000 | 12 | #N/A | #N/A | #N/A | #N/A | #N/A
U7 |  |  | 3.6V Data-Line Surge and 30kV ESD Protection Diode Array 5-SOT-23 -40 to 125 | 1 | TEXAS | ESDS312DBVR | TI | 3000 | 3000 | 14
U8 |  |  | LDO Regulator - High PSRR - 300mA - Input Voltage 1.7V/5.5V - Ouput Voltage 1.8V | 1 | ON SEMI | NCP115AMX180TCG | Future | 3000 | 3000 | 15
U9 |  |  | LDO Regulator - High PSRR - 300mA - Input Voltage 1.7V/5.5V - Ouput Voltage 2.8V | 1 |  |  | ICCHAIN | 5000 | 5000 | 12 | #N/A | #N/A | #N/A | #N/A | #N/A
X1 |  |  | BTB connector pitch 0.4mm 24pos | 1 | HCTL | 'HC-FPC-05-09-24RLTAG | BOAO | 1000 | 1000 | 6
SIN PCBA - FLX-2282-613 BOM V3.0
P2 |  |  | 8-position Micro SIM card connector Right-angle surface mount Gold with switch | 1 | WALSIN | 0805X475M250CT | future | 2000 | 2000 | 21 | #N/A | #N/A | #N/A | #N/A | #N/A
#REF! |  |  | #REF! | #REF! | #REF! | #REF!
#REF! |  |  | #REF! | #REF! | #REF! | #REF!
#REF! |  |  | #REF! | #REF! | #REF! | #REF!
#REF! |  |  | #REF! | #REF! | #REF! | #REF!
#REF! |  |  | #REF! | #REF! | #REF! | #REF!
#REF! |  |  | #REF! | #REF! | #REF! | #REF!
#REF! |  |  | #REF! | #REF! | #REF! | #REF!
#REF! |  |  | #REF! | #REF! | #REF! | #REF!
#REF! |  |  | #REF! | #REF! | #REF! | #REF!
#REF! |  |  | #REF! | #REF! | #REF! | #REF!
#REF! |  |  | #REF! | #REF! | #REF! | #REF!
#REF! |  |  | #REF! | #REF! | #REF! | #REF!
#REF! |  |  | #REF! | #REF! | #REF! | #REF!
#REF! |  |  | #REF! | #REF! | #REF! | #REF!
#REF! |  |  | #REF! | #REF! | #REF! | #REF!
#REF! |  |  | #REF! | #REF! | #REF! | #REF!
#REF! |  |  | #REF! | #REF! | #REF! | #REF!
#REF! |  |  | #REF! | #REF! | #REF! | #REF!
#REF! |  |  | #REF! | #REF! | #REF! | #REF!
#REF! |  |  | #REF! | #REF! | #REF! | #REF!
#REF! |  |  | #REF! | #REF! | #REF! | #REF!
#REF! |  |  | #REF! | #REF! | #REF! | #REF!
#REF! |  |  | #REF! | #REF! | #REF! | #REF!
#REF! |  |  | #REF! | #REF! | #REF! | #REF!
#REF! |  |  | #REF! | #REF! | #REF! | #REF!
#REF! |  |  | #REF! | #REF! | #REF! | #REF!
#REF! |  |  | #REF! | #REF! | #REF! | #REF!
#REF! |  |  | #REF! | #REF! | #REF! | #REF!
#REF! |  |  | #REF! | #REF! | #REF! | #REF!
#REF! |  |  | #REF! | #REF! | #REF! | #REF!
#REF! |  |  | #REF! | #REF! | #REF! | #REF!
#REF! |  |  | #REF! | #REF! | #REF! | #REF!
#REF! |  |  | #REF! | #REF! | #REF! | #REF!
#REF! |  |  | #REF! | #REF! | #REF! | #REF!
#REF! |  |  | #REF! | #REF! | #REF! | #REF!
#REF! |  |  | #REF! | #REF! | #REF! | #REF!
#REF! |  |  | #REF! | #REF! | #REF! | #REF!
#REF! |  |  | #REF! | #REF! | #REF! | #REF!
#REF! |  |  | #REF! | #REF! | #REF! | #REF!
#REF! |  |  | #REF! | #REF! | #REF! | #REF!
#REF! |  |  | #REF! | #REF! | #REF! | #REF!
#REF! |  |  | #REF! | #REF! | #REF! | #REF!
#REF! |  |  | #REF! | #REF! | #REF! | #REF!
#REF! |  |  | #REF! | #REF! | #REF! | #REF!
#REF! |  |  | #REF! | #REF! | #REF! | #REF!
#REF! |  |  | #REF! | #REF! | #REF! | #REF!
#REF! |  |  | #REF! | #REF! | #REF! | #REF!
#REF! |  |  | #REF! | #REF! | #REF! | #REF!
#REF! |  |  | #REF! | #REF! | #REF! | #REF!
#REF! |  |  | #REF! | #REF! | #REF! | #REF!
#REF! |  |  | #REF! | #REF! | #REF! | #REF!
#REF! |  |  | #REF! | #REF! | #REF! | #REF!
#REF! |  |  | #REF! | #REF! | #REF! | #REF!
#REF! |  |  | #REF! | #REF! | #REF! | #REF!
#REF! |  |  | #REF! | #REF! | #REF! | #REF!
#REF! |  |  | #REF! | #REF! | #REF! | #REF!
#REF! |  |  | #REF! | #REF! | #REF! | #REF!
#REF! |  |  | #REF! | #REF! | #REF! | #REF!
#REF! |  |  | #REF! | #REF! | #REF! | #REF!
#REF! |  |  | #REF! | #REF! | #REF! | #REF!
#REF! |  |  | #REF! | #REF! | #REF! | #REF!
#REF! |  |  | #REF! | #REF! | #REF! | #REF!
#REF! |  |  | #REF! | #REF! | #REF! | #REF!
#REF! |  |  | #REF! | #REF! | #REF! | #REF!
#REF! |  |  | #REF! | #REF! | #REF! | #REF!
#REF! |  |  | #REF! | #REF! | #REF! | #REF!
#REF! |  |  | #REF! | #REF! | #REF! | #REF!
#REF! |  |  | #REF! | #REF! | #REF! | #REF!
#REF! |  |  | #REF! | #REF! | #REF! | #REF!
#REF! |  |  | #REF! | #REF! | #REF! | #REF!
#REF! |  |  | #REF! | #REF! | #REF! | #REF!
#REF! |  |  | #REF! | #REF! | #REF! | #REF!
#REF! |  |  | #REF! | #REF! | #REF! | #REF!
#REF! |  |  | #REF! | #REF! | #REF! | #REF!
#REF! |  |  | #REF! | #REF! | #REF! | #REF!
#REF! |  |  | #REF! | #REF! | #REF! | #REF!
#REF! |  |  | #REF! | #REF! | #REF! | #REF!
#REF! |  |  | #REF! | #REF! | #REF! | #REF!
#REF! |  |  | #REF! | #REF! | #REF! | #REF!
#REF! |  |  | #REF! | #REF! | #REF! | #REF!
#REF! |  |  | #REF! | #REF! | #REF! | #REF!
#REF! |  |  | #REF! | #REF! | #REF! | #REF!
#REF! |  |  | #REF! | #REF! | #REF! | #REF!
#REF! |  |  | #REF! | #REF! | #REF! | #REF!
#REF! |  |  | #REF! | #REF! | #REF! | #REF!
#REF! |  |  | #REF! | #REF! | #REF! | #REF!
#REF! |  |  | #REF! | #REF! | #REF! | #REF!
#REF! |  |  | #REF! | #REF! | #REF! | #REF!
#REF! |  |  | #REF! | #REF! | #REF! | #REF!
#REF! |  |  | #REF! | #REF! | #REF! | #REF!
#REF! |  |  | #REF! | #REF! | #REF! | #REF!
#REF! |  |  | #REF! | #REF! | #REF! | #REF!
#REF! |  |  | #REF! | #REF! | #REF! | #REF!
#REF! |  |  | #REF! | #REF! | #REF! | #REF!
#REF! |  |  | #REF! | #REF! | #REF! | #REF!
#REF! |  |  | #REF! | #REF! | #REF! | #REF!
#REF! |  |  | #REF! | #REF! | #REF! | #REF!
#REF! |  |  | #REF! | #REF! | #REF! | #REF!
#REF! |  |  | #REF! | #REF! | #REF! | #REF!
#REF! |  |  | #REF! | #REF! | #REF! | #REF!
#REF! |  |  | #REF! | #REF! | #REF! | #REF!
#REF! |  |  | #REF! | #REF! | #REF! | #REF!
#REF! |  |  | #REF! | #REF! | #REF! | #REF!
#REF! |  |  | #REF! | #REF! | #REF! | #REF!
#REF! |  |  | #REF! | #REF! | #REF! | #REF!
#REF! |  |  | #REF! | #REF! | #REF! | #REF!
#REF! |  |  | #REF! | #REF! | #REF! | #REF!
#REF! |  |  | #REF! | #REF! | #REF! | #REF!
#REF! |  |  | #REF! | #REF! | #REF! | #REF!
#REF! |  |  | #REF! | #REF! | #REF! | #REF!
#REF! |  |  | #REF! | #REF! | #REF! | #REF!
#REF! |  |  | #REF! | #REF! | #REF! | #REF!
#REF! |  |  | #REF! | #REF! | #REF! | #REF!
#REF! |  |  | #REF! | #REF! | #REF! | #REF!
#REF! |  |  | #REF! | #REF! | #REF! | #REF!
#REF! |  |  | #REF! | #REF! | #REF! | #REF!
#REF! |  |  | #REF! | #REF! | #REF! | #REF!
#REF! |  |  | #REF! | #REF! | #REF! | #REF!
#REF! |  |  | #REF! | #REF! | #REF! | #REF!
#REF! |  |  | #REF! | #REF! | #REF! | #REF!
#REF! |  |  | #REF! | #REF! | #REF! | #REF!
#REF! |  |  | #REF! | #REF! | #REF! | #REF!
#REF! |  |  | #REF! | #REF! | #REF! | #REF!
#REF! |  |  | #REF! | #REF! | #REF! | #REF!
#REF! |  |  | #REF! | #REF! | #REF! | #REF!
#REF! |  |  | #REF! | #REF! | #REF! | #REF!
#REF! |  |  | #REF! | #REF! | #REF! | #REF!
#REF! |  |  | #REF! | #REF! | #REF! | #REF!
#REF! |  |  | #REF! | #REF! | #REF! | #REF!
#REF! |  |  | #REF! | #REF! | #REF! | #REF!
#REF! |  |  | #REF! | #REF! | #REF! | #REF!
#REF! |  |  | #REF! | #REF! | #REF! | #REF!
#REF! |  |  | #REF! | #REF! | #REF! | #REF!
#REF! |  |  | #REF! | #REF! | #REF! | #REF!
#REF! |  |  | #REF! | #REF! | #REF! | #REF!
#REF! |  |  | #REF! | #REF! | #REF! | #REF!
#REF! |  |  | #REF! | #REF! | #REF! | #REF!
#REF! |  |  | #REF! | #REF! | #REF! | #REF!
#REF! |  |  | #REF! | #REF! | #REF! | #REF!
#REF! |  |  | #REF! | #REF! | #REF! | #REF!
#REF! |  |  | #REF! | #REF! | #REF! | #REF!
#REF! |  |  | #REF! | #REF! | #REF! | #REF!
#REF! |  |  | #REF! | #REF! | #REF! | #REF!
#REF! |  |  | #REF! | #REF! | #REF! | #REF!
#REF! |  |  | #REF! | #REF! | #REF! | #REF!
#REF! |  |  | #REF! | #REF! | #REF! | #REF!
#REF! |  |  | #REF! | #REF! | #REF! | #REF!
#REF! |  |  | #REF! | #REF! | #REF! | #REF!
#REF! |  |  | #REF! | #REF! | #REF! | #REF!
#REF! |  |  | #REF! | #REF! | #REF! | #REF!
#REF! |  |  | #REF! | #REF! | #REF! | #REF!
#REF! |  |  | #REF! | #REF! | #REF! | #REF!
#REF! |  |  | #REF! | #REF! | #REF! | #REF!
#REF! |  |  | #REF! | #REF! | #REF! | #REF!
#REF! |  |  | #REF! | #REF! | #REF! | #REF!
#REF! |  |  | #REF! | #REF! | #REF! | #REF!
#REF! |  |  | #REF! | #REF! | #REF! | #REF!
#REF! |  |  | #REF! | #REF! | #REF! | #REF!
#REF! |  |  | #REF! | #REF! | #REF! | #REF!
#REF! |  |  | #REF! | #REF! | #REF! | #REF!
#REF! |  |  | #REF! | #REF! | #REF! | #REF!
#REF! |  |  | #REF! | #REF! | #REF! | #REF!
#REF! |  |  | #REF! | #REF! | #REF! | #REF!
#REF! |  |  | #REF! | #REF! | #REF! | #REF!
#REF! |  |  | #REF! | #REF! | #REF! | #REF!
#REF! |  |  | #REF! | #REF! | #REF! | #REF!
#REF! |  |  | #REF! | #REF! | #REF! | #REF!
#REF! |  |  | #REF! | #REF! | #REF! | #REF!
#REF! |  |  | #REF! | #REF! | #REF! | #REF!
#REF! |  |  | #REF! | #REF! | #REF! | #REF!
#REF! |  |  | #REF! | #REF! | #REF! | #REF!
#REF! |  |  | #REF! | #REF! | #REF! | #REF!
#REF! |  |  | #REF! | #REF! | #REF! | #REF!
#REF! |  |  | #REF! | #REF! | #REF! | #REF!
#REF! |  |  | #REF! | #REF! | #REF! | #REF!
#REF! |  |  | #REF! | #REF! | #REF! | #REF!
#REF! |  |  | #REF! | #REF! | #REF! | #REF!
#REF! |  |  | #REF! | #REF! | #REF! | #REF!
#REF! |  |  | #REF! | #REF! | #REF! | #REF!
#REF! |  |  | #REF! | #REF! | #REF! | #REF!
#REF! |  |  | #REF! | #REF! | #REF! | #REF!
#REF! |  |  | #REF! | #REF! | #REF! | #REF!
#REF! |  |  | #REF! | #REF! | #REF! | #REF!
#REF! |  |  | #REF! | #REF! | #REF! | #REF!
#REF! |  |  | #REF! | #REF! | #REF! | #REF!
#REF! |  |  | #REF! | #REF! | #REF! | #REF!
#REF! |  |  | #REF! | #REF! | #REF! | #REF!
#REF! |  |  | #REF! | #REF! | #REF! | #REF!
#REF! |  |  | #REF! | #REF! | #REF! | #REF!
#REF! |  |  | #REF! | #REF! | #REF! | #REF!
#REF! |  |  | #REF! | #REF! | #REF! | #REF!
#REF! |  |  | #REF! | #REF! | #REF! | #REF!
#REF! |  |  | #REF! | #REF! | #REF! | #REF!
#REF! |  |  | #REF! | #REF! | #REF! | #REF!
#REF! |  |  | #REF! | #REF! | #REF! | #REF!
#REF! |  |  | #REF! | #REF! | #REF! | #REF!
#REF! |  |  | #REF! | #REF! | #REF! | #REF!
#REF! |  |  | #REF! | #REF! | #REF! | #REF!
#REF! |  |  | #REF! | #REF! | #REF! | #REF!
#REF! |  |  | #REF! | #REF! | #REF! | #REF!
#REF! |  |  | #REF! | #REF! | #REF! | #REF!
#REF! |  |  | #REF! | #REF! | #REF! | #REF!
#REF! |  |  | #REF! | #REF! | #REF! | #REF!
#REF! |  |  | #REF! | #REF! | #REF! | #REF!
#REF! |  |  | #REF! | #REF! | #REF! | #REF!
#REF! |  |  | #REF! | #REF! | #REF! | #REF!
#REF! |  |  | #REF! | #REF! | #REF! | #REF!
#REF! |  |  | #REF! | #REF! | #REF! | #REF!
#REF! |  |  | #REF! | #REF! | #REF! | #REF!
#REF! |  |  | #REF! | #REF! | #REF! | #REF!
#REF! |  |  | #REF! | #REF! | #REF! | #REF!
#REF! |  |  | #REF! | #REF! | #REF! | #REF!
#REF! |  |  | #REF! | #REF! | #REF! | #REF!
#REF! |  |  | #REF! | #REF! | #REF! | #REF!
#REF! |  |  | #REF! | #REF! | #REF! | #REF!
#REF! |  |  | #REF! | #REF! | #REF! | #REF!
#REF! |  |  | #REF! | #REF! | #REF! | #REF!
#REF! |  |  | #REF! | #REF! | #REF! | #REF!
#REF! |  |  | #REF! | #REF! | #REF! | #REF!
#REF! |  |  | #REF! | #REF! | #REF! | #REF!
#REF! |  |  | #REF! | #REF! | #REF! | #REF!
#REF! |  |  | #REF! | #REF! | #REF! | #REF!
#REF! |  |  | #REF! | #REF! | #REF! | #REF!
#REF! |  |  | #REF! | #REF! | #REF! | #REF!
#REF! |  |  | #REF! | #REF! | #REF! | #REF!
#REF! |  |  | #REF! | #REF! | #REF! | #REF!
#REF! |  |  | #REF! | #REF! | #REF! | #REF!
#REF! |  |  | #REF! | #REF! | #REF! | #REF!
#REF! |  |  | #REF! | #REF! | #REF! | #REF!
#REF! |  |  | #REF! | #REF! | #REF! | #REF!
#REF! |  |  | #REF! | #REF! | #REF! | #REF!
#REF! |  |  | #REF! | #REF! | #REF! | #REF!
#REF! |  |  | #REF! | #REF! | #REF! | #REF!
#REF! |  |  | #REF! | #REF! | #REF! | #REF!
#REF! |  |  | #REF! | #REF! | #REF! | #REF!
#REF! |  |  | #REF! | #REF! | #REF! | #REF!
#REF! |  |  | #REF! | #REF! | #REF! | #REF!
#REF! |  |  | #REF! | #REF! | #REF! | #REF!
#REF! |  |  | #REF! | #REF! | #REF! | #REF!
#REF! |  |  | #REF! | #REF! | #REF! | #REF!
#REF! |  |  | #REF! | #REF! | #REF! | #REF!
#REF! |  |  | #REF! | #REF! | #REF! | #REF!
#REF! |  |  | #REF! | #REF! | #REF! | #REF!
#REF! |  |  | #REF! | #REF! | #REF! | #REF!
#REF! |  |  | #REF! | #REF! | #REF! | #REF!
#REF! |  |  | #REF! | #REF! | #REF! | #REF!
#REF! |  |  | #REF! | #REF! | #REF! | #REF!
#REF! |  |  | #REF! | #REF! | #REF! | #REF!
#REF! |  |  | #REF! | #REF! | #REF! | #REF!
#REF! |  |  | #REF! | #REF! | #REF! | #REF!
#REF! |  |  | #REF! | #REF! | #REF! | #REF!
#REF! |  |  | #REF! | #REF! | #REF! | #REF!
#REF! |  |  | #REF! | #REF! | #REF! | #REF!
#REF! |  |  | #REF! | #REF! | #REF! | #REF!
#REF! |  |  | #REF! | #REF! | #REF! | #REF!
#REF! |  |  | #REF! | #REF! | #REF! | #REF!
#REF! |  |  | #REF! | #REF! | #REF! | #REF!
#REF! |  |  | #REF! | #REF! | #REF! | #REF!
#REF! |  |  | #REF! | #REF! | #REF! | #REF!
#REF! |  |  | #REF! | #REF! | #REF! | #REF!
#REF! |  |  | #REF! | #REF! | #REF! | #REF!
#REF! |  |  | #REF! | #REF! | #REF! | #REF!
#REF! |  |  | #REF! | #REF! | #REF! | #REF!
#REF! |  |  | #REF! | #REF! | #REF! | #REF!
#REF! |  |  | #REF! | #REF! | #REF! | #REF!
#REF! |  |  | #REF! | #REF! | #REF! | #REF!
#REF! |  |  | #REF! | #REF! | #REF! | #REF!
#REF! |  |  | #REF! | #REF! | #REF! | #REF!
#REF! |  |  | #REF! | #REF! | #REF! | #REF!
#REF! |  |  | #REF! | #REF! | #REF! | #REF!
#REF! |  |  | #REF! | #REF! | #REF! | #REF!
#REF! |  |  | #REF! | #REF! | #REF! | #REF!
#REF! |  |  | #REF! | #REF! | #REF! | #REF!
#REF! |  |  | #REF! | #REF! | #REF! | #REF!
#REF! |  |  | #REF! | #REF! | #REF! | #REF!
#REF! |  |  | #REF! | #REF! | #REF! | #REF!
#REF! |  |  | #REF! | #REF! | #REF! | #REF!
#REF! |  |  | #REF! | #REF! | #REF! | #REF!
#REF! |  |  | #REF! | #REF! | #REF! | #REF!
#REF! |  |  | #REF! | #REF! | #REF! | #REF!
#REF! |  |  | #REF! | #REF! | #REF! | #REF!
#REF! |  |  | #REF! | #REF! | #REF! | #REF!
#REF! |  |  | #REF! | #REF! | #REF! | #REF!
#REF! |  |  | #REF! | #REF! | #REF! | #REF!
#REF! |  |  | #REF! | #REF! | #REF! | #REF!
#REF! |  |  | #REF! | #REF! | #REF! | #REF!
#REF! |  |  | #REF! | #REF! | #REF! | #REF!
#REF! |  |  | #REF! | #REF! | #REF! | #REF!
#REF! |  |  | #REF! | #REF! | #REF! | #REF!
#REF! |  |  | #REF! | #REF! | #REF! | #REF!
#REF! |  |  | #REF! | #REF! | #REF! | #REF!
#REF! |  |  | #REF! | #REF! | #REF! | #REF!
#REF! |  |  | #REF! | #REF! | #REF! | #REF!
#REF! |  |  | #REF! | #REF! | #REF! | #REF!
#REF! |  |  | #REF! | #REF! | #REF! | #REF!
#REF! |  |  | #REF! | #REF! | #REF! | #REF!
#REF! |  |  | #REF! | #REF! | #REF! | #REF!
#REF! |  |  | #REF! | #REF! | #REF! | #REF!
#REF! |  |  | #REF! | #REF! | #REF! | #REF!
#REF! |  |  | #REF! | #REF! | #REF! | #REF!
#REF! |  |  | #REF! | #REF! | #REF! | #REF!
#REF! |  |  | #REF! | #REF! | #REF! | #REF!
#REF! |  |  | #REF! | #REF! | #REF! | #REF!
#REF! |  |  | #REF! | #REF! | #REF! | #REF!
#REF! |  |  | #REF! | #REF! | #REF! | #REF!
#REF! |  |  | #REF! | #REF! | #REF! | #REF!
#REF! |  |  | #REF! | #REF! | #REF! | #REF!
#REF! |  |  | #REF! | #REF! | #REF! | #REF!
#REF! |  |  | #REF! | #REF! | #REF! | #REF!
#REF! |  |  | #REF! | #REF! | #REF! | #REF!
#REF! |  |  | #REF! | #REF! | #REF! | #REF!
#REF! |  |  | #REF! | #REF! | #REF! | #REF!
#REF! |  |  | #REF! | #REF! | #REF! | #REF!
#REF! |  |  | #REF! | #REF! | #REF! | #REF!
#REF! |  |  | #REF! | #REF! | #REF! | #REF!
#REF! |  |  | #REF! | #REF! | #REF! | #REF!
#REF! |  |  | #REF! | #REF! | #REF! | #REF!
#REF! |  |  | #REF! | #REF! | #REF! | #REF!
#REF! |  |  | #REF! | #REF! | #REF! | #REF!
#REF! |  |  | #REF! | #REF! | #REF! | #REF!
#REF! |  |  | #REF! | #REF! | #REF! | #REF!
#REF! |  |  | #REF! | #REF! | #REF! | #REF!

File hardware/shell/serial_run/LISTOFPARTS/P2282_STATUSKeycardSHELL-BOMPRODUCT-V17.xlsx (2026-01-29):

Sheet: Historic
 | PRODUCT BOM |  |  |  |  |  |  | T - Rev. L Linked to CP04
Nr PROJECT | P2282 | CUSTOMER | STATUS | PROJECT NAME | KPRO
 |  |  |  |  |  | R&D, Method PE, PM | AI by PMF, AIS by PMC
DATE | HISTORY OF MODIFICATIONS |  |  |  |  | Author | Validation | BOM VERSION
2024-09-23 | Creation |  |  |  |  | RP |  | V00
2024-09-30 | Upadte with Electonics parts |  |  |  |  | DL |  | V01
2024-12-10 | Indice sup. TOP - KEYBOARD SLEEVE |  |  |  |  | RP |  | V02
2024-12-13 | Indice sup. TOP - MIDDLE FRAME - SIDE BUTTON - BOTTOM COVER |  |  |  |  | RP |  | V03
2024-12-20 | Indice sup. TOP - KEYBOARD SLEEVE, SIDE BUTTON, CAMERA FOAM |  |  |  |  | RP |  | V04
2024-12-30 | Indice sup. SIDE BUTTON |  |  |  |  | RP |  | V05
2025-01-10 | Indice sup. MIDDLE FRAME - BOTTOM COVER |  |  |  |  | RP |  | V06
2025-02-10 | Indice sup. KEYBOARD SLEEVE |  |  |  |  | RP |  | V07
2025-03-10 | Indice sup. KEYBOARD SLEEVE |  |  |  |  | RP |  | V08
2025-03-11 | Indice sup. KEYBOARD SLEEVE |  |  |  |  | RP |  | V09
2025-03-25 | Indice sup. KEYBOARD SLEEVE |  |  |  |  | RP |  | V10
2025-04-02 | AIS Creation |  |  |  |  | rebecca | KEN | V11
2025-09-15 | 1.change the description of 4010000281 from STA-P2282-WINDOW to STA-P2282-WINDOW WITH PROTECTION，change the description of 4010000282 from STA-P2282-CAMERA WINDOW to STA-P2282-CAMERA WINDOW WITH PROTECTION 2.Add STA-P2282-START REGULATORY LEAFLET,qty:1 3.add STA-P2282-START ANTI-TAMPER STICKER,qty:1 4.add STA-P2282-SIM CARD，qty：2 |  |  |  |  | rebecca | KEN | V12
2025-09-19 | 1.add 'CARTON LAYER 355x335x3,qty:1/60 2.add 'CARTON RSB 370x350x285 ,qty:1/60 3.add 'PALLET SEA 1130x790x130 ,qty:1/2520 |  |  |  |  | rebecca | KEN | V13
2025-10-09 | 1.add STA-P2282-KEYBOARD SLEEVE，qty：1 |  |  |  |  | rebecca | KEN | V14
2025-11-17 | 1.add STICKER PAPER PET 30x20 WHITE，qty：1 2.add 'STICKER PAPER 100x75 WHITE，qty：2/60 3.change product name from STA-P2282-STATUS KPRO to STA-P2282-STATUS Keycard SHELL |  |  |  |  | rebecca | KEN | V15
2025-11-20 | 1.add STICKER PAPER 10x10 WHITE，qty：1 |  |  |  |  | rebecca | KEN | V16
2025-12-15 | 1.Change BOM format 2.change description of 5050010572 from 'CARTON RSB 370x350x285 to CARTON RSB 365x340x285 3.change description of 5050020251 from 'CARTON LAYER 355x335x3 to 350x325x3 |  |  |  |  | rebecca | KEN | V17

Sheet: Product BOM
 |  | PARTS LIST and PRODUCT BOM |  |  |  |  |  | T - Rev. L Linked to CP04
 |  | Nr PROJECT | P2282 | PROJECT NAME |  |  | 0
Method | R&D (or PMF if no conception) first --> Method codification --> PMF validation --> R&D confirmation | Method AIS | Method | Customer service --> HG validation | PMF | R&D (Method if no conception) | Method | Method | MIF production manager | R&D (PMF if no conception) | R&D | PMF | R&D (PMF if no conception) | PMF | R&D (PMF if no conception) | PMF | R&D (PMF if no conception) | R&D (PMF if no conception) | R&D (PMF if no conception) | Automation
Part number and level | ALTYOR part / product name (EN) | ALTYOR part / product name (CN) | ERP AIS | ERP AI NODON | Customer P/N | STA-P2282-STATUS Keycard SHELL | Manufacturing type | Unit (pc, m, L, kg) | Consumable (Y/N) | Reference drawing | Rev. in progress | Rev. Validated | Process | Recycled Material Eligibility (Y/N) | Material | Material ref | Colour | Finishing | Volume ( cm3) 1st fill for DFM Final update for SR | Mass (g) 1st fill for DFM Final update for SR
1 | STA-P2282-STATUS Keycard SHELL | 电子钱包 | 1010000627 |  |  | 1 | M
1.1 | STA-P2282-TOP | 上盖 | 4010022451 |  |  | 1 | P |  |  | 2282-001 | 03 |  | INJECTION |  | R-ABS |  | BLACK RAL9004 | YS 1282 | 9.8 | 10.192
1.2 | STA-P2282-MIDDLE FRAME | 框架 | 4010022461 |  |  | 1 | P |  |  | 2282-002 | 02 |  | INJECTION |  | R-ABS |  | BLACK RAL9004 | YS 1282 | 12.5 | 13
1.3 | STA-P2282-BOTTOM COVER | 底盖 | 4010022471 |  |  | 1 | P |  |  | 2282-004 | 02 |  | INJECTION |  | R-ABS |  | BLACK RAL9004 | YS 1282 | 8.7 | 9.048
1.4 | STA-P2282-SIDE BUTTON | 侧按键 | 4010022481 |  |  | 1 | P |  |  | 2282-003 | 03 |  | INJECTION |  | R-ABS |  | BLACK RAL9004 | YS 1282 | 0.1 | 0.104
1.5 | STA-P2282-KEYBOARD SLEEVE | 键盘封套 | 4010022841 |  |  | 1 | P |  |  | 2282-005 | 07 |  | COMPRESSION |  | Silicone |  | BLACK RAL9004 | PAINTING | 4.9 | 6.37
1.6 | STA-P2282-WINDOW WITH PROTECTION | 窗户 | 4010000281 |  |  | 1 | P |  |  | 2282-006 | 00 |  | CUTTING |  | PC |  | TRANSPARENT | SERIGRAPHY | 2 | 2.4
1.6.1 | STA-P2282-WINDOW |  | - |  |  | 1 | P
1.6.2 | STA-P2282- WINDOW PROTECTION |  | - |  |  | 1 | P
1.7 | STA-P2282-CAMERA WINDOW WITH PROTECTION | 相机窗户 | 4010000282 |  |  | 1 | P |  |  | 2282-007 | 00 |  | CUTTING |  | PC |  | TRANSPARENT | SERIGRAPHY | 0.1 | 0.12
1.7.1 | STA-P2282-CAMERA WINDOW |  | - |  |  | 1 | P
1.7.2 | STA-P2282- CAMERA WINDOW PROTECTION |  | - |  |  | 1 | P
1.8 | STA-P2282-WINDOW ADHESIVE | 相机双面胶 | 5050050413 |  |  | 1 | P |  |  | 2282-008 | 00 |  | CUTTING |  | FOAM | DUAL TAPE | BLACK |  | 0.2 | 0.02
1.9 | STA-P2282-ANTI DUST FOAM | 海绵 | 5050050414 |  |  | 1 | P |  |  | 2282-009 | 00 |  | CUTTING |  | FOAM | PE SINGLE TAPE | BLACK |  | 3 | 0.3
1.10 | STA-P2282-CAMERA WINDOW ADHESIVE | 相机窗户双面胶 | 5050050415 |  |  | 1 | P |  |  | 2282-010 | 00 |  | CUTTING |  | FOAM | DUAL TAPE | BLACK |  | 0.1 | 0.01
1.11 | STA-P2282-CAMERA FOAM | 相机海绵 | 5050050416 |  |  | 1 | P |  |  | 2282-011 | 01 |  | CUTTING |  | FOAM | PE DUAL TAPE | BLACK |  | 0.2 | 0.02
1.12 | STA-P2282-PCBA KCP | KCP PCBA | 4030005433 |  |  | 1 | C |  |  | FLX-2208-61x | 3.0.0 |  | ELEC
1.13 | STA-P2282-PCBA FLX | FLX PCBA | 4030005432 |  |  | 1 | C |  |  | FLX-2208-61x | 3.0.0 |  | ELEC
1.14 | CAMERA HONGJIA AS-DGSG8AH530D20 | 相机 | 4030005594 |  |  | 1 | P |  |  | AS-DGSG8AH530D20-45-241112 |  |  |  |  |  | AS-DGSG8AH530D20
1.15 | BATTERY DEJI BL-4C | 锂电池 890mAh | 4030005595 |  |  | 1 | P |  |  |  |  |  | SOURCING
1.16 | SCREEN OPSTEK YDP200B003-V1 | 屏幕 | 4030005596 |  |  | 1 | P |  |  | OPSTEK - YDP200B003-V1 |  |  | SOURCING |  |  | OPSTEK - YDP200B003-V1
1.17 | USB CABLE 30CM (USB-C MALE to USB-C MALE) | USB数据线 30CM | 4030005597 |  |  | 1 | P
1.18 | STA-P2282-SIM CARD | SIM 卡 (客供) | 4030005681 |  |  | 2 | P |  |  |  |  |  |  |  |  |  |  |  |  | 5.1
1.19 | STA-P2282-SHELL PACKAGING | 产品盒 | 5050030981 |  |  | 1 | P |  |  |  |  |  |  |  |  |  |  |  |  | 33.6
1.20 | STA-P2282-START REGULATORY LEAFLET | 监管传单 | 5050041713 |  |  | 1 | P |  |  |  |  |  |  |  |  |  |  |  |  | 3.12
1.21 | STA-P2282-START ANTI-TAMPER STICKER | 防拆标贴 | 5050041714 |  |  | 1 | P |  |  |  |  |  |  |  |  |  |  |  |  | 0.1
1.22 | STA-P2282-KEYCARD HOLDER | SIM 卡封套 | 5050030982 |  |  | 1 | P |  |  |  |  |  |  |  |  |  |  |  |  | 5
1.23 | STA-P2282-START CARD | 二维码说明书 | 5050041695 |  |  | 1 | P |  |  |  |  |  |  |  |  |  |  |  |  | 1.4
1.24 | STICKER PAPER PET 30x20 WHITE | 标贴纸 PET 30x20 白色 (IDRF) | 5050040912 |  |  | 1 | P
1.25 | STICKER PAPER 100x75 WHITE | 标贴纸 100x75 白色 | 5050040102 |  |  | 2/60 | P
1.26 | STICKER PAPER 10x10 WHITE | 标贴纸 10x10 白色 | 5050041243 |  |  | 1 | P |  |  |  |  |  |  |  |  |  |  |  |  | 0.0064
1.27 | CARTON LAYER 350x325x3 | 衬板 350x325x3 | 5050020251 |  |  | 1/60 | P |  |  |  |  |  |  |  |  |  |  |  |  | 51
1.28 | CARTON RSB 365x340x285 | 纸箱 365x340x285 | 5050010572 |  |  | 1/60 | P |  |  |  |  |  |  |  |  |  |  |  |  | 640
1.29 | PALLET SEA 1130x790x130 | 免熏蒸托盘 1130x790x130 | 5050090201 |  |  | 1/2520 | P
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

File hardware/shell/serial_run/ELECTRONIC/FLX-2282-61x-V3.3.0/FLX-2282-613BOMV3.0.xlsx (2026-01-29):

 |  | FLX-2282-613 BOM V3.0 |  |  |  |  |  |  |  |  | Date: | 02/01/2025
 |  |  |  |  |  |  |  |  |  |  | Ref BOM: | 2282
 |  | STATUS K |  |  |  |  |  |  |  |  | Revision: | V3.0
Qty | Designator | Description | Manufacturer | Reference | Supplier | Comment | Footprint | Generic | Article Code | Manufacture_Cnd | ERP SF Code | ERP Code | RoHS | Lifecycle | Y-to-EOL | History
 | Designator | Description | MANUFACTURER | Comment |  | NAME | Footprint | GENERIC | ARTICLE CODE | MANUFACTURE_CND | ERP SF CODE | ERP CODE
0 | Mire Top 1, Mire Top 2 | Mire |  | DNI |  | DNI | MIRE
1 | P2 | 8 Positions connecteur de carte Micro SIM Montage en surface Ã angle droit Or avec commutateur | AMPHENOL | 7311S0725A01LF |  | 8P READER | 7311S0725A01LF | False | MSR 649-7311S0725A01LF |  |  | 10-*
0
1

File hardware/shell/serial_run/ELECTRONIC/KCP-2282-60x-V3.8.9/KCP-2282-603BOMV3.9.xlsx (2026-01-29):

 |  | #VALUE! |  |  |  |  |  |  |  |  | Date: | 18/11/2025
 |  |  |  |  |  |  |  |  |  |  | Ref BOM: | 2282
 |  | STATUS K |  |  |  |  |  |  |  |  | Revision: | V3.9
Qty | Designator | Description | Manufacturer | Reference | Supplier | Comment | Footprint | Generic | Article Code | Manufacture_Cnd | ERP SF Code | ERP Code | RoHS | Lifecycle | Y-to-EOL | History
 | Designator | Description | MANUFACTURER | Comment |  | NAME | Footprint | GENERIC | ARTICLE CODE | MANUFACTURE_CND | ERP SF CODE | ERP CODE
18 | C1, C4, C5, C6, C13, C14, C17, C21, C23, C25, C26, C31, C32, C33, C34, C44, C46, C52 | CAP X5R 4.7µF 25V ±10% 0805 | WALSIN | 0805X475M250CT |  | 4.7µF | 0805 - CAPACITOR | True | MSR 791-0805X475M250CT |  | 4 | 10-*
19 | C2, C9, C15, C16, C19, C24, C27, C35, C36, C37, C38, C40, C42, C45, C47, C53, C54, C300, C302 | CAP X7R 100nF 50V ±10% 0402 | WALSIN | 0402B104K500CT |  | 100nF | 0402 - CAPACITOR | True | MSR 791-0402B104K500CT |  | 4 | 10-*
1 | C3 | CAP X5R 4.7µF 10V ±10% 0402 | YAGEO | CC0402KRX5R6BB475 |  | 4.7µF | 0402 - CAPACITOR | True | MSR 603-CC0402KR5R6BB475 |  | 4 | 10-*
9 | C7, C8, C10, C11, C12, C39, C41, C48, C49 | CAP X5R 1µF 50V ±10% 0603 | WALSIN | 0603X105K500CT |  | 1µF | 0603 - CAPACITOR | True | MSR 791-0603X105K500CT |  | 4 | 10-*
1 | C28 | CAP COG 9pF 50V ±0.1pF 0402 | WALSIN | 0402N9R0B500CT |  | 9pF | 0402 - CAPACITOR | True | MSR 791-0402N220F500CT |  | 4 | 10-*
2 | C29, C30 | CAP X5R 2.2µF 50V ±10% 0805 | WALSIN | 805X225M500CT |  | 2.2µF | 0805 - CAPACITOR | True | MSR 791-805X225M500CT |  | 4 | 10-*
1 | D1 | diode TVS, 82400 Series, Bidirectionelle | Würth | 824001 |  | ESD 5V | SOT23-6 0.95 Var AA | False | MSR 710-824001 |  |  | 10-*
1 | D2 | Osram Opto Micro SIDELED Series Red LED, 120 Source: Datasheet | OSRAM | LR_Y8SF-U1V2-1 |  | LR Y8SF-U1V2-1 | OSRAM LRY8SFU1V21 | Flase | MSR 720-LRY8SFU1V21 |  | 5 | 10-*
3 | D3, D4, D5 | Schottky Rectifier, 30 V, 500 mA, Single | ON SEMI | MBR0530-TP |  | MBR0530 | SOD123 DIODE INC | False | MSR 833-MBR0530-TP, MSR 863-MBR0530-TP, MSR 863-MBR0530-TP |  |  | MBR0530-*
1 | D6 | Zener 3V, 300mW - SOD 523-3 | NXP | BZX585-C3V0,135 |  | 3V | SOD523 TOSHIBA | False | MSR 771-BZX585-C3V0135
1 | F1 | FUSE 500mA 6V 0805 | JNHONGBAO | BNP05000F000 |  | 500mA@32V | 0805 - FUSE | False | 530-0ZCK0050FF2E | '0ZCK0050FF2E/0402L050SLKR | BNP05000F000 | 10-*
1 | F2 | PTC Resettable Fuse 0.75A(hold) 1.5A(trip) 6VDC 40A 0.6W 0.2s 0.09Ohm SMD Solder Pad 0805 T/R Automotive Source: Datasheet | Bel Circuit Protection | 0ZCK0075FF2E |  | 1.5A@6V | 0805 - FUSE | False | MSR 530-0ZCK0075FF2E |  |  | 10-*
1 | IC2 | DCDC 2V5..5V5 50µA 1V8..3V3 | SILERGY | SY8088IAAC |  | SY8088 | SOT23-5 0.95 Var AA | False | LCSC C479072
1 | J2 | 0.5mm Side entry Flat Flexible Cable Connector, 12pin, bottom contacts | GCT | FFC2B35-12-G |  | FFC2B35-12-G | GCT FFC2B35-12-G | False | MSR 640-FFC2B35-12-G |  | 14 | 10-*
1 | J4 | Connecteurs FFC et FPC FFC/FPC 6 positions, 1mm, right angle, bottom contact | JUSHUO | AFA07-S06FCA-00 |  | 6x1 | JUSHUO AFA07-S15FCC-00 | False | LCSC C72727 |  | 11 | 10-*
1 | J6 | Connecteurs carte Ã carte et mezzanine BATTERY CONN 3 POSITION | TE Connectivity | 1982633-1 |  | 3pts | TE 19826331 | False | MSR 571-1982633-1 |  |  | 10-*
1 | J8 | Connecteurs USB USB C Rec 16P 3u" Mid Mnt 1.6mm O-set SMT L = 6.5mm S-Spring | ANTENK | U6252-35c |  | USB-C | ANTENK U6252-35C | False |  |  |  | 10-*
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

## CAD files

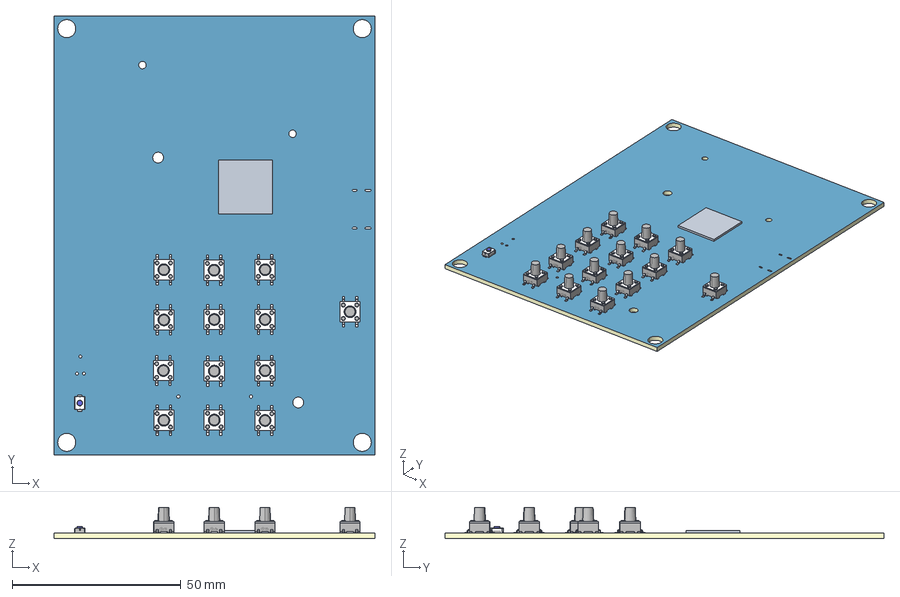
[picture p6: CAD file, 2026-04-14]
hardware/development_board/devboard_v2/3D_KCP-2282-601-PCBV3.8_2026-03-03.step
95.0 x 130.0 x 9.22 mm
Board~cQMr
TopCopper~cQMr
BottomCopper~cQMr
TopFpcStiffener~cQMr
BottomFpcStiffener~cQMr
SW-SMD_L4.0-W3.0-LS4.8~SW-SMD_L4.0-W3.0-LS4.8~cQMr
LQFP-100_L14.0-W14.0-P0.50-LS16.0-BL~LQFP-100_ L14.0-W14.0-H1.4-LS16.0-P0.50~cQMr
KEY-SMD_4P-L6.0-W6.0-P3.90-LS9.0~KEY-SMD_ 4P-L6.0-W6.0-H8.0-P3.90-LS9.0~cQMr x 13

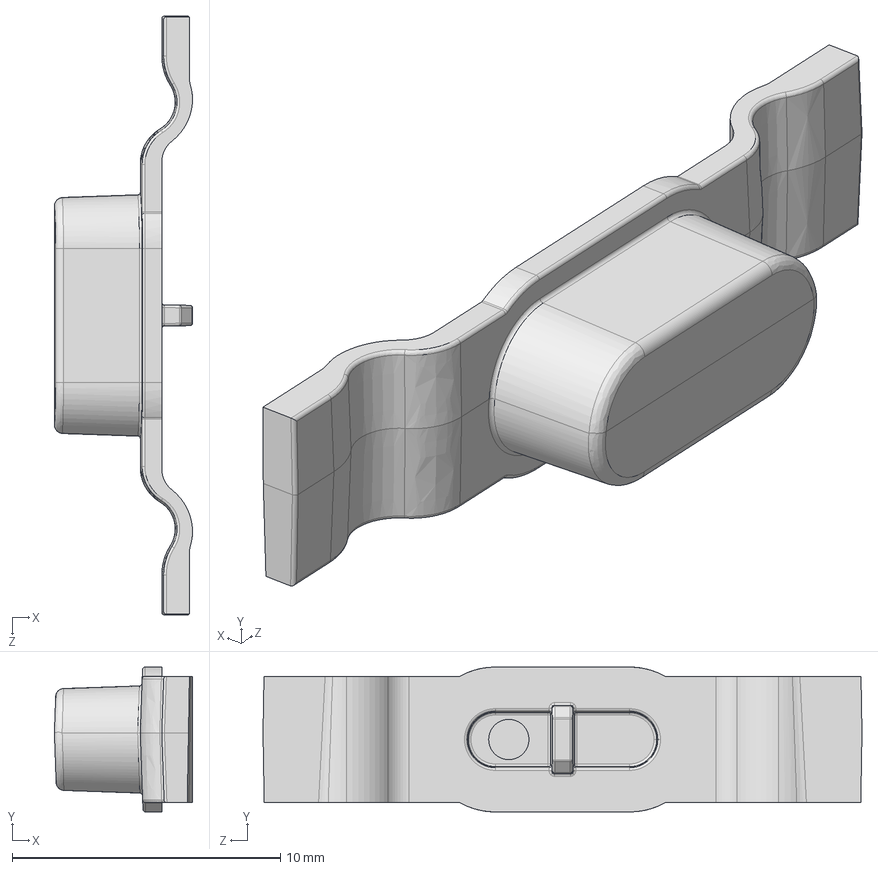
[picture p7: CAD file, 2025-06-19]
hardware/shell/pilot_run/mechanical/parts/2282-003-SIDEBUTTON-V04-20250514.STEP
5.15 x 5.40 x 22.3 mm

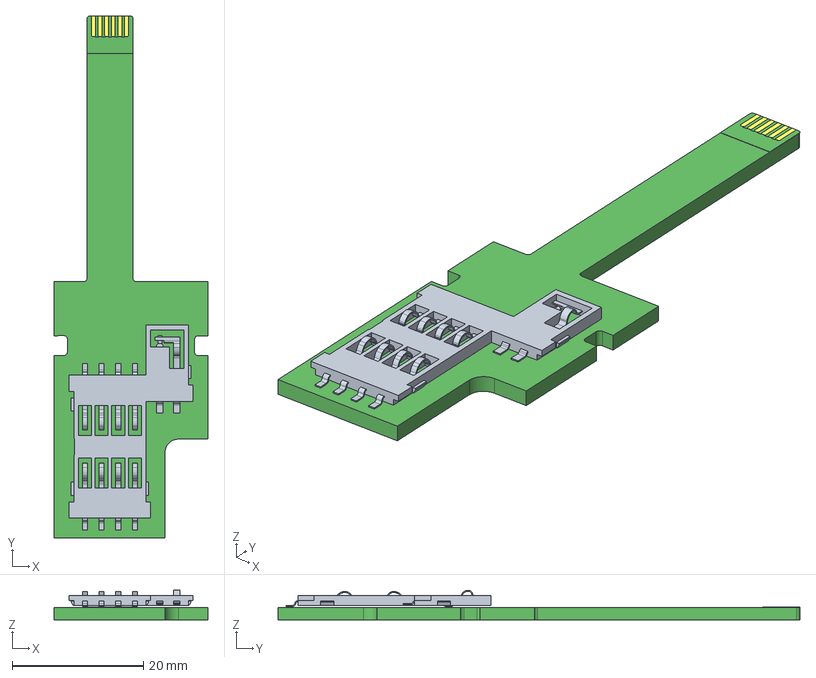
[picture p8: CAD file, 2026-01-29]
hardware/shell/prototype_P2/electronics/FLXandKCP2282/FLX-2282-618 3D V3.2.step
23.4 x 79.5 x 4.49 mm
Board
Extruded x 12
7311S0725A01LF

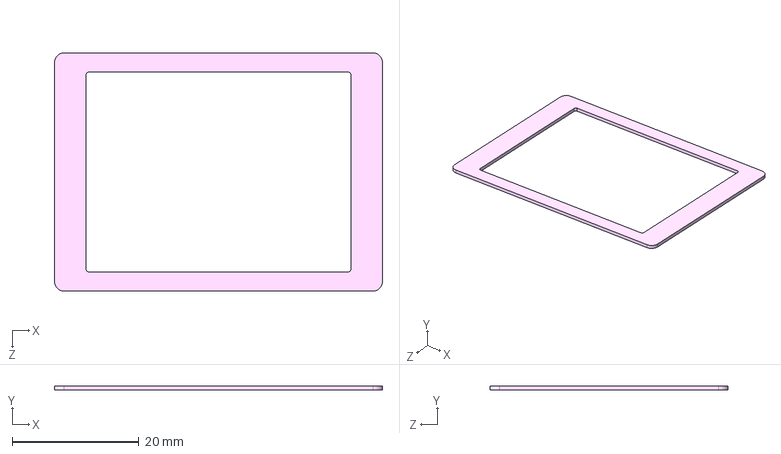
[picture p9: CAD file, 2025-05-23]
hardware/shell/prototype_P2/mechanical/parts/2282-009-ANTIDUSTFOAM-V00-20241128.STEP
51.8 x 0.7 x 37.6 mm

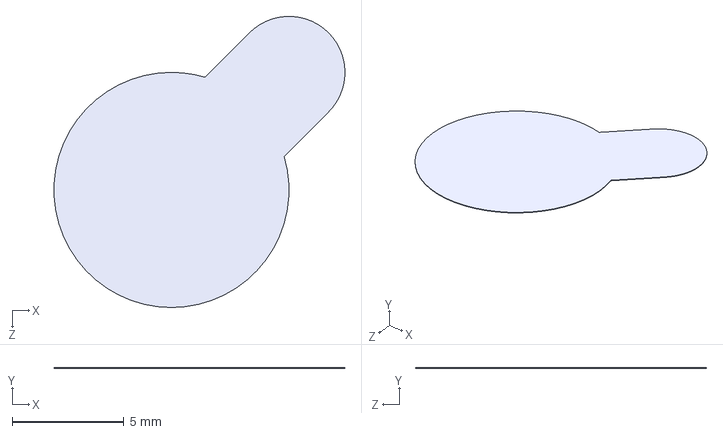
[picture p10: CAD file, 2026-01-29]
hardware/shell/serial_run/MECHANICAL/3Ddrawings/2282-013-CAMERAWINDOWPROTECTION-V01-20250718.STEP
13.0 x 0.03 x 13.0 mm

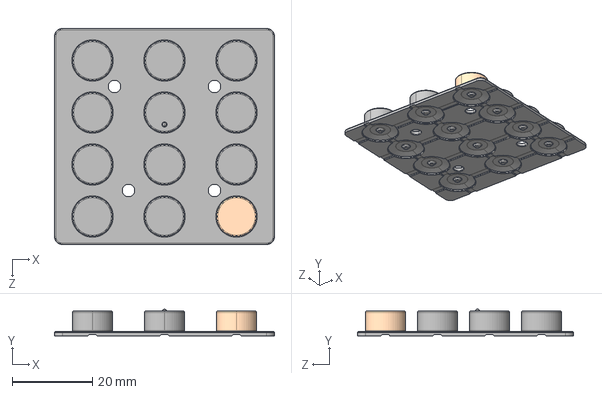
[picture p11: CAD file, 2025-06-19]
hardware/shell/pilot_run/mechanical/parts/2282-005-KEYBOARDSLEEVE-V07-20250325.STEP
55.0 x 6.70 x 54.0 mm

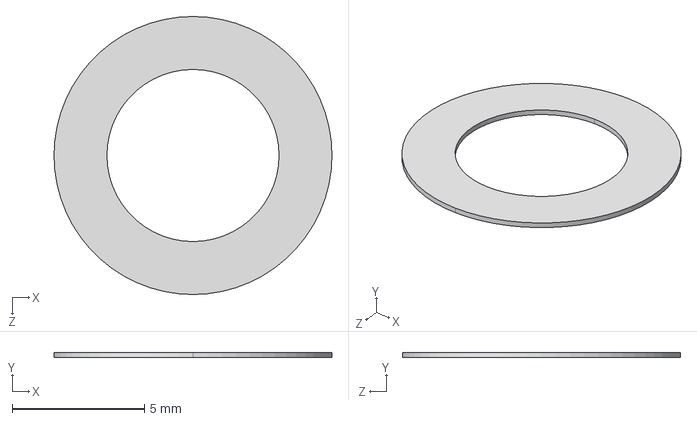
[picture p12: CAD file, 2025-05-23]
hardware/shell/prototype_P2/mechanical/parts/2282-010-CAMERAWINDOWADHESIVE-V00-20241128.STEP
10.5 x 0.2 x 10.5 mm

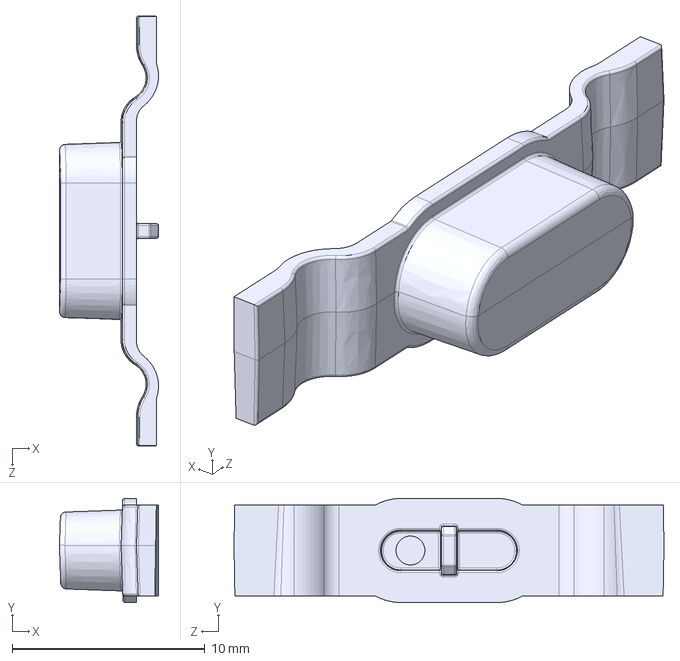
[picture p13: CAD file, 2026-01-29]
hardware/shell/serial_run/MECHANICAL/3Ddrawings/2282-003-SIDEBUTTON-V06-20250903.STEP
5.15 x 5.40 x 22.3 mm

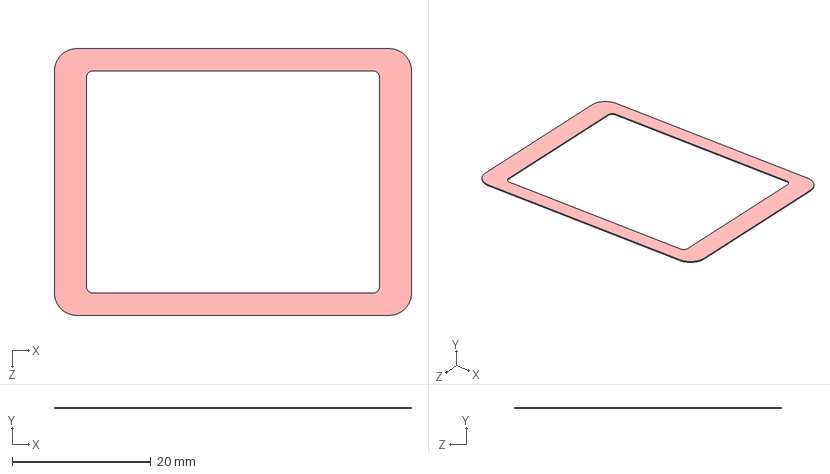
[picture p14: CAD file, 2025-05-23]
hardware/shell/pilot_run/mechanical/parts/2282-008-WINDOWADHESIVE-V00-20241128.STEP
51.4 x 0.2 x 38.4 mm

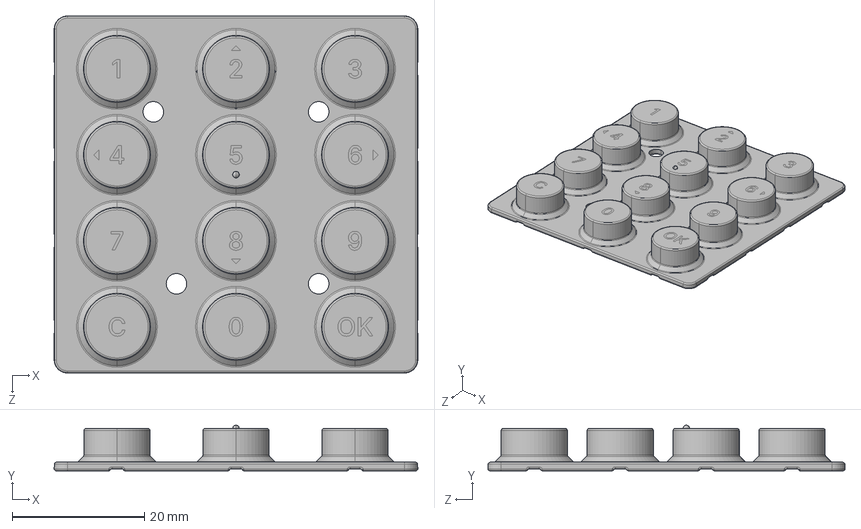
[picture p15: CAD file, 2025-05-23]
hardware/shell/prototype_P2/mechanical/parts/2282-005-KEYBOARDSLEEVE-V02-20241219.STEP
55.0 x 6.90 x 54.0 mm

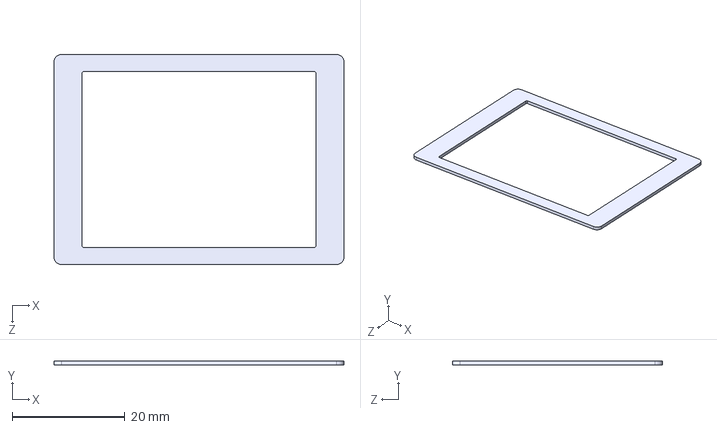
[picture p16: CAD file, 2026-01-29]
hardware/shell/serial_run/MECHANICAL/3Ddrawings/2282-009-ANTIDUSTFOAM-V01-20250630.STEP
51.4 x 0.7 x 37.2 mm

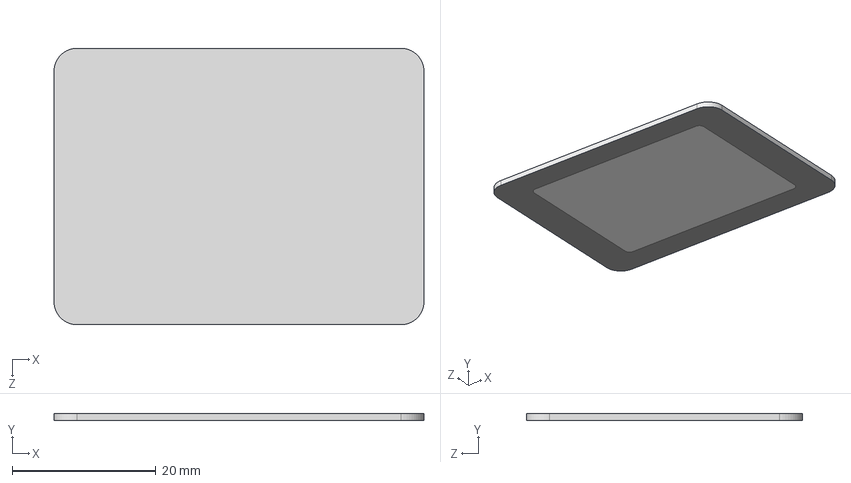
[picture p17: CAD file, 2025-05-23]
hardware/shell/pilot_run/mechanical/parts/2282-006-WINDOW-V00-20241128.STEP
51.4 x 1.00 x 38.4 mm

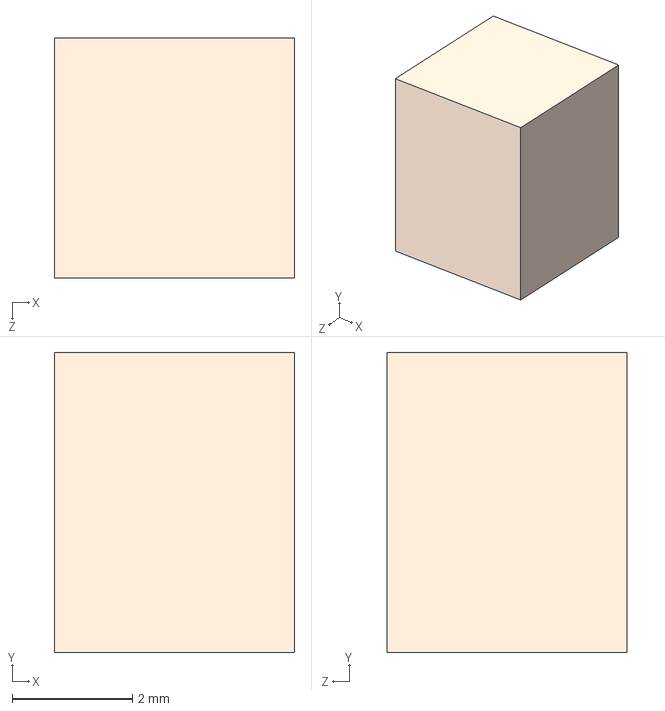
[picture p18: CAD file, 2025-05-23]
hardware/shell/prototype_P2/mechanical/parts/2282-011-CAMERAFOAM-V01-20241220.STEP
4.00 x 5.00 x 4.00 mm

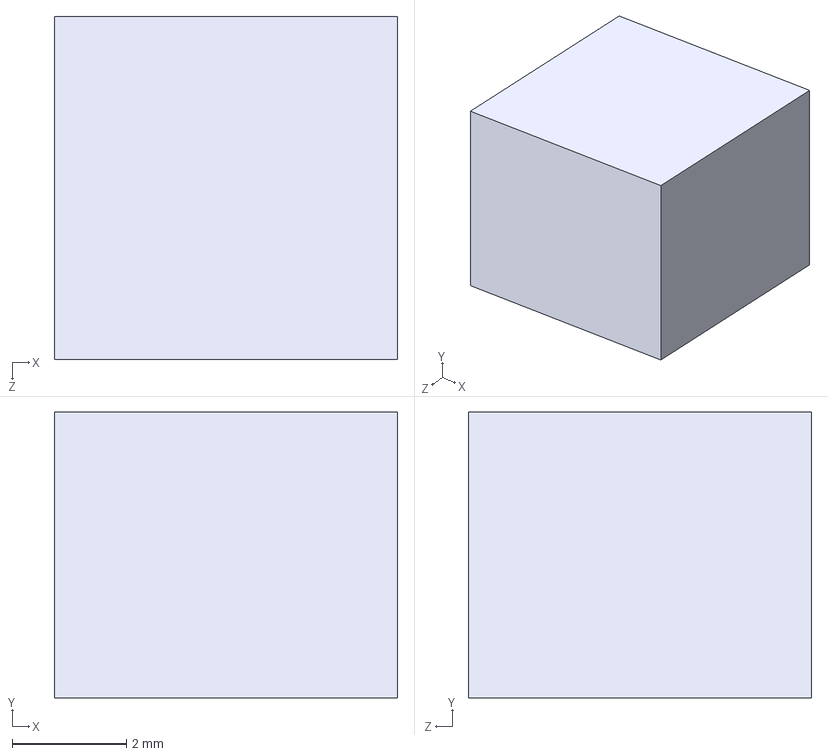
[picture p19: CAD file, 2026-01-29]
hardware/shell/serial_run/MECHANICAL/3Ddrawings/2282-011-CAMERAFOAM-V02-20250630.STEP
6.00 x 5.00 x 6.00 mm

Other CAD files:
hardware/shell/serial_run/MECHANICAL/3Ddrawings/2282-008-WINDOWADHESIVE-V01-20250630.STEP
hardware/shell/prototype_P2/mechanical/parts/2282-003-SIDEBUTTON-V02-20241220.STEP
hardware/shell/serial_run/MECHANICAL/3Ddrawings/2282-012-WINDOWPROTECTION-V01-20250718.STEP

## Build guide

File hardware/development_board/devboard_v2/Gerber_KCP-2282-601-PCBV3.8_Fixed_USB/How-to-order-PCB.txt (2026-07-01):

How to Order PCB

Please refer to:
https://prodocs.easyeda.com/en/pcb/order-order-pcb/index.html

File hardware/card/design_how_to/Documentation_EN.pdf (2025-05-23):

## File preparation for smart card printing

### Presentation of the smart card template

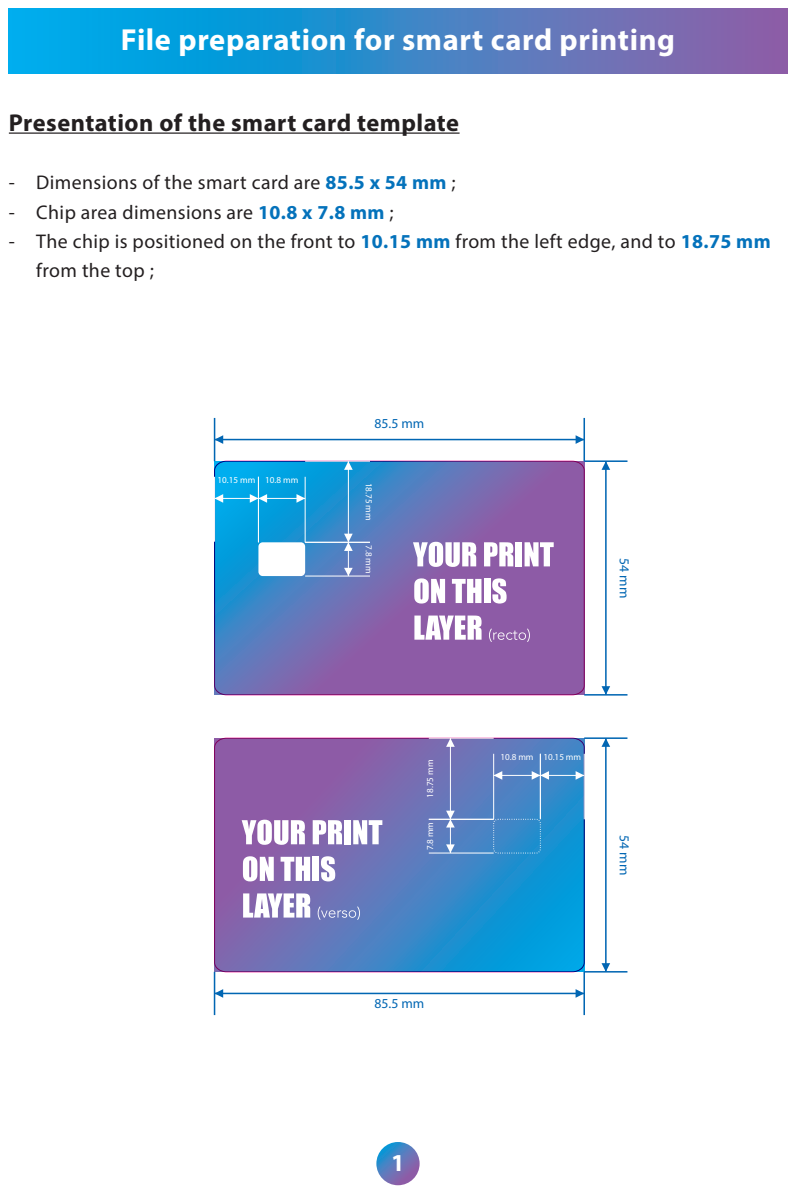
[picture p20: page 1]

- Dimensions of the smart card are 85.5 x 54 mm ;
- Chip area dimensions are 10.8 x 7.8 mm ;
- The chip is positioned on the front to 10.15 mm from the left edge, and to 18.75 mm
from the top ;

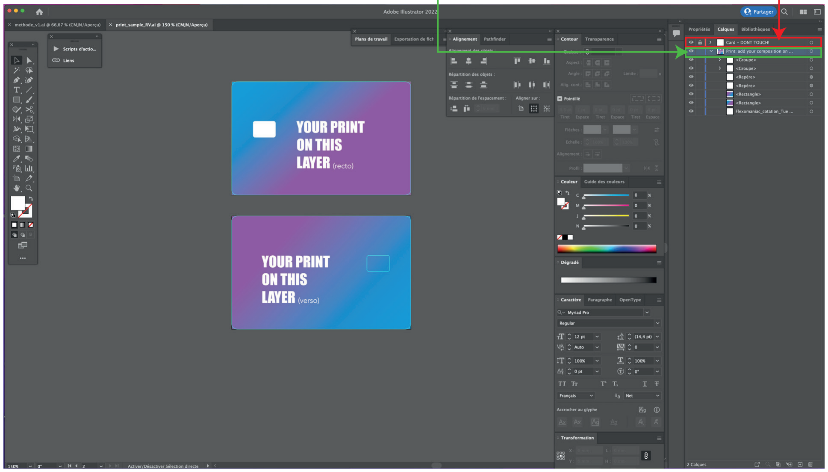
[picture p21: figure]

2

### Use of provided templates

### 2 les are provided:

- 1 le print_sample_RV.ai (can be edited in Adobe Illustrator) ;
- 1 le print_sample_RV.indd (can be edited in Adobe In Design) ;

Each le has 2 layers:
- 1 layer Card - DONT TOUCH! ;
- 1 layer Print: add your composition on this layer ;

WARNING:
The layer Card - DONT TOUCH! must not be manipulated: on this layer is the chip area without printing.
The layer Print: add your composition on this layer is the layer on which you must add your composition.
WORKING LAYER | DO NOT TOUCH !

Example in Adobe Illustrator

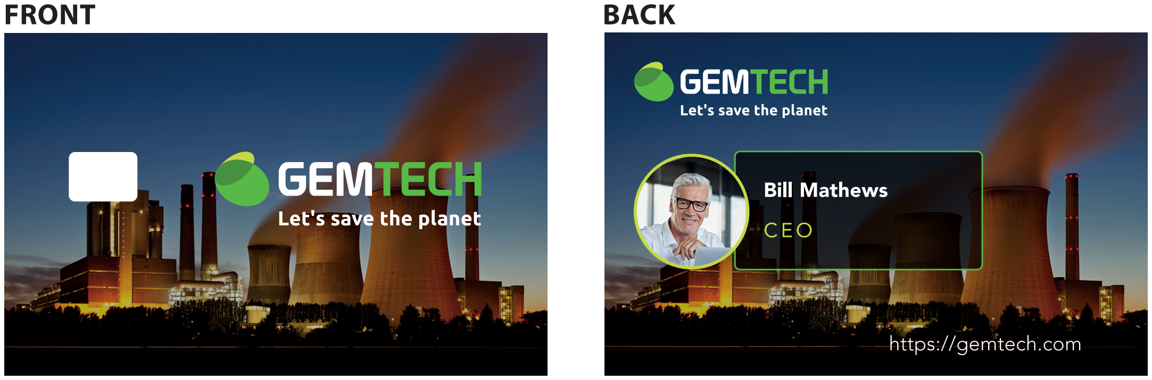
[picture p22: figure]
FRONT; BACK

3

### Recommendations and best practices

For double-sided printing of a smart card you must:
- 1) Add your composition on the layer Print: add your composition on this layer of the .AI or .INDD document ;
- 2) Incorporate each image (or media) with the Link panel of your Adobe software ;
- 3) Vectorize all texts of the document ;
- 4) Save the le to be printed to the .PDF format, without landmarks, and without bleed edge ;
- 5) The .PDF le you will return to us must be exactly like the le print_sample_R-V_preview.pdf provided as an example ;

print_sample_RV_preview.pdf

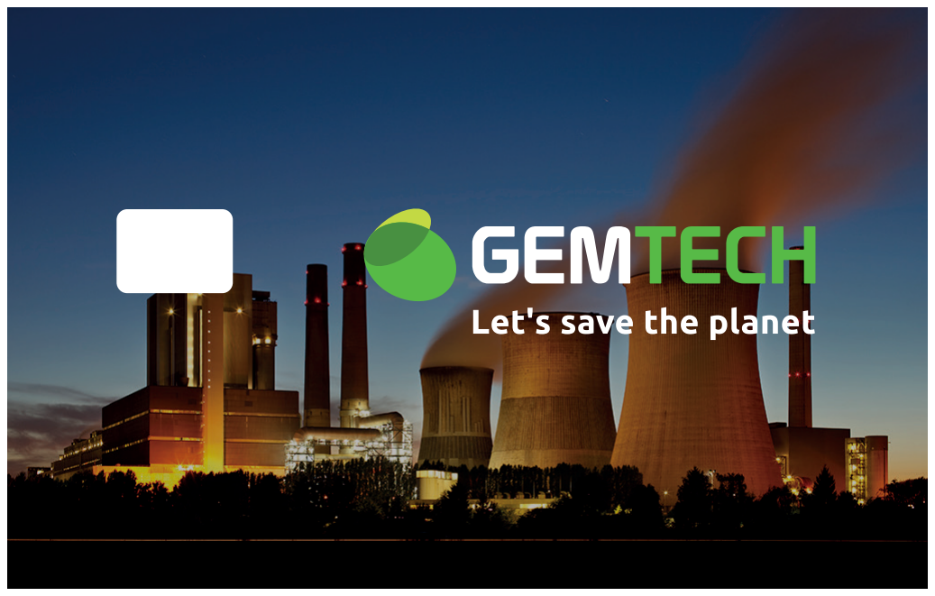
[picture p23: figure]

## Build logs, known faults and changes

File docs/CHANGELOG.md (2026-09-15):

# Keycard Shell Dev Firmware

## 1.4.0 (2026-09-15)

* [keycard] support Keycard v4
* [btc] support Bitcoin Taproot (requires Keycard v4)
* [btc] support storing and managing multisig descriptors
* [core] add address verification by QR scan
* [eip712] more tolerant parser
* [ui] guided Verify flow
* [misc] various robustness improvements
* [ci] add bootloader to GitHub releases

## 1.3.0 (2026-05-11)

* [eth] support ERC-8213

## 1.2.1 (2026-04-09)

* [qr] increase maximum number of QR segments from 64 to 128 to allow larger tx

## 1.2.0 (2026-04-01)

* [ui] add mnemonic verification function in Settings -> Keycard
* [build] switch to Arm GNU Toolchain (15.2.rel1)
* [build] switch to CMake-based build system
* [ci] automate build reproduction on GitHub runners

## 1.1.3 (2026-03-20)

* [ui] add quick index selection in address screen
* [ui] fix multisig address display for BTC
* [ui] show addresses in quadruplets of alternating colors in signing screen

## 1.1.2 (2026-03-13)

* [ui] show fingerprint in main menu title bar if no card name set
* [ui] up/down keys allow changing brightness in QR output screen (indicator to come)
* [keycard] fix regression when setting card name
* [stm32] update toolchain to GNU Tools for STM32 (14.3.rel1)

## 1.1.1 (2026-02-27)

* [ui] add backslash to symbol keyboard
* [ui] raise BIP39 passphrase max length to 255 chars
* [misc] small fixes

## 1.1.0 (2026-02-06)

* [ui] add symbol layout to virtual keyboard
* [ui] improve device verification instructions
* [btc] allow export of multiple accounts
* [eth] allow export of legacy and ledger live accounts
* [misc] do not allow firmware downgrade

## 1.0.5 (2026-01-23)

* [btc] more robust BIP32 path handling
* [stm32] stricter MPU configuration
* [misc] small fixes

## 1.0.4 (2026-01-12)

* [ur] handle PSBT wrapped in #6.310 tag
* [btc] support Cove wallet

## 1.0.3 (2025-12-02)

* [eth] better signing UI for Uniswap execute
* [btc] fix issue with PSBT output record order
* [btc] remove unused taproot key from export

## 1.0.2 (2025-11-10)

* [ui] correct some copy
* [eip712] show hash for all EIP712 messages

## 1.0.1 (2025-10-29)

* [ui] fix verify device URL
* [eip712] handle EIP712 messages omitting verifyingContract/chainId fields

## 1.0.0 (2025-10-14)

* [ui] fix QR overlapping title in some cases
* [misc] update database and site public keys

## 0.10.6 (2025-10-01)

* [ui] maximize screen space used for QR output

## 0.10.5 (2025-09-24)

* [ui] update menu structure
* [usb] remove outdated code in EIP712 message signing

## 0.10.4 (2025-09-17)

* [ui] add inline help to "Connect software wallet" flow
* [ui] add software update instructions in device settings
* [ui] move informations and regulatory label to a different submenu
* [prefs] add the ability to disable all inline help

## 0.10.3 (2025-08-29)

* [eth] fix hex string hashing in EIP712
* [eth] remove outdated code
* [ui] rename "Scan QR transaction" to "Scan QR"

## 0.10.2 (2025-08-22)

* [usb] replace GET_ADDRESS command with GET_PUBLIC
* [usb] changed USB PID
* [usb] various bugfixes

## 0.10.1 (2025-08-14)

* [btc] better change output detection
* [btc] handle transactions with marker/flag fields
* [ui] add regulatory label screen
* [usb] detect charging status from VUSB_OK signal

## 0.10.0 (2025-08-06)

* [slip39] add support for SLIP39 seed generation
* [slip39] add support for SLIP39 import
* [core] increase stack size
* [stm32] run the firmware in HDPL3

## 0.9.20 (2025-07-11)

* [db] remove QR-based database upgrade
* [db] recognize and extract SafeTx EIP712 messages
* [ui] custom presentation for SafeTx messages
* [ui] refactor pager code
* [stm32] more conservative SPI clock

## 0.9.19 (2025-06-30)

* [ui] add SeedQR import flow
* [ui] check that PIN and Duress PIN do not match during onboarding
* [ui] fix some copy

## 0.9.18 (2025-06-23)

* [ui] mnemonic entry keyboard now skips disabled letters
* [ui] can now enter mnemonic without using long presses
* [ui] keyboard color and labels aligned to figma design
* [qr] implement scanning of non-UR QR (no UI yet)
* [bip39] implement decoding of SeedQR

## 0.9.17 (2025-06-13)

* [qr] allow scanning QR with up to 64 segments
* [ui] add ability to enter BIP39 passphrase
* [ui] add multiple suggestions to BIP39 mnemonic entry
* [ui] in BIP39 mnemonic entry disable letters that do not bring to valid words

## 0.9.16 (2025-06-06)

* [btc] fix hashing of WSH
* [btc] fix validation of Witness Scripts
* [btc] add support for MultiSig wallets
* [ui] improved experience when a wrong mnemonic is entered
* [ui] fix navigation in update ERC20 dialogs

## 0.9.15 (2025-05-29)

* [usb] correctly handle command reception when busy
* [usb] do not reset mainmenu upon receiving a command
* [keypad] bump long press threshold from 100ms to 200ms
* [ui] change keyboard layout and navigation
* [ui] fix cursor positioning in text inputs
* [ui] add prompt to empty text inputs
* [ui] add cancel buttons to QR screens
* [ui] better error message for BTC tx that cannot be signed
* [ui] better error message when inserting a card in wrong orientation
* [ui] add step indication to mnemonic backup
* [ui] add feedback to factory reset flow
* [ui] align colors to Figma design
* [ui] use larger font size for titles

## 0.9.14 (2025-05-15)

* [eth] add ABI database
* [eth] add formatting of ABI calls in transactions
* [ui] disable auto turn-off during mnemonic backup
* [iso7816] reduce max timeout from 30s to 1s
* [tools] update DB generation tool to include ABI data

## 0.9.13 (2025-04-17)

* [ui] Align duress PIN flow design
* [usb] add SIGN PSBT command to support BTC over USB
* [usb] add GET RESPONSE command to handle replies larger than 255 bytes

## 0.9.12 (2025-04-11)

* Add duress PIN during card setup

## 0.9.11 (2025-04-04)

* Recognize "unlimited" amounts
* Round decimals when amount does not fit
* Fix minor issues

## 0.9.10 (2025-03-27)

* Implement new device info screen
* Implement new ERC-20 update flow
* Implement help screen
* Implement new device verification flow
* Implement pairing with non-default password
* Implement USB cable plug/unplug detection
* Add ticker to BTC
* Minor fixes

## 0.9.9 (2025-03-20)

* Replace battery icons
* Replace fonts
* Implement new info dialogs
* Add action bar to all flows
* Add BIP39 verification
* Add success/error messages to Keycard init/load
* Require long press to proceed with factory reset
* (Almost) match mnemonic generation flow to design
* Match PIN/PUK confirmation to design
* Add prompt before setting pairing password
* Minor fixes

## 0.9.8 (2025-03-13)

* Implement all keyboard layouts (lower, upper, digit, mnemonic)
* Implement new progress screen
* Implement new brightness settings screen
* Replace all icons
* Adjust some theme colors
* Align message signing screen to design
* Add icon sprite sheet for ui testing (accessed by pressing cancel on main menu)
* More compact SN display

## 0.9.7 (2025-03-05)

* Tweak QR output for better scanning performance
* Implement new QR scan progress indicator
* Start aligning keyboard to design

## 0.9.6 (2025-02-27)

* Overhaul icon handling code
* Optimized font drawing
* Partially matched action bar to design
* Match PIN/PUK screens to design
* Match ERC20 approve to design
* Match EIP712 message to design

## 0.9.5 (2025-02-20)

* Change font to Inter
* Match title and action bar size to design
* Match menu implementation to design
* Match address QR and wallet connection QR to design
* Match ETH, ERC20 and Message transactions to design

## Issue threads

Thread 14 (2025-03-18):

Timeout too long if card inserted wrong way

bitgamma, 2025-03-18:
Turning the device one with the card in the wrong direction seems to have a longer than expected timeout before an error appears

bitgamma, 2025-05-13:
the culprit was a 30 second timeout in the smartcard code, now lowered to 1 second

Closed 2025-05-13.

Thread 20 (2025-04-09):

Implement e-label

bitgamma, 2025-04-09:
details tbd

guylouis, 2025-07-13:
**Context**
Products sold in europe and in the usa need a list of mandatory mentions on the product like
CE mark
barred bin
model number
name of the manufacturer
power rating
serial or lot number

Products who have a display can use the display to show these informations instead of printing them on the product.

**For Shell**
On Shell we will have the CE mark and trashed bin. Both on the PCB behind the battery. But not the rest of theinformations.

So we have to create a menu, accessible when the product is unlocked.

**To be confirmed (I will be able to conifrm week of 28/7/2025)**
- place and name for the menu (probably will be something like settings/device/legal) I have to check what's the tolerated maximum number of clicks to get to the menu
- content of the screen. Hopefully it will be only text (since CE and barred bin are already on the product), and the only variable one will be the SN of the device

guylouis, 2025-07-30:
**Regarding where to put this elabel, the reference docs are**

https://fcc.report/FCC-ID/A4RGUIK2/5042986.pdf

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

So I suggest to put it here: settings/device/**regulatory label**

**Regarding the content of the label it should be**

"
Brand: Keycard
Model: Shell
Input: 5V DC, 1A
Manufacturer: Status Research and Development Am Zirkus 2, D-10117 Berlin, Germany
Made in China
Serial number:xxxxxxx
"

note: actually I think the input could take up to 1.5A but we can play it safe and leave 1A here

bitgamma, 2025-08-11:
done

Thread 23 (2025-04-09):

support SeedQR and text-mnemonic QR

bitgamma, 2025-04-09:
add support for https://github.com/SeedSigner/seedsigner/blob/dev/docs/seed_qr/README.md and/or plaintext mnemonic QR.

bitgamma, 2025-06-25:
proposed (and currently implemented) interaction. The default choice is "with passphrase" since it seems to be very common to set one when using SeedQR.

Please review @xAlisher @guylouis:

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

xAlisher, 2025-06-26:
@guylouis @bitgamma

Following up on the conversation here:
[https://discord.com/channels/1366754869561790474/1387350462117712045/1387690470423007333](https://discord.com/channels/1366754869561790474/1387350462117712045/1387690470423007333)

I’m aligned with @bitgamma on the minor copy updates.

User flows have been added to Figma:
[https://www.figma.com/design/I4NT4JGHDEVSQ2yo5Z4mju/Shell-OS?node-id=5295-93739\&t=PKWxt5CPmQwZbo0K-1](https://www.figma.com/design/I4NT4JGHDEVSQ2yo5Z4mju/Shell-OS?node-id=5295-93739&t=PKWxt5CPmQwZbo0K-1)

Great job on this feature! 👏

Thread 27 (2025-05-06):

Improve T=1 support

bitgamma, 2025-05-06:
Smartcard from manufacturers other than NXP currently do not work properly with Shell. ATR and PPS seem to work, but T=1 blocks cannot be correctly exchanged, will have to check what's wrong.

Closed 2025-05-19.

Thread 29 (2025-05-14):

Update auto-complete interaction and feedback design

xAlisher, 2025-05-14:
### Title
Update auto-complete interaction and feedback design

---

### Description
The current auto-complete input flow is not intuitive for many testers.

**Reported by:** 9 testers

#### Key issues:
- It’s unclear what happens when users hold to save a word — most testers only understood it after experimenting.
- Selecting a suggested word feels confusing; several testers tried using arrow keys to confirm.
- Typing is slow and lacks visible feedback for how suggestions are selected or confirmed.

---

### Suggested improvements:
- Improve on-screen labels and titles for clarity
- Display a visible list of suggested words
- Add a walkthrough video or animation to onboarding materials
- Show a validation error (e.g. red text) if a user tries to confirm an invalid word

### Resources
https://www.figma.com/design/I4NT4JGHDEVSQ2yo5Z4mju/Shell-OS?node-id=0-1

xAlisher, 2025-05-24:
Plan Minimum
- Update wording to make expected behavior explicit.
- Improve readability of titles and the highlighted word segment.
- Clarify action label to reinforce what’s being confirmed.
- Increase space between cursor and word parts for readability

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

Plan Maximum

**Introduce an alternate suggestion input:**
- Show a full list of valid words to choose from.
- Reduce number active keys with every character selected to minimize navigation steps.

Overview
This update targets common tester friction in the current flow. Plan minimum is low-effort and already resolves major confusion. Plan maximum adds predictability and significantly faster word input.

Proposal: https://www.notion.so/Shell-input-improvements-14d8f96fb65c80f0bf76ff1ff1190570  (note: design and keyboard layout outdated)
Figma https://www.figma.com/design/I4NT4JGHDEVSQ2yo5Z4mju/Shell-OS?node-id=5055-140967&t=5ZdeBNICwB1bczF1-1

🙏👁️ @guylouis @bitgamma

xAlisher, 2025-05-24:
Error handling:
- Remove "Hold to" button

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

bitgamma, 2025-05-29:
extracted in #111  the more complete autocomplete solution

bitgamma, 2025-05-29:
implemented the minimum solution, however the "Hold to confirm label" actually doesn't fit in screen so I left the current label for the action label

bitgamma, 2025-06-04:
In code the space between navigation icon and screen border is 16px. The space between icon and label is 10px. I can decrease them if needed

Closed 2025-06-23.

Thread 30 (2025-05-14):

Standardize confirmation interaction using button 5 and OK button on virtual keyboard

xAlisher, 2025-05-14:
### Description
Several testers expected the center key (`5`) to act as a confirmation button, aligning with familiar patterns from TV remotes and keypad-based devices.

**Reported by:** 7 testers

#### Key issue:
- Users instinctively pressed button 5 to confirm actions during input flows.
- Current behavior is inconsistent and breaks expected interaction patterns.

### Suggested improvements:
- Map confirmation consistently to button 5 across keyboard interactions.
- Ensure the “OK” button performs the same role on relevant screens.

Closed 2025-09-08.

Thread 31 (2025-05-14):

Fix unpredictable focus behavior in virtual keyboard

xAlisher, 2025-05-14:
### Description
The current focus navigation in the virtual keyboard is unintuitive and frustrating for users.

**Reported by:** 7 testers

#### Key issues:
- Focus does not move as expected when navigating the keyboard.
- The current layout appears designed for symmetry rather than interaction flow.
- Testers often lost track of which key will be active or selected.

---

### Suggested improvements:
- Prioritize predictable navigation over visual symmetry.
- Align key positions to support consistent up/down/left/right movement.
- Consider visual or motion cues to reinforce active focus.

---

### Resources
https://www.figma.com/design/I4NT4JGHDEVSQ2yo5Z4mju/Shell-OS?node-id=0-1

guylouis, 2025-05-23:
I personally think option 2 makes more sense, but it's not either a blocker for release. It comes down to @bitgamma bandwidth, if it's like less than 2 days of work I'd do it before release. Otherwise I think we can either postpone or expect someone else in the community takes it

Closed 2025-06-03.

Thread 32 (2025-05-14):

Consider supporting T9-style or multi-tap input method

xAlisher, 2025-05-14:
### Description
Several testers expected a classic SMS-style input method, where each number key maps to multiple letters (e.g., button 1 circles through  A,B,C). The current input model does not meet this expectation and slows down entry for many users.

**Reported by:** 6 testers

#### Key issues:
- Testers instinctively expected to use multi-tap or classic T9 logic for typing.
- The current flow doesn’t align with familiar mobile or remote control inputs.
- This mismatch leads to user frustration and slower task completion.

---

### Suggested improvements:
- Implement a T9-style layout or offer it as an optional input mode.
- Visually indicate available letters per button.
- Consider pairing with predictive suggestions for efficiency.
- Consider updating physical buttons with related letters

---

### Resources
https://www.figma.com/design/I4NT4JGHDEVSQ2yo5Z4mju/Shell-OS?node-id=0-1

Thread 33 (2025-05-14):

Fix Shell shutdown caused by loose Keycard connection

xAlisher, 2025-05-14:
### Description
Shell powers off when the Keycard moves slightly during use. This disrupted testing sessions and led testers to question the device’s reliability.

**Reported by:** 5 testers

#### Key issues:
- Card doesn’t stay securely in place.
- Minor shifts in the card's position result in an unexpected power-off.

---

### Suggested improvements:
- Improve card slot tension to ensure stable connection.
- Add visual feedback to confirm successful card insertion.
- Explore mechanical design changes to prevent unintentional disconnection.

guylouis, 2025-05-23:
taken into account in the various mechanical adjustments decided based on those alpha/er prototypes

the changes are documented here

[Mechanical adjustments to Shell ER_alpha stage 05 2025.pdf](https://github.com/user-attachments/files/20414238/Mechanical.adjustments.to.Shell.ER_alpha.stage.05.2025.pdf)

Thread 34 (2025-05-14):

Ensure consistent navigation and visible Back button across all screens

xAlisher, 2025-05-14:
### Description
Testers experienced confusion due to inconsistent navigation patterns and missing “Back” buttons on several screens.

**Reported by:** 5 testers

#### Key issues:
- “Back” button not present or visible on all screens.
- Inconsistent navigation makes it hard to return to the previous step.
- Users were unsure how to exit or undo actions in certain flows.

---

### Suggested improvements:
- Standardize the presence and placement of the Back button across all screens.
- Use consistent icons or labels for navigation actions.
- Add visual guidance to reinforce expected flows and transitions.

---

### Resources
https://www.figma.com/design/I4NT4JGHDEVSQ2yo5Z4mju/Shell-OS?node-id=0-1

bitgamma, 2025-05-28:
lgtm

Closed 2025-05-28.

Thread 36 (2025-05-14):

Improve clarity of card orientation and insertion depth

xAlisher, 2025-05-14:
### Description
Users were uncertain about how far to insert the Keycard and which direction it should face. The current design provides limited tactile or visual guidance, leading to hesitation and errors during setup.

**Reported by:** 4 testers

#### Key issues:
- No clear indicator for proper card orientation.
- Lack of tactile or visual confirmation when the card is fully inserted.
- Some users feared inserting the card incorrectly or not far enough.

---

### Suggested improvements:
- Add visual cues (icons, arrows, notches) to indicate correct card direction and depth.
- Consider modifying slot design so a portion of the card remains visible after insertion.
- Include clearer onboarding steps or animations to guide first-time users.

xAlisher, 2025-05-19:
3 points of contact for chip orientation and insertion depth
- paper
- shape
- quick start guide

 For chip orientation
- it's not a Keycard or it's not inserted the right way

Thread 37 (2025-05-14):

Improve screen brightness for better visibility in varied lighting

xAlisher, 2025-05-14:
### Description
Testers reported that the screen was difficult to read in bright or direct lighting conditions. Low brightness affected usability, especially outdoors or in well-lit rooms.

**Reported by:** 3 testers

#### Key issues:
- Text and UI elements were hard to see in some environments.
- The screen didn’t adapt well to different lighting conditions.
- Diminished readability affected the overall impression of hardware quality.

---

### Suggested improvements:
- Enhance screen backlight strength or contrast.
- Explore using a brighter display panel.

guylouis, 2025-05-23:
after investigation, we confirmed that the transistor was not conducting properly because the control voltage (gate/base) was insufficient at 1.8 V

this happened because because between P2 (which was OK in terms of brightness) we changed the transistor reference, going back to the initial transistor on modified ER the backlight is OK

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

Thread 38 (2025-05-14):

Align physical button layout with on-screen label expectations

xAlisher, 2025-05-14:
### Description
Some testers expected the physical buttons to align directly beneath the on-screen labels. The current layout — where buttons are placed in the final row — caused mismatch and hesitation during interaction.

**Reported by:** 4 testers

#### Key issues:
- Mismatch between physical button placement and on-screen cues.
- Users looked for labels directly above buttons but found a disconnect.
- This slowed down interactions and created uncertainty during selection.

---

### Suggested improvements:
- Consider adjusting button placement to match the visual layout of the UI.
- Alternatively, improve visual guidance by clearly associating labels with their corresponding buttons.
- Highlight states and iconography to reinforce correct button-label mapping.

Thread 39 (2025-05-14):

Make battery easier to remove through design adjustment

xAlisher, 2025-05-14:
### Description
Several testers found it physically difficult to remove the battery from the device. The current design does not provide enough leverage or grip to extract it comfortably.

**Reported by:** 3 testers

#### Key issues:
- Battery is tightly fitted and lacks a convenient way to remove it.
- No designated area to grip or push the battery out.
- Frustration during basic maintenance impacts perceived usability.

---

### Suggested improvements:
- Add a notch, groove, or indentation to assist with finger grip.
- Consider introducing a pull tab or tool-free removal mechanism.
- Ensure that battery maintenance feels simple and intentional.

xAlisher, 2025-05-19:
It's possible to remove the battery with the card.
Add this to the doc.

guylouis, 2025-05-23:
conclusion is indeed that we won't make changes to the plastic but document precisely how to remove the battery

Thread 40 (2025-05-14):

Improve case material and surface finish for higher perceived quality

xAlisher, 2025-05-14:
### Description
Testers noted that the current plastic finish of the Shell case felt cheap. Several people expressed a desire for a more premium or tactile material.

**Reported by:** 3 testers

#### Key issues:
- Case surface feels generic or less durable.
- Glossy or smooth finish may reduce grip and aesthetic appeal.
- Material choice influences first impressions of quality.

---

### Suggested improvements:
- Explore matte finishes.
- Consider material swaps that improve grip and reduce glare.
- Test finish options with users to balance durability and feel.

guylouis, 2025-05-27:
On alpha products (ER) we use ABS plastic but the grain (finish) is not applied on the steel mold. That's why the surface has some marks. The finish is applied at the very last moment when all changes on the steel mold have been done.

Once it is applied, the plastic when injected will be perfect in terms of finish and quality

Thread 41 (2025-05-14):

Improve font legibility by increasing size

xAlisher, 2025-05-14:
### Description
A few testers mentioned that the current font size is too small, making it harder to read content comfortably during use.

**Reported by:** 3 testers

#### Key issues:
- Font appears too small on certain screens.
- Difficult to read for users with less-than-perfect vision.
- Affects usability during onboarding and input flows.

---

### Suggested improvements:
- Increase default font size across the UI where possible.
- Offer an adjustable font size setting in preferences.

bitgamma, 2025-07-14:
font size increased in titles

Closed 2025-07-14.

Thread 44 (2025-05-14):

Consider switching to alphabetical keyboard layout for clarity

xAlisher, 2025-05-14:
### Description
Some testers found the QWERTY layout less intuitive, especially on a small device with limited keys. An alphabetical layout might offer better clarity for non-technical or first-time users.

**Reported by:** 2 testers

#### Key issues:
- QWERTY layout is less familiar to some users in this context.
- Alphabetical layout may reduce friction and improve discoverability.
- Device constraints make traditional keyboard patterns feel unintuitive.

---

### Suggested improvements:
- Offer an alphabetical keyboard layout as default or as an option.
- Test with both experienced and non-experienced users to validate layout clarity.
- Explore hybrid layouts optimized for hardware button constraints.

---

### Resources
https://www.figma.com/design/I4NT4JGHDEVSQ2yo5Z4mju/Shell-OS?node-id=0-1

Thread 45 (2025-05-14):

Clarify whether user is creating a new PIN or entering an existing one

xAlisher, 2025-05-14:
### Description
Testers were confused about whether they were supposed to **create a new PIN** or **enter an existing one** when interacting with the first screen of the device. The word “Set” was used, but was not easily visible or meaningful in context.

**Reported by:** 2 testers

#### Key issues:
- Ambiguity between PIN creation and PIN entry on first use.
- The label “Set” is unclear and lacks visual emphasis.
- Confusion at this critical step can lead to hesitation or input errors.

---

### Suggested improvements:
- Use clear, explicit text: “Create new PIN” vs. “Enter existing PIN.”
- Improve visibility and contrast of instructional text on the screen.
- Consider using a visual indicator or icon to differentiate the flows.

---

### Resources
https://www.figma.com/design/I4NT4JGHDEVSQ2yo5Z4mju/Shell-OS?node-id=0-1

bitgamma, 2025-05-28:
implemented

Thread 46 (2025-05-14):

Improve button feel — reduce press resistance for better usability

xAlisher, 2025-05-14:
### Description
Several testers reported that the hardware buttons on Shell felt too stiff or hard to press. The high resistance reduced comfort and created hesitation during interactions.

**Reported by:** 2 testers

#### Key issues:
- Buttons require too much force to register input.

---

### Suggested improvements:
- Soften the button mechanism to reduce required pressure.
- Explore alternative materials or switch types for improved feel.
- Aim for a balance between clicky feedback and comfortable usability.

bitgamma, 2025-05-14:
8 testers explicitly mentioned liking the current level of stiffness

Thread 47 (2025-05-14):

Improve packaging usability — box is difficult to open and remove Shell from

xAlisher, 2025-05-14:
### Description
Testers reported difficulty both opening the Shell packaging and removing the device from the box. These friction points negatively impacted the unboxing experience and first impressions of the product.

---

#### Key issues:
- Outer box lacks intuitive opening mechanism; users had to guess or apply force.
- The Shell device is tightly fitted with no clear way to lift it out.
- Risk of user frustration or device damage during unboxing.

---

### Suggested improvements:
- Redesign the box for easier opening (e.g. tear strip, pull tab, or clear indicators).
- Add a finger recess, ribbon, or lift tab to help remove the Shell device easily.
- Prototype revised packaging for smoother, one-handed unboxing experience.

guylouis, 2025-05-14:
working on providing an improved version
- same construction philosophy
- with more room inside, will facilitate grabbing stuff
- with higher quality feeling of the material

1st step is to decide if we can keep the black & orange type of design and improve the perceived quality. It's unsure while using corrugated paper that we can manage too, because of the edges

If we can't we'll have cardboard color material on which we will print our design. It will help have a cleaner looking edge.

guylouis, 2025-05-23:
strategy is to create a place to put the finger to lift up Shell and the papers

[KEYCARD_coffret_v1_23052025.pdf](https://github.com/user-attachments/files/20414222/KEYCARD_coffret_v1_23052025.pdf)

guylouis, 2025-07-14:
packaging had been improved, see the die cut below
samples to be received end of July - early August max

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

Closed 2025-06-30.

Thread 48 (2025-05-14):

Clarify how to add Shell as a hardware wallet in MetaMask

xAlisher, 2025-05-14:
### Description
Testers were confused when attempting to connect Shell as a hardware wallet in MetaMask. MetaMask requires users to first create or import a hot wallet before they can add a hardware wallet — a step that’s not obvious to first-time users.

---

#### Key issues:
- Users didn't understand why MetaMask wouldn't let them add Shell directly.
- Lack of guidance led to friction and unnecessary troubleshooting.
- MetaMask UX assumption (hot wallet first) was not communicated clearly.

---

### Suggested improvements:
- Mention this requirement during Shell onboarding when prompting users to connect to MetaMask.
- Add a tip or note in Shell’s help documentation.
- Reach out to the MetaMask team with a proposal to improve or clarify this flow on their end.

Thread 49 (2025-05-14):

Improve readability of word prompt during backup flow

xAlisher, 2025-05-14:
### Description
During the backup process, users found it unclear which word they were expected to input. The current title bar, which displays the word number, is not easily readable due to low contrast.

---

#### Key issues:
- Word number (e.g. “Word 5”) is hard to see against the background.
- The label lacks contrast and visibility, leading to hesitation and confusion.
- Users are unsure which word they’re confirming or typing.

---

### Suggested improvements:
- Increase the contrast of the title bar
- Consider moving the word number to a more visible location, such as below the title
- Explore adding visual cues (like progress dots or highlighting) to reinforce the step number.

---

### Resources
https://www.figma.com/design/I4NT4JGHDEVSQ2yo5Z4mju/Shell-OS?node-id=0-1

xAlisher, 2025-05-24:
Suggest improving visibility without disrupting layout by:

- Increasing the title font size (may create slight tension in other areas, but it’s manageable).
- Boosting contrast between title text and background by brightening the style.

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

Bonus idea:
- To improve predictability, we could display the number of remaining steps to complete the flow.

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

🙏👁️ @bitgamma @guylouis

bitgamma, 2025-05-28:
@xAlisher lgtm, but I see in the figma design that some title needs to be changed because they don't fit with the larger font size.

Also, I see highlighted words/menus are now using white font instead of black. Is this change part of this issue?

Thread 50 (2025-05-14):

Clarify behavior of Cancel button on word input screen

xAlisher, 2025-05-14:
### Description
Testers were unsure what would happen if they pressed the “Cancel” button during the word input screen in the backup flow. The lack of explanation caused hesitation and fear of losing progress.

---

#### Key issues:
- “Cancel” button lacks contextual clarity — does it exit the flow, go back, or discard progress?
- Uncertainty at this step creates friction and user anxiety.
- No confirmation or explanation is provided when the button is pressed.

---

### Suggested improvements:
- Add a short label or tooltip to clarify what “Cancel” will do.
- Consider prompting a confirmation modal if pressing “Cancel” would result in data loss or reset.
- Use more descriptive text (e.g., “Go back” or “Exit backup”) if appropriate.

---

### Resources
https://www.figma.com/design/I4NT4JGHDEVSQ2yo5Z4mju/Shell-OS?node-id=0-1

phift, 2025-05-29:
Maybe that's what you mean by backup flow. But in the `Import recovery phrase` screen, 'c hold to exit' is similarly confusing, because holding c doesn't 'exit' the flow, but it returns to the previous screen

bitgamma, 2025-07-14:
labels have been adjusted accordingly

Closed 2025-07-14.

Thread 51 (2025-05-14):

Add support for displaying ABI data after scanning transaction QR

xAlisher, 2025-05-14:
### Description
Testers expressed interest in seeing decoded ABI (Application Binary Interface) data after scanning a transaction QR code. This would help verify the intent of a transaction before signing, especially for smart contract interactions.

#### Key issues:
- Lack of transparency into what the transaction is doing.
- Users want to understand the method and parameters before signing.
- No decoded ABI data currently shown in the signing flow.

---

### Suggested improvements:
- Parse and display ABI call data after scanning a transaction QR.
- Show method name, parameters, and values in a readable format.
- Include this as an optional step for advanced users.

---

### Resources
https://www.figma.com/design/I4NT4JGHDEVSQ2yo5Z4mju/Shell-OS?node-id=0-1

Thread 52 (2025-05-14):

Fix link to duress PIN documentation

xAlisher, 2025-05-14:
### Description
The link to the duress PIN documentation at [https://keycard.tech/duress_pin](https://keycard.tech/duress_pin) is currently broken or not live. Testers who try to learn more about this security feature encounter a dead page

**Reported by:** Multiple testers

#### Key issues:
- The link to duress PIN documentation leads to a non-functional page.
- Users are left without guidance on how duress mode works.
- Breaks the user flow during onboarding or help searches.

---

### Suggested improvements:
- Publish or finish the content at https://keycard.tech/duress_pin.

Closed 2025-08-11.

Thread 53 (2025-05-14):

Fix incorrect navigation when exiting “Generate New Key” flow

xAlisher, 2025-05-14:
### Description
When users exit the “Generate New Key” flow, they are redirected to the wrong screen. This creates confusion and breaks the expected flow continuity.

---

#### Key issues:
- Exiting the key generation process doesn’t return the user to the intended screen.
- Unexpected navigation causes users to feel lost or uncertain about their progress.
- Breaks consistency with the rest of the onboarding flow.

---

### Suggested improvements:
- Ensure exit from the “Generate New Key” flow returns the user to the correct previous screen.
- Review and test all exit paths for accuracy and UX coherence.

---

### Resources
https://www.figma.com/design/I4NT4JGHDEVSQ2yo5Z4mju/Shell-OS?node-id=0-1

xAlisher, 2025-05-19:
Let's test it

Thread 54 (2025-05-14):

Allow users to purchase Shell with cryptocurrency

xAlisher, 2025-05-14:
### Description
Testers expressed interest in buying Shell using crypto. Offering a direct crypto payment option would align with the values of the target audience and streamline the purchasing experience.

---

#### Key issues:
- No visible option to purchase Shell using crypto.
- Credit card-only checkout may exclude privacy-conscious or Web3-native users.
- Missed opportunity to align purchasing flow with the product’s ethos.

---

### Suggested improvements:
- Enable crypto payments via dedicated platform
- Highlight crypto payment option on the main landing and checkout pages.
- Allow pre-orders and community discounts through crypto-first channels.

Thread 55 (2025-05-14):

Clarify that “Get signature” in MetaMask triggers QR scanning flow

xAlisher, 2025-05-14:
### Description
Tester was confused by the “Get signature” button in MetaMask, as it’s not clear that clicking it will initiate the QR code scanning process with Shell. The lack of context causes hesitation and interrupts the expected signing flow.

---

#### Key issues:
- The label “Get signature” doesn’t indicate that it will trigger QR scanning.
- Users are unsure what to expect after clicking the button.
- Lack of explanation increases friction and makes the process feel opaque.

---

### Suggested improvements:
- Reach out to the MetaMask team to suggest a more descriptive label (e.g. “Scan to Sign” or “Continue with Hardware Wallet”).
- Include clear instructions in Shell documentation and onboarding to explain the MetaMask signing flow.

xAlisher, 2025-05-24:
To improve clarity and better align with MetaMask’s “Get Signature” prompt, I suggest updating the title on the TX QR screen.

Before:
“Scan signature QR with Wallet”

After:
“Show signature QR to your wallet”

This reinforces the correct direction of action and helps users interpret what’s happening more intuitively.

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

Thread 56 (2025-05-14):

Chevron-right inside the circle icon misinterpreted as  chevron on keypad

xAlisher, 2025-05-14:
### Description
Testers confused the chevron-right icon inside an orange circle with the physical chevron key on the keypad. This led to hesitation and incorrect inputs. The blending of icon roles reduced clarity in the interface.

#### Key issues:
- Chevron inside the orange circle is visually similar to the keypad's left-arrow button.
- Users mistakenly interpret it as a hardware control rather than an on-screen indicator.
- Inconsistent icon behavior breaks visual expectations.

---

### Suggested improvements:
- Consider using a plain orange circle for confirmation actions (OK), without overlaying the chevron.
- Keep all chevron icons on-screen consistently white.
- Ensure visual roles between hardware keys and on-screen symbols are clearly separated.

---

### Resources
https://www.figma.com/design/I4NT4JGHDEVSQ2yo5Z4mju/Shell-OS?node-id=0-1

xAlisher, 2025-05-23:
OK button states simplified and unified. Now we'll have only two states. Default and long press.

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

I need one more pair of eyes for feedback and review.
@guylouis @bitgamma

guylouis, 2025-05-23:
looks good!
maybe write it somewhere in the doc in a 'navigation' part of the faq

bitgamma, 2025-05-23:
looks good to me too

bitgamma, 2025-05-28:
done

Closed 2025-05-28.

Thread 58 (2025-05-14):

Allow adding a password to mnemonic

bitgamma, 2025-05-14:
often called the 13th or 25th word, we could allow the user to add a password the mnemonic phrase. This is especially useful if we implement #23 since it is relatively common to use a password in this case.

This step would happen during onboarding of a new card when:

- importing an existing mnemonic (either keyboard or QR)
- generating a new mnemonic, after backup and before the keys are actually loaded

bitgamma, 2025-06-09:
@xAlisher

my understanding is that in both generate mnemonic and import mnemonic the menu where you select the mnemonic length will become something like:

12 words
12 words + pass
24 words
24 words + pass

and that after the mnemonic has been entered or backed up the user will enter the pass.

Is this also how you see the flow? If that's the case I will start implementing this.

bitgamma, 2025-06-10:
Implemented the feature so that it at least works. For UI I simply modified the mnemonic length selection menu and added, in case an option with passphrase has ben selected, a final screen to input the passphrase. Feel free to revise this in any way

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

xAlisher, 2025-06-23:
@bitgamma design updated

Import recovery phrase https://www.figma.com/design/I4NT4JGHDEVSQ2yo5Z4mju/Shell-OS?node-id=5235-62008&t=4bPH3kMTDniDkBOV-1
Generate keys
https://www.figma.com/design/I4NT4JGHDEVSQ2yo5Z4mju/Shell-OS?node-id=214-58571&t=4bPH3kMTDniDkBOV-1

Closed 2025-06-23.

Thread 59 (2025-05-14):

Improve autocomplete prioritization to favor longer words

xAlisher, 2025-05-14:
### Description
Testers noted that Shell’s autocomplete often prioritizes shorter or less relevant words, even when longer, more complete matches are available. This results in more manual input and interrupts the typing flow.

#### Key issues:
- Autocomplete tends to suggest short or partial words first.
- Users expect longer, more specific matches to rank higher.
- Current ordering may lead to unnecessary corrections or delays.

---

### Suggested improvements:
- Adjust autocomplete algorithm to favor longer, more complete word matches.
- Test updated prioritization on common wallet recovery words

---

### Resources
https://www.figma.com/design/I4NT4JGHDEVSQ2yo5Z4mju/Shell-OS?node-id=0-1

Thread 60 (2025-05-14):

Clarify how to connect Shell to Rabby — no QR-based option visible

xAlisher, 2025-05-14:
### Description
Testers found it difficult to connect Shell to Rabby, as the wallet connection UI does not clearly show a QR-based option. Shell is not listed as a branded wallet, and there is no generic “Connect with QR” entry point, leading to confusion.

---

#### Key issues:
- Rabby does not show a generic QR-based connection option.
- Shell is not yet listed as a supported or branded wallet.
- Users struggle to find a compatible path for connection.

---

### Suggested improvements:
- Reach out to the Rabby team to request inclusion of Shell or a “Connect via QR” option.
- In the meantime, add a clear note in Shell documentation to guide users through the available workaround.
- Consider providing step-by-step instructions or visuals in onboarding for connecting via Rabby.

---

### Resources
https://www.figma.com/design/I4NT4JGHDEVSQ2yo5Z4mju/Shell-OS?node-id=0-1

Closed 2025-07-28.

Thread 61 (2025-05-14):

Add confirmation feedback after factory reset

xAlisher, 2025-05-14:
### Description
After performing a factory reset, the device does not provide any confirmation or feedback to indicate that the reset was successful. This leaves users unsure whether the action completed correctly.

---

#### Key issues:
- No success message, visual cue after reset.
- Users are left uncertain about whether the reset worked.
- Can lead to repeated attempts to enter previous PIN or loss of confidence in the process.

---

### Suggested improvements:
- Display a clear confirmation screen (e.g. “Keycard has been reset”) after the reset completes.
- Optionally add a success icon for reassurance.
- Then redirect users back to the welcome/setup screen after successful reset.

---

### Resources
https://www.figma.com/design/I4NT4JGHDEVSQ2yo5Z4mju/Shell-OS?node-id=0-1

xAlisher, 2025-05-21:
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

@guylouis @bitgamma  WDYT?

Closed 2025-05-28.

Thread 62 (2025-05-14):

Clarify wallet type selection (Ethereum, Bitcoin, Multichain)

xAlisher, 2025-05-14:
### Description
Testers were confused when asked to choose between Ethereum, Bitcoin, or Multichain wallets during setup. The options lacked context or explanation, making it unclear which one to pick.

---

#### Key issues:
- Users didn’t understand the differences between Ethereum, Bitcoin, and Multichain wallets.
- Lack of in-device guidance made this decision feel risky or arbitrary.
- No clear link to supported wallet features or compatibility.

---

### Suggested improvements:
- Add a brief description under each wallet type (e.g. “Ethereum: EVM-compatible chains”).
- Consider adding recognizable brand names (e.g. MetaMask, Rabby, OKX) to improve comprehension.
- Update documentation to explain each wallet type, use case, and compatibility in more detail.

---

### Resources
https://www.figma.com/design/I4NT4JGHDEVSQ2yo5Z4mju/Shell-OS?node-id=0-1

xAlisher, 2025-06-03:
- remove Sparrow
- remove multichain

xAlisher, 2025-06-23:
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

https://www.figma.com/design/I4NT4JGHDEVSQ2yo5Z4mju/Shell-OS?node-id=0-1&t=4bPH3kMTDniDkBOV-1

I'm suggesting to name most popular wallets right in the menu for better user experience.

@guylouis @bitgamma WDYT?

@cheny0 could you give me the list of wallets compatible with Shell sorted by popularity to add to this menu, please?

xAlisher, 2025-06-23:
https://www.figma.com/design/I4NT4JGHDEVSQ2yo5Z4mju/Shell-OS?node-id=53-19251&t=4bPH3kMTDniDkBOV-1

cheny0, 2025-06-25:
@xAlisher Here's a list in the current docs: https://keycard.tech/docs/supported-wallets#wallets-for-keycard. The "Multichain" QR code works for Bitget and backpack

guylouis, 2025-06-30:
I wouldn't trust this list too much, it was more a marketing list than a result of good testing

here's where we will track the result of the real testing
https://github.com/keycard-tech/keycard-shell/issues/81

guylouis, 2025-08-13:
So the entries will be:
Ethereum
Bitcoin
Bitcoin Multisig
Bitget

Bitcoin Testnet is present for now but will be removed before launch

guylouis, 2025-09-08:
I am unclear if it's ok like this (current implementation is ethereum, bitcoin, bitcoin multisig, bitget) or if we want to add more details in the list

Closed 2025-09-08.

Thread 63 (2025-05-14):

define keycard design for shell

guylouis, 2025-05-14:
When someone buys Shell, we will put 2 cards together within the box.

We need to define the packaging of these cards
- keycard logo be bottom front so that we see keycard logo when entering the card in shell
- black tone overall
- a shape should be present on the back that matches with Shell hole. This shape has several interest: care for the design (keycard and shell are perfect friends: they match :)), delimits a zone were the user could put a small sticker or write down with a marker a way to distinguish his cards, and finally helps remembering how (top/bottom) to insert the card.
- we want to keep our logistics wimple so this card will also be the one shipped to customers buying keycards without Shell

guylouis, 2025-10-03:
settled for this design [print_Keycard_K_icon_BLACK_V2.pdf](https://github.com/user-attachments/files/22676522/print_Keycard_K_icon_BLACK_V2.pdf)

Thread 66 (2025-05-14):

define exact content of the quick start 'card' printed in the box

guylouis, 2025-05-14:
content on alpha was:

front side

"Scan to get started
QR code
keycard.tech/start"

back side

"1 remove the back cover from keycard shell

2 install the battery in its slot

3 insert a keycard to turn on Keycard Shell
"

guylouis, 2025-05-30:
seems good to me, I guess the sensitive one is point 3. If one doesn't check the quick start guide then he must understand that he needs to push the card completely. So I guess point 3 should either
- have an illustration where we see the insertion top/bottom and a finger pushing all the way
- a text -> push card *all the way* or 'if your product doesn't turn on make sure you push the card all the way'

guylouis, 2025-07-13:
@Francesca-G

I think we're ready to design this, to print it also as part of the packaging
Could you do it when you have chance?

guylouis, 2025-07-28:
card updated by @Francesca-G

[TOKEA_carte_65x100mm.pdf](https://github.com/user-attachments/files/21468342/TOKEA_carte_65x100mm.pdf)

Closed 2025-07-28.

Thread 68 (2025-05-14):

message when inserting a card which is incompatible with keycard

guylouis, 2025-05-14:
can we review what happens if someone inserts a card without keycard applet, or with keycard applet but too old (applet < 3.1.0)

bitgamma, 2025-05-14:
sorry closed by mistake, but probably can be closed can't it?

guylouis, 2025-05-19:
some testers said the message was not super clear, may you confirm what it is in the code?

bitgamma, 2025-05-19:
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

guylouis, 2025-05-19:
we can close, I opened two issues for future improvements

not genuine: https://github.com/keycard-tech/keycard-shell/issues/72
old applet: https://github.com/keycard-tech/keycard-shell/issues/73

Closed 2025-05-19.

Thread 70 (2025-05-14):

Improve error message for unsupported Bitcoin Taproot transactions

xAlisher, 2025-05-14:
### Description
When attempting to sign a Taproot-based Bitcoin transaction using Shell and Unisat (e.g. for buying an ordinal on Magic Eden), the device displayed a misleading “wrong key pair” error. This happened even though the same Keycard worked for connecting to Unisat. The actual issue is related to Taproot being unsupported.

#### Context:
- Taproot is currently not supported.
- The transaction included Taproot components, leading to a signing failure.
- Error message displayed: “wrong key pair,” which does not explain the real cause.

---

### Suggested improvements:
- Update the error message to clarify that Taproot-based transactions are not supported.
- Suggested phrasing: _“This transaction uses a Taproot address, which is not supported yet.”_
- Optionally include a link to documentation or help page for supported address types.

---

### Notes:
Tested with:
- Shell + Unisat
- Magic Eden / Ordinal TX
- Switching to Segwit resolved the issue

---

### Resources
https://www.figma.com/design/I4NT4JGHDEVSQ2yo5Z4mju/Shell-OS?node-id=0-1

xAlisher, 2025-05-21:
> just update wording to a more generic error message to say that there is nothing we can sign here (it's not a question of keys)

But also could be a wrong key pair.
@guylouis @bitgamma WDYT?

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

guylouis, 2025-05-22:
seems good to me
how can we track all the things that need to be in the documentation ?
this is one for instance
any idea @cheny0 ?

cheny0, 2025-05-23:
@guylouis, what we are doing now seems to be good enough, which is to add the "documentation" label to relevant issues. When you want to check all documentation-related issues, you go to the project board and click on the "documentation" label. Then you'll see only issues with this label, like this https://github.com/orgs/keycard-tech/projects/1/views/1?filterQuery=label%3Adocumentation. WDYT?

guylouis, 2025-05-23:
great to hear!

bitgamma, 2025-05-28:
the subtext message is too long, otherwise I have to rework the entire info dialog to measure all text and calculate the vertical offsets before drawing, which I don't think it is worth. Let's omit the "Visit ..." part

Closed 2025-06-03.

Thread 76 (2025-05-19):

Update Shell packaging design

Francesca-G, 2025-05-19:
### Description

Update Shell packaging design

- **COLORS →** Natural cardboard color + orange 🟠
- **FLAPS →** need to be bigger and black (useful to protect the device)
- **GLOSS PRINT →** thicker lines, consider embossed gloss print to make it more visible
- **INSTRUCTION CARD →** Change QR code to lead to a START page for Shell (/start/shell)
- **CARD HOLDER →** change to a single piece of paper with 4 slits and a card on each side (no folds) - each card uses 2 of the slits on each side
- **INSIDE DIVIDER FOLD →** make the hole slightly bigger to make it easier to grab

-------------------------------------------------

### Order of things in the box ⬆️

1. DEVICE
2. INSTRUCTION CARD (STEP NUMBERS FACING UP)
3. KEYCARDS
*—————— FOLD DIVIDER ——————*
4. INSTRUCTION & SAFETY USER MANUAL
5. BATTERY + CABLE

guylouis, 2025-05-19:
we will need to reserve a place on the packaging to stick a sticker with the serial number
https://github.com/keycard-tech/keycard-shell/issues/80

guylouis, 2025-05-23:
[KEYCARD_coffret_v1_23052025.pdf](https://github.com/user-attachments/files/20412076/KEYCARD_coffret_v1_23052025.pdf) new prototype

guylouis, 2025-07-14:
packaging had been improved, see the die cut below
samples to be received end of July - early August max

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

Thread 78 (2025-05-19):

help users use Shell in a 100% airgaped manner

guylouis, 2025-05-19:
# context

Shell gets input (e.g. get a transaction, a new firmware, an updated database of erc-20, a challenge to verify it's genuine) with
- USB
- camera

One of the added value of Shell is that it can be used airgapped. One feature available in Shell is to disable data over USB, if you want to plug Shell to your computer to charge it and be sure that no data is travelling over the USB cable.

Firmware upgrade needs a lot of data to be downloaded (typically 150kB+) and it cannot be down reliably over QR.

# documentation

we should help users understand how to perform some operations if they want to keep airgapped
- charging:
      - charge with a standard power supply (no computer) you trust
      - go to settings and remove data connection from Shell if you don't trust the power source (computer etc.)
- firmware upgrade
      - explain that the firmware can be downloaded on github
      - downloaded onto a airgapped computer by USB
      - use this airgapped computer to update Shell

to be decided: how can we provide the right browser page and javascript for the airgapped computer to update shell? @bitgamma

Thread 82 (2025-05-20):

test bitcoin multisig

guylouis, 2025-05-20:

bitgamma, 2025-06-04:
currently popular MultiSig schemes for bitcoin need to be tested. Needs some research to understand what is currently relevant. @phift can you help with this?

phift, 2025-06-05:
## Possible implementation

Generation | On-chain format | Crypto primitive | What Keycard still needs | Difficulty on Keycard | Roll-out/Relevance
-- | -- | -- | -- | -- | --
1 | P2SH (legacy “3…”) | ECDSA CHECKMULTISIG | Nothing new cryptographically; just add P2SH redeem-script handling in the MCU parser. | Low – the secure element already does ECDSA; extra code is small. | Probably not needed
2 | P2WSH (native SegWit “bc1q…0…”) | ECDSA CHECKMULTISIG | Nothing. PSBT-v0 and current ECDSA engine are sufficient. | Low – ready today. | covers the vast majority of live multisig flows.
3a | P2TR script-path | Schnorr CHECKSIGADD | BIP-340 Schnorr signing + x-only pubkey export. | Medium – fits in JCOP4; ≈ 40 ms per sig. | Users keep the same MCU firmware; flash a new Java-Card applet
3b | P2TR key-path | MuSig2 (n-of-n key aggregation) | Schnorr + 2-round nonce storage per input + new PSBT keys. | Hard – needs persistent nonce slots and anti-reuse logic inside the card. | Could become relevant for a Shell v2 – once BIP 327 is final
3c | P2TR key-path | FROST (m-of-n threshold) | Secret-share setup + multi-round signing protocol. | Very hard on a single signer card; heavy state management. | Probably unnecessary for > 95 % of users in 2025; better served by an external coordinator later

1. First step: SegWit native multisig - P2WSH sortedmulti (Generation 2)

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

2. Legacy P2SH multisig (Generation 1) is optional: could support, but it burns 15 % more bytes per spend and very little new infrastructure still requires it

bitgamma, 2025-06-05:
Now can correctly pair with Sparrow, however PSBT parsing needs to be extended to properly support this kind of transactions

phift, 2025-06-06:
The setup in Sparrow works! Haven't tested tx, though.

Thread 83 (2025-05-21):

add alpha build design files to github

guylouis, 2025-05-21:
alpha build corresponds to ER (engineering run)
we built 20 products, delivered end of April 2025
need to update all design files (hardware, casing) on github

guylouis, 2025-05-23:
done https://github.com/keycard-tech/keycard-shell/tree/master/hardware/
under P2 prototypes folder

there are two folders
- one with a step file with the full design including the electronics. Can be used to make very nice renders btw.
- one where for each plastic piece: a step file + a 2D file with all dimensions and tolerances

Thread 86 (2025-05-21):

add development board hw design in github

guylouis, 2025-05-21:
we need developers to be able to build their own development board if they want to

share:
- schematics
- pcb layout (gerbers)
- bill of material

guylouis, 2025-08-13:
somehow blocked because of budget restrictions
it would be awesome to find a contributor who's willing to work on this

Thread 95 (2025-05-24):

Improve message for cases when it's not clear if it not Keycard  or Keycard inserted the wrong way

xAlisher, 2025-05-24:
Issue:
Improve error messaging when the card is unreadable due to ambiguity—it's currently unclear whether the problem is that the user is not using a Keycard, or that the Keycard is inserted incorrectly.

Current behavior:
The message shown is too generic and doesn’t guide the user toward resolving the issue effectively.

Expected behavior:
A clearer message that covers both potential causes, e.g.:
“Can’t read the card. Make sure you’re using a Keycard and that the chip is facing the right way.”

Closed 2025-05-28.

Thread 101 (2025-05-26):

Add Shell testimonials to keycard website

phift, 2025-05-26:
### Situation

We show plenty of specs, but zero social proof. A tiny testimonial block (3–5 short quotes) on both the homepage (`/`) and the Keycard Shell page (`/keycard-shell`) should lift trust and conversion.

---

### What to do

1. **Create one reusable component** – `Testimonials.tsx` (lives in `src/app/_components/`).
2. **Insert it**

* On `keycard-shell/page.tsx`: right above the final **Pre-order** CTA.
* On the homepage: between the header section and comparison table.
3. **Content**

* We can get from a couple of early testers we already had!

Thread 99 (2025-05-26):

[Doc] Change the Shell battery

cheny0, 2025-05-26:
As mentioned in https://github.com/keycard-tech/keycard-shell/issues/39, when removing the battery, you need to use the card

Closed 2025-08-01.

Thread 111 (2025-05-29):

Implement faster autocomplete input

bitgamma, 2025-05-29:
Introduce an alternate suggestion input:

- Show a full list of valid words to choose from.
- Reduce number active keys with every character selected to minimize navigation steps.

Overview
This update targets common tester friction in the current flow. Plan minimum is low-effort and already resolves major confusion. Plan maximum adds predictability and significantly faster word input.

Proposal: https://www.notion.so/Shell-input-improvements-14d8f96fb65c80f0bf76ff1ff1190570 (note: design and keyboard layout outdated)
Figma https://www.figma.com/design/I4NT4JGHDEVSQ2yo5Z4mju/Shell-OS?node-id=5055-140967&t=5ZdeBNICwB1bczF1-1

bitgamma, 2025-06-13:
preliminary implementation included in 0.9.17. Navigation skipping disabled letters still missing but the rest only needs some polishing and resolving the two points above

Closed 2025-06-23.

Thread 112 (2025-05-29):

Add possibility to correct words on Invalid phrase entered screen

phift, 2025-05-29:
### Description
When users enter an invalid phrase during the recovery phrase input process in the backup flow, but doesn't notice until after the 12th word, on the `Invalid phrase entered` screen, they are forced to restart from the beginning.
This creates frustration, especially when the error is minor (e.g., a single incorrect word). Allowing users to navigate back to a specific word instead of restarting would improve the user experience.

---

#### Key issues:
- Restarting the entire phrase input process for a single error is inefficient and frustrating
- No option exists to edit or revisit a specific word in the phrase
- Users may abandon the process due to repetitive restarts, increasing user friction

---

### Suggested improvements:
- Add navigation controls similar to the current `Import seed phrase` flow https://github.com/keycard-tech/keycard-shell/issues/50 - to allow users to revisit and edit specific words in the phrase

---

### Resources
https://www.figma.com/design/I4NT4JGHDEVSQ2yo5Z4mju/Shell-OS?node-id=0-1

bitgamma, 2025-06-03:
my proposal is to go back to the input of the first word, without deleting the previously inserted words, which will be presented as auto-complete. This way the user reviews each word and corrects the wrong one(s) - just long-pressing OK on correct ones. This consistently requires 12 or 24 long-presses of OK + the input of any correction to finish the flow.

 I think this is better than restarting from the last word, since this would require navigating backward to find the error and then all the way forward again to get to the last word, potentially doubling the number of key presses required

@phift @xAlisher wdyt?

xAlisher, 2025-06-03:
Cool! +1

phift, 2025-06-03:
Sounds good!

Closed 2025-06-16.

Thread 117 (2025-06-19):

Create the Help page on the Keycard website

cheny0, 2025-06-19:
- We need to add a new page for user documentation with the url `keycard.tech/help`. This is the Figma file: https://www.figma.com/design/RSszWiHjK6os09PEDmJ0gR/Website---Keycard?node-id=4986-8236&t=Peq57Pppaxz3j2gj-4
- This is the Figma file for visual elements in articles: https://www.figma.com/design/RSszWiHjK6os09PEDmJ0gR/Website---Keycard?node-id=4271-17862&t=Peq57Pppaxz3j2gj-4 (Elements that involve non GitHub-flavored Markdown components are not priorities)
- Update the current documentation URL and website footer

xAlisher, 2025-07-28:
@felicio please share with us how it's going

xAlisher, 2025-08-06:
> [@xAlisher](https://github.com/xAlisher) what release date are you targeting?

@guylouis question for you 🙏

guylouis, 2025-08-06:
I expect Shells to be shipped in early 12/2025
For information, delays came from the battery certification :(

guylouis, 2025-10-03:
not sure: what's preventing to close this? @jkbktl

Closed 2025-10-03.

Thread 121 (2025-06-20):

Verify authenticity of Shell

xAlisher, 2025-06-20:
Create user flow of Shell Verification.
Start point https://shell.keycard.tech/verify
Linked with Quick Start Guide.

Parent issue:: https://github.com/keycard-tech/keycard-shell/issues/110

xAlisher, 2025-07-28:
@guylouis @Rsttskyy Let's test!

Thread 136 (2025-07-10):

Create unified UX to update firmware and token db via cable

xAlisher, 2025-07-10:
Following this discussion it was agreed to combine updating of firmware and token DB in one flow.

https://discord.com/channels/1366754869561790474/1392436342830530653/1392436347117244518

Rsttskyy, 2025-07-12:
Figma
https://www.figma.com/design/RSszWiHjK6os09PEDmJ0gR/Website---Keycard?node-id=7598-39562&t=7wBBQi0Sogu5kAOM-1

Prototype

Lottie animation
Demo - https://soft-branding-758712.framer.app/

Code:
`<script
  src="https://unpkg.com/@lottiefiles/dotlottie-wc@0.6.2/dist/dotlottie-wc.js"
  type="module"
></script>

<dotlottie-wc
  src="https://lottie.host/0ab81f68-e20a-446d-9363-b897ff67bd50/cLYIbtLguC.lottie"
  style="width: 590px;height: 344px"
  speed="1.6"
  autoplay
  loop
></dotlottie-wc>`

Rsttskyy, 2025-07-12:
Ultra wide screen layout behavior
https://www.figma.com/design/RSszWiHjK6os09PEDmJ0gR/Website---Keycard?node-id=7833-16867&t=i0W6WuJrkITjxoUF-1

Demo (resize window to see behavior)
https://soft-branding-758712.framer.app

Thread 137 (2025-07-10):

Create dedicated web page for "Full air-gapped update" with instructions and links.

xAlisher, 2025-07-10:
Create dedicated web page for "Full air-gapped update" with instructions and links and connect it to Update landing.

Draft of the content.

## Update Shell in full-airgapped mode

If you’d like your Keycard Shell to *never* touch the internet, follow these instructions to update it in a fully offline environment.

### 1. Prepare a disconnected device

Use a laptop or PC that has **never been connected to the internet**. This ensures it’s free from malware, spyware, or suspicious software.

### 2. Download the standalone updater

This app runs in an offline browser and allows you to connect your Keycard Shell and transfer updates.

**Select your operating system**:

* macOS
* Windows
* Linux

**Download** (version x.x.x)

### 3. Download the updates you’d like to install

* **Token database**
* **Firmware update**

### 4. Prepare your USB stick

Copy the downloaded files to a USB stick.

### 5. Update your Keycard Shell

1. Insert the USB stick into the offline device
2. Launch the standalone updater
3. Unlock your Keycard Shell and connect it via the supplied USB-C cable
4. Select the update files
5. Follow the instructions on the Shell screen

If you have any questions or run into issues, check out the help article (link) or ask in our Discord community (link).

Closed 2025-07-28.

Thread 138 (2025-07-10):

Update visual style of standalone updater

xAlisher, 2025-07-10:
Update visual style and assets of standalone updater to match with Keycard Shell website visual style.
Link to current version: https://github.com/choppu/kshell-updater

Rsttskyy, 2025-07-28:
https://www.figma.com/design/RSszWiHjK6os09PEDmJ0gR/Website---Keycard?node-id=6088-46702&t=uQ8mPUJbtZCPFsW3-1

xAlisher, 2025-07-28:
Review UI details with @Rsttskyy

choppu, 2025-10-04:
Yes, this one can be closed. This one is already implemented.

Rsttskyy, 2025-10-05:
Icon updated
https://www.figma.com/design/RSszWiHjK6os09PEDmJ0gR/Website---Keycard?node-id=6987-6811&t=tBQqcyfvaxFwOYsE-1

Changes:
- Clear case added
- orange bg changed to black

Reason: orange not works visually good combined with clear case.

Closed 2025-10-04.

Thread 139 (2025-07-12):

Have a .stl project of Shell on printable.com

guylouis, 2025-07-12:
The current files (steps) we have for Shell have been designed and optimized for plastic injection in our steel mold. If we want diy home builders to print a casing and use it with their electronics, we can help them by
- exporting the designs to a .stl files
- check/experiment/modify them to make sure the assembly works
- upload them on printable.com

xAlisher, 2025-07-14:
I'm in process of communication with Printables

xAlisher, 2025-08-11:
Printables do not reply.

Considering alternatives.

Thingiverse – The original big repository for 3D printing files, still widely used.

Cults3D – Popular with designers selling or freely sharing STL and other files.

Thangs – 3D model search and hosting with collaboration tools.

Libre3D – Fully open-source repository for 3D printable models.

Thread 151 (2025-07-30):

design and print sample of the regulatory leaflet

guylouis, 2025-07-30:
For regulatory reasons in europe, usa, and canada we need to print a leaflet that we will put in Keycard shell box.

This leaflet includes
- use and care recommendations for the product
- warnings for the battery
- european regulatory declaration
- usa regulatory declaration
- canada regulatory declaration

Here's a draft for the content of the leaflet https://docs.google.com/document/d/1JTA68iDlfdyYfmAgcMc36htxLo5xAx9b8aHBHjhYCi8/edit?usp=sharing

guylouis, 2025-08-20:
These suppliers tend to ask us to provide full detail about the formats we want, so @Francesca-G may you put the 6 pages just like the picture above on one sheet
- printed only on the front (no back printing)
- same folding idea (we can use the picture above to illustrate the folding we want)
- as for the size let's consider a size that makes it compatible with putting it on the top compartment (but I think we will put it on the bottom compartment), it leaves us some flexbility.

Thanks!

Francesca-G, 2025-08-22:
- Size when the leaflet is close: 65x100mm (same as Quick Start Guide card)
- Total size of the leaflet (6 pages): 195x200mm

[Regulatory_Leaflet_195x200.pdf](https://github.com/user-attachments/files/21935236/Regulatory_Leaflet_195x200.pdf)

Closed 2025-09-08.

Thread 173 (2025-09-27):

Unable to connect to Rabby desktop/extension on Framework 16

xAlisher, 2025-09-27:
I'm flagging an issue I encountered while trying to connect Rabby (both desktop and extension) to Keycard Shell on my Framework 16 laptop. The QR code scanning consistently failed.

**Analysis:**
The root cause appears to be a hardware limitation on certain webcams. The issue is a combination of the camera's fixed minimum focus distance and the relatively small size of the QR code presented in the Shell UI. The webcam can't focus on the QR code when it's held close, and the code is too small to be read when held far enough away to be in focus.

I found a workaround by taking a photo of the QR code on my phone, zooming in on the photo, and then presenting it to the webcam. This worked immediately.

**Broader Impact & Research:**
This problem is likely not limited to Framework. My research indicates a clear divide in webcam performance based on the laptop's hardware:

* **Laptops with an NPU (Neural Processing Unit):** Models like modern Apple MacBooks, Microsoft Surface, Dell XPS, HP Spectre, and high-end Lenovo ThinkPads use aggressive software processing. This allows them to recognize QR codes even when slightly out of focus or at a distance.

* **Laptops without an NPU:** Models like the Framework, TUXEDO Computers, Slimbook, and standard business lines (Lenovo ThinkPad T/L-series, Dell Latitude 5000/7000 series, HP EliteBook 600/800 series) use more standard webcams and are highly likely to face the same issue.

**Suggested Next Steps:**
1.  **UI Enhancement:** Can we explore options to make the QR code significantly larger on the Keycard Shell screen? This seems like the most direct fix for our users. @bitgamma
2.  **QA & Documentation:** We should log this behaviour and expand our hardware testing to include some of the non-NPU laptops mentioned above to confirm the scope of the problem.

Let me know your thoughts.

romanzac, 2025-09-29:
Hi @xAlisher I would like to add:
- When I had problems with QR code recognition, I tried a trick from photography: Hold Shell with both hands at the best focus point. Stop breathing. Wait for recognition. I've logged [problems with Rabby even on my Macbook Pro M4](https://www.notion.so/3rd-Party-Wallet-Integration-Tests-22b8f96fb65c80faa06fcc195373624b), so I am not sure the degree of NPU impact. It could be also camera resolution, room light and other factors which could affect recognition.
- Increasing size of the QR code would probably make it more readable also for security cameras in the room. I would be cautious here. This could be solved with display not being readable from wide angle. QR recognition could be further enhanced with backlight. Not sure where the threshold may sit. I'm open to experiment.
- I'm open to purchase suggested laptop - Taiwan has good prices - It won't burn a lot from project bugdet.

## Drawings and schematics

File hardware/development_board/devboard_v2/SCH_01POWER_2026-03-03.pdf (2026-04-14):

# USB POWER INPUT & DATA

# BATTERIY MANAGEMENT

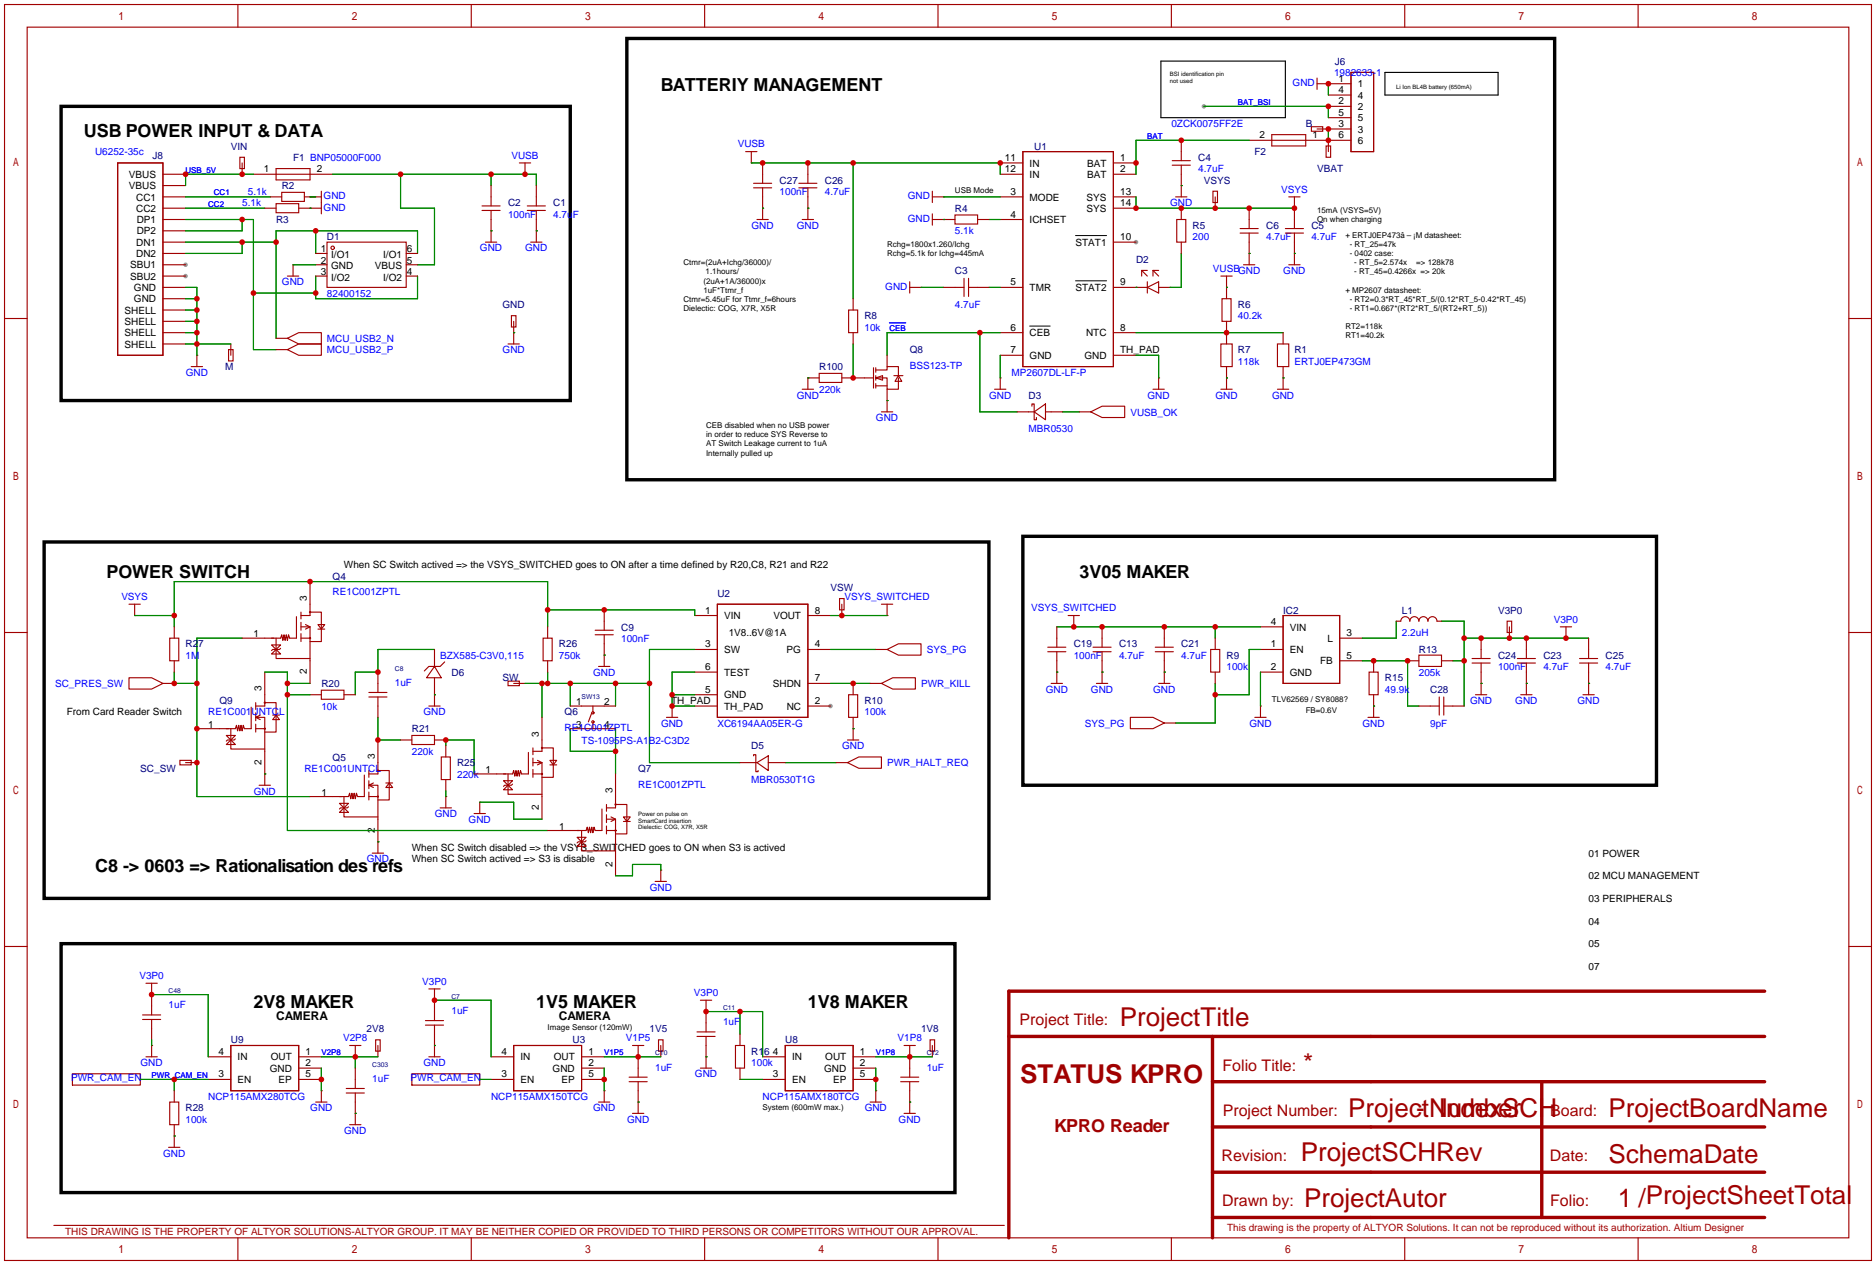
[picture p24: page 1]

CEB disabled when no USB power
in order to reduce SYS Reverse to
AT Switch Leakage current to 1uA
Internally pulled up

When SC Switch actived => the VSYS_SWITCHED goes to ON after a time defined by R20,C8, R21 and R22
RE1C001ZPTL

From Card Reader Switch

Power on pulse on
SmartCard insertion
Dielectic: COG, X7R, X5R

When SC Switch disabled => the VSYS_SWITCHED goes to ON when S3 is actived
When SC Switch actived => S3 is disable

THIS DRAWING IS THE PROPERTY OF ALTYOR SOLUTIONS-ALTYOR GROUP. IT MAY BE NEITHER COPIED OR PROVIDED TO THIRD PERSONS OR COMPETITORS WITHOUT OUR APPROVAL.

This drawing is the property of ALTYOR Solutions. It can not be reproduced without its authorization. Altium Designer

# MCU PIN OUT - PA PB PC PC

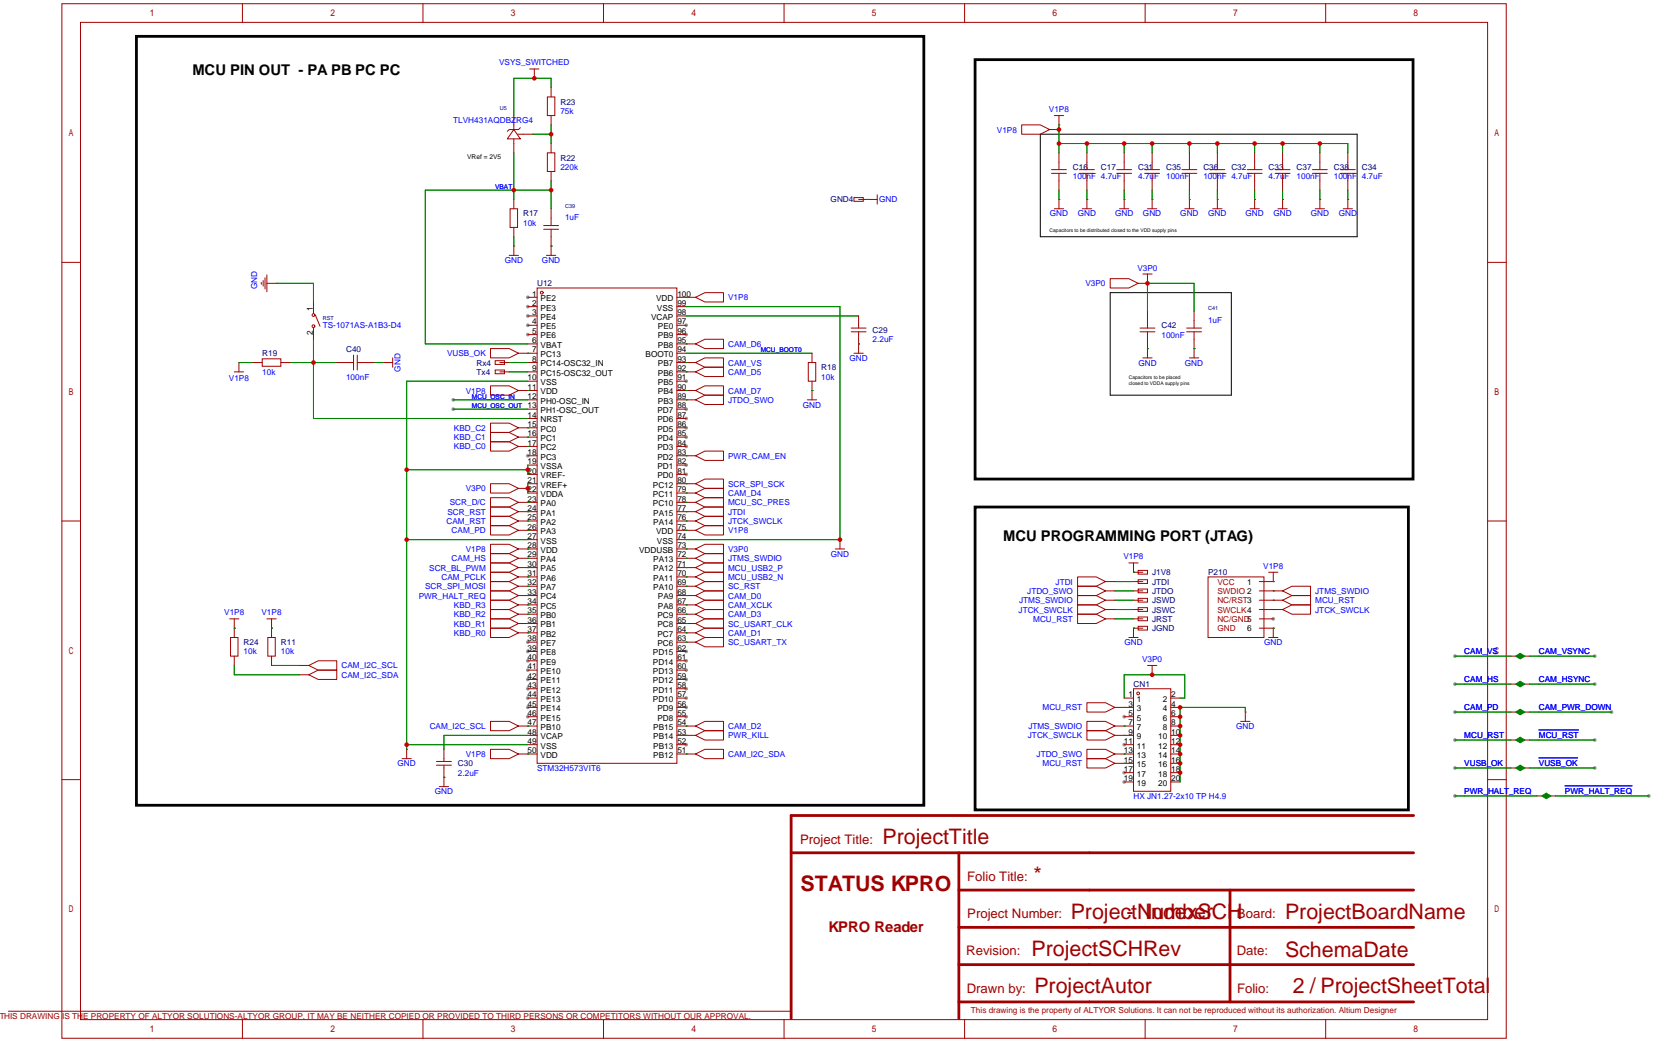
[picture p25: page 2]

Capacitors to be distributed closed to the VDD supply pins

Capacitors to be placed
closed to VDDA supply pins

MCU PROGRAMMING PORT (JTAG)

KEYBOARD MATRIX | SCREEN CONNECTION | CAMERA CONNECTION HREF have to be validated

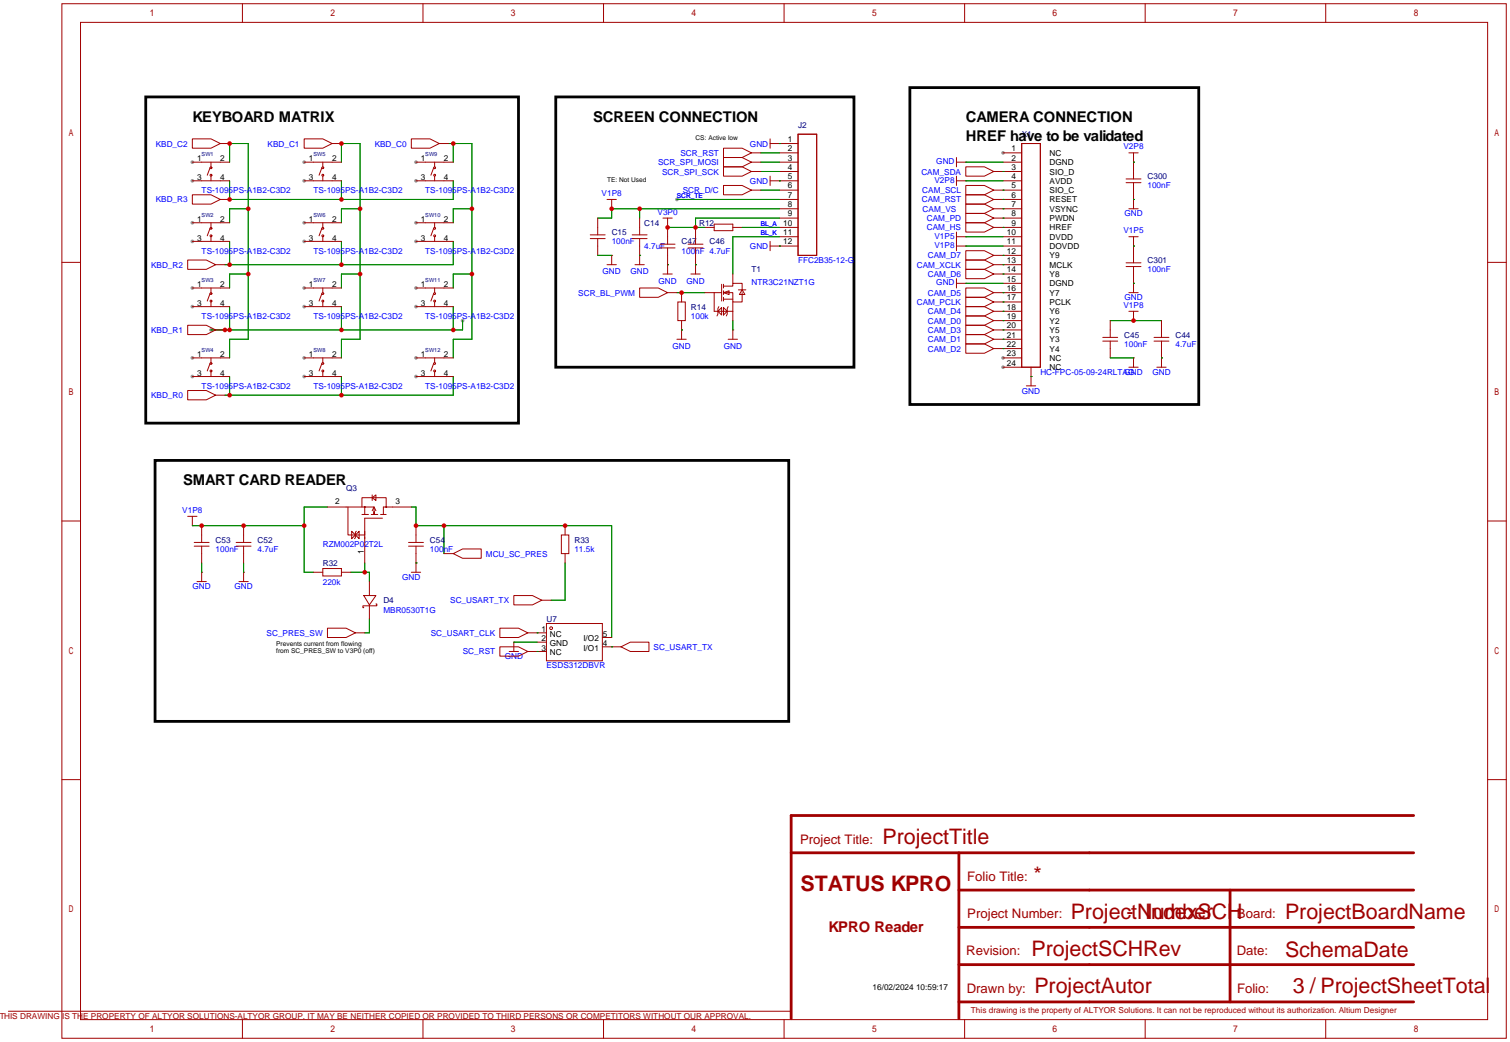
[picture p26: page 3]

SC_PRES_SW
Prevents current from flowing
from SC_PRES_SW to V3P0 (off)

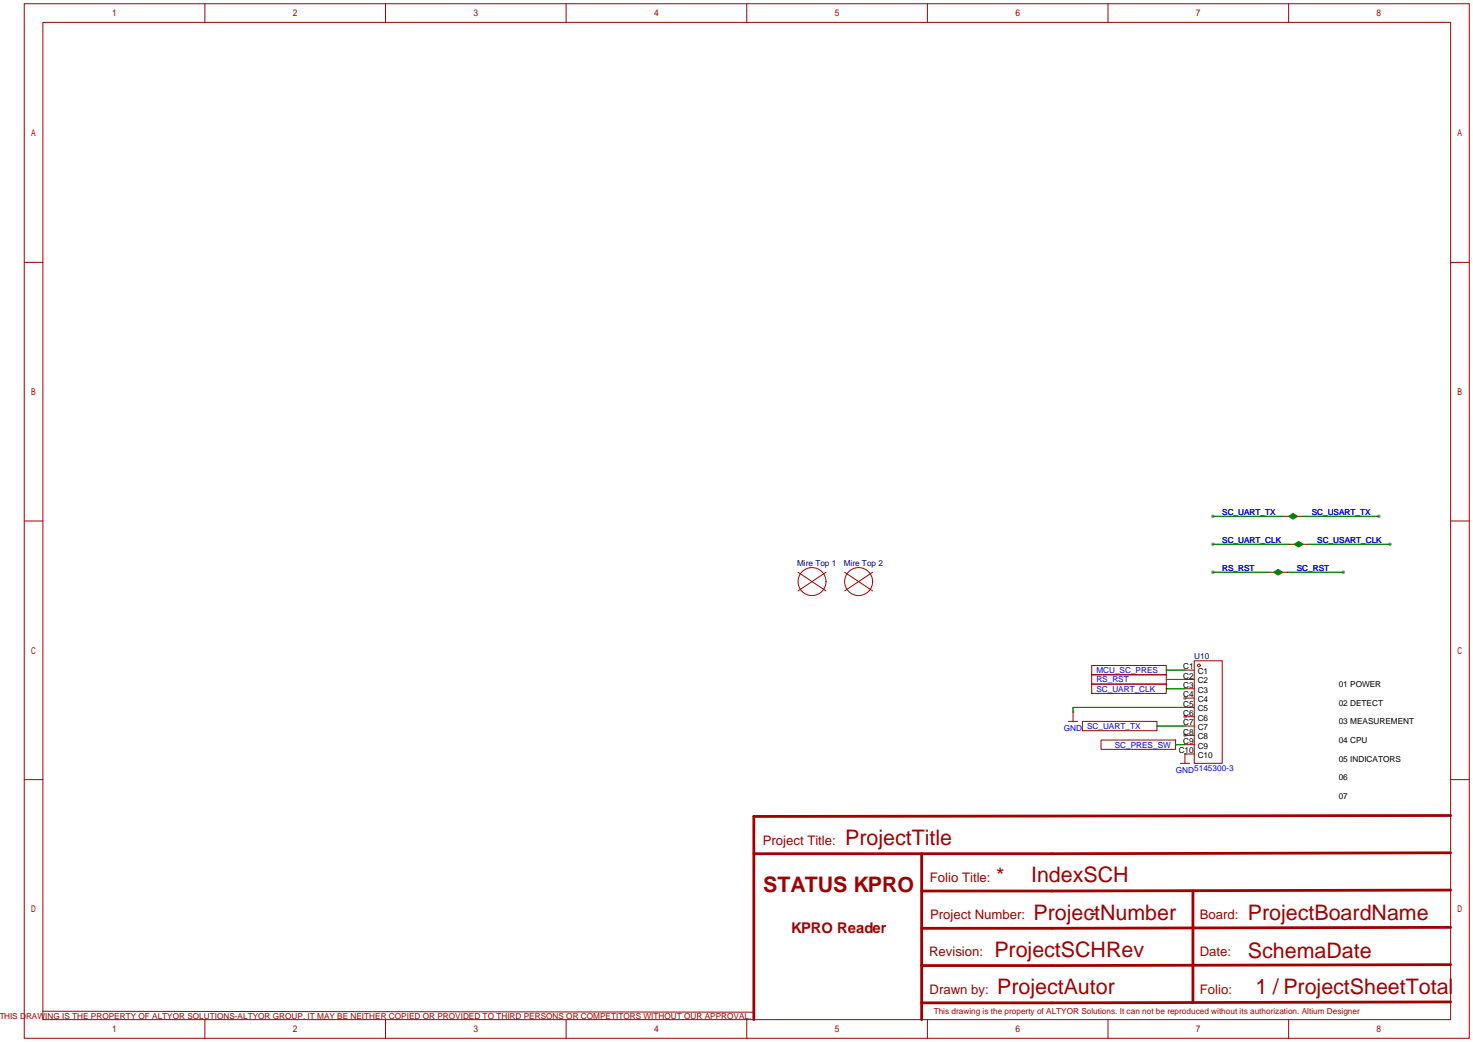
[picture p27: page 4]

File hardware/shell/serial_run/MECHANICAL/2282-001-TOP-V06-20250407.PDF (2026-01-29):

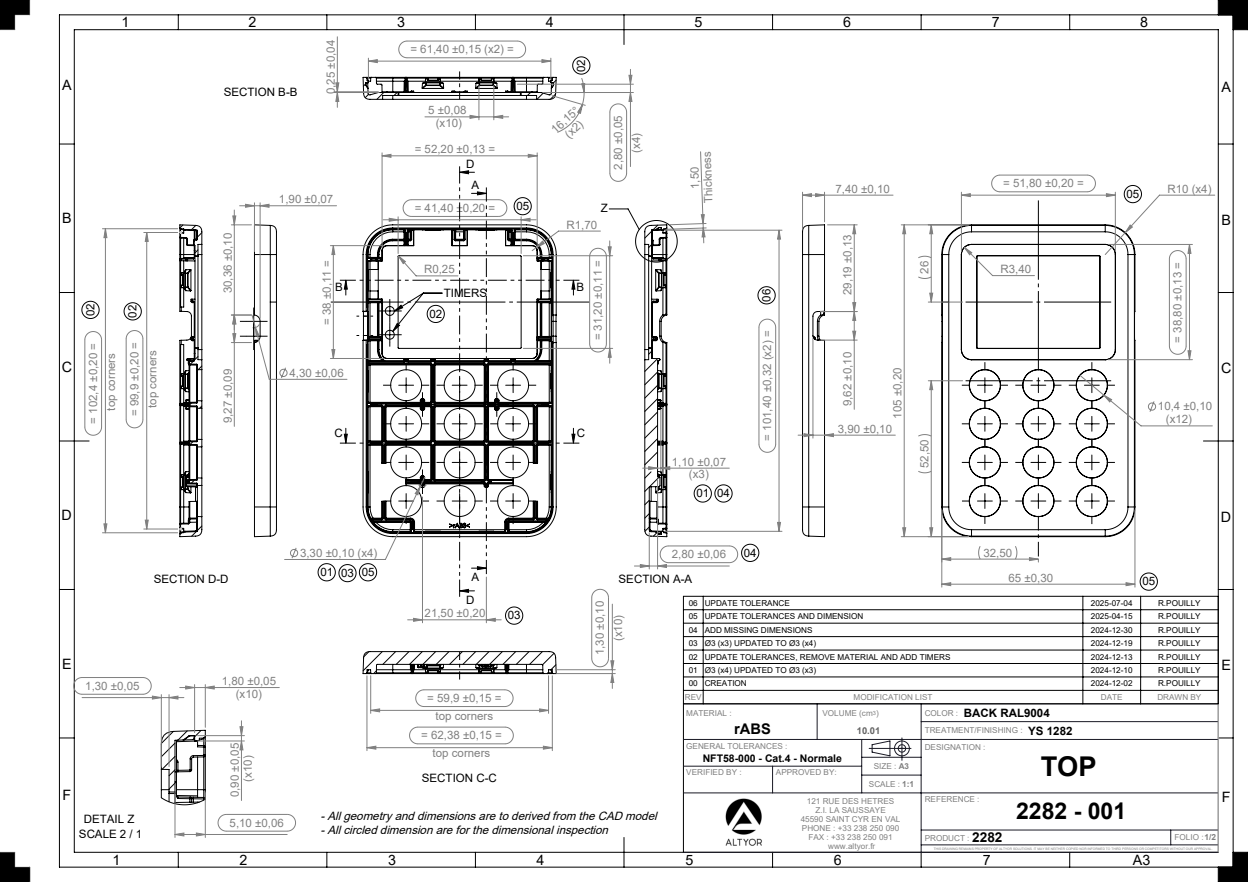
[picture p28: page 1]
SECTION B-B; SECTION A-A; DETAIL Z; SCALE 2 / 1 = 102,4 ±0,20 =; top corners; SECTION D-D; = 62,38 ±0,15 = top corners; = 59,9 ±0,15 = top corners; SECTION C-C; rABS; BACK RAL9004; TREATMENT/FINISHING :; VOLUME (cm3); COLOR :; MATERIAL :; SIZE : A3; SCALE :

06 | UPDATE TOLERANCE | 2025-07-04 | R.POUILLY
05 | UPDATE TOLERANCES AND DIMENSION | 2025-04-15 | R.POUILLY
04 | ADD MISSING DIMENSIONS | 2024-12-30 | R.POUILLY
03 | Ø3 (x3) UPDATED TO Ø3 (x4) | 2024-12-19 | R.POUILLY
02 | UPDATE TOLERANCES, REMOVE MATERIAL AND ADD TIMERS | 2024-12-13 | R.POUILLY
01 | Ø3 (x4) UPDATED TO Ø3 (x3) | 2024-12-10 | R.POUILLY
00 | CREATION | 2024-12-02 | R.POUILLY
REV | MODIFICATION LIST | DATE | DRAWN BY

GENERAL TOLERANCES : NFT58-000 - Cat.4 - Normale | | DESIGNATION : TOP

VERIFIED BY : | APPROVED BY:

121 RUE DES HETRES Z.I. LA SAUSSAYE 45590 SAINT CYR EN VAL PHONE : +33 238 250 090 FAX : +33 238 250 091 www.altyor.fr | REFERENCE : 2282 - 001

- All geometry and dimensions are to derived from the CAD model
- All circled dimension are for the dimensional inspection

2282 PRODUCT : | FOLIO : 1/2

THIS DRAWING REMAINS PROPERTY OF ALTYOR SOLUTIONS. IT MAY BE NEITHER COPIED NOR INFORMED TO THIRD PERSONS OR COMPETITORS WITHOUT OUR APPROVAL.

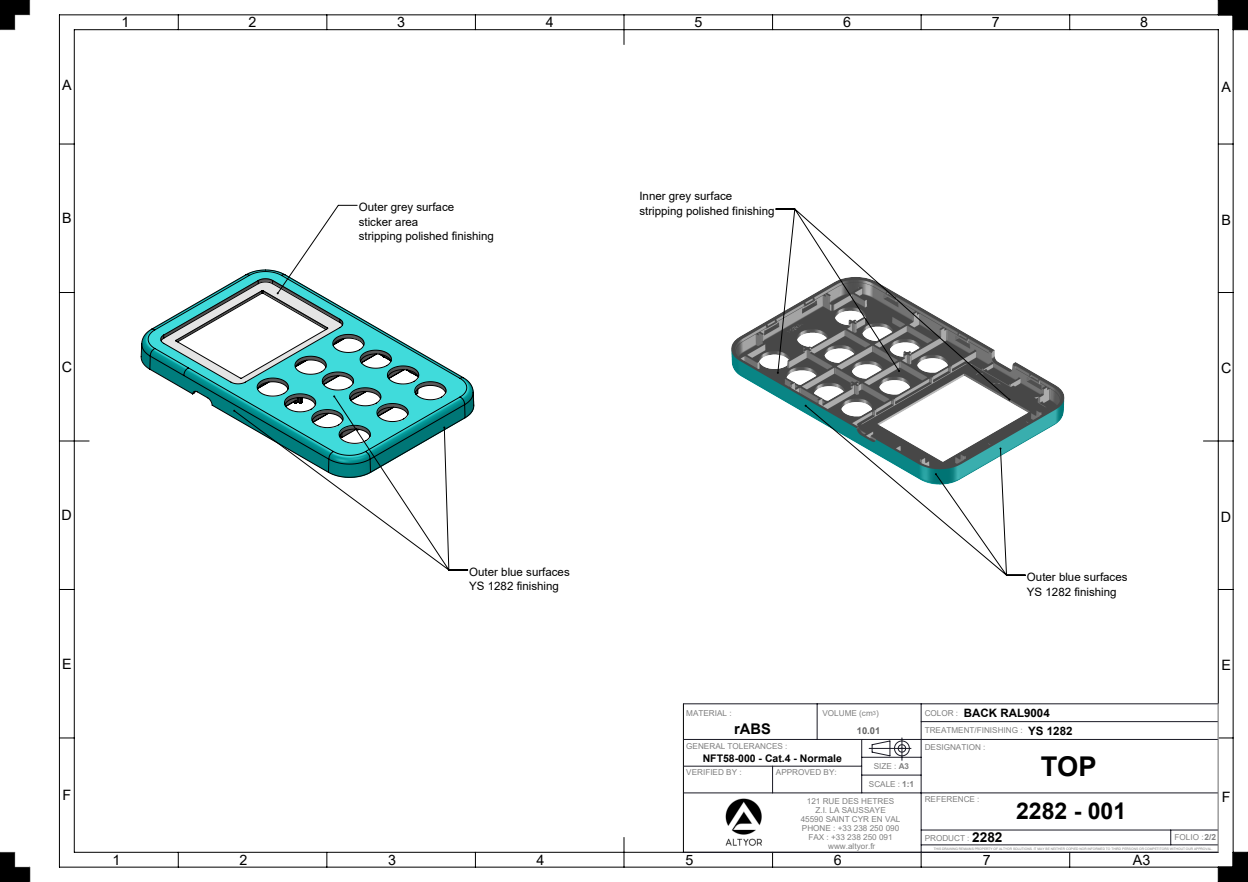
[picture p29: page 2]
rABS; BACK RAL9004; TREATMENT/FINISHING :; VOLUME (cm3); COLOR :; MATERIAL :; SIZE : A3; SCALE :

Inner grey surface
stripping polished finishing

Outer grey surface
sticker area

Outer blue surfaces
YS 1282 finishing

GENERAL TOLERANCES : NFT58-000 - Cat.4 - Normale | | | DESIGNATION : TOP

VERIFIED BY : | APPROVED BY:

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

2282 PRODUCT : | FOLIO : 2/2

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

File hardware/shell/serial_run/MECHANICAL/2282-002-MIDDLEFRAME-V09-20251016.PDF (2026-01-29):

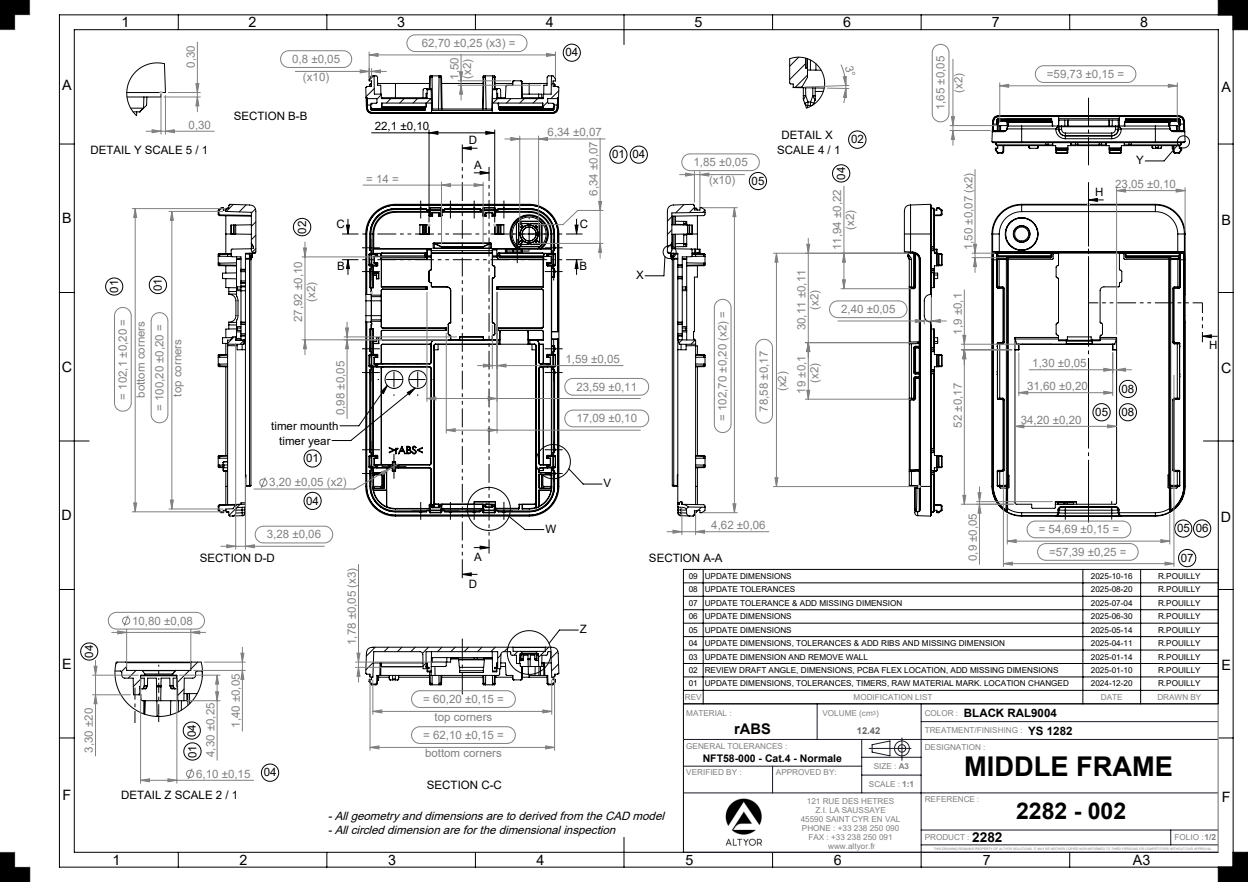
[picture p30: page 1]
timer year; timer mounth; SECTION A-A; SECTION B-B; = 60,20 ±0,15 = top corners; = 62,10 ±0,15 = bottom corners; SECTION C-C; bottom corners; top corners; 3,28 ±0,06 SECTION D-D 1,40 ±0,05; 4,30 ±0,25 DETAIL Z SCALE 2 / 1 01 04; DETAIL Y SCALE 5 / 1; DETAIL X SCALE 4 / 1; rABS; BLACK RAL9004; TREATMENT/FINISHING :; VOLUME (cm3); COLOR :; MATERIAL :; SIZE : A3; SCALE :

09 | UPDATE DIMENSIONS | 2025-10-16 | R.POUILLY
08 | UPDATE TOLERANCES | 2025-08-20 | R.POUILLY
07 | UPDATE TOLERANCE & ADD MISSING DIMENSION | 2025-07-04 | R.POUILLY
06 | UPDATE DIMENSIONS | 2025-06-30 | R.POUILLY
05 | UPDATE DIMENSIONS | 2025-05-14 | R.POUILLY
04 | UPDATE DIMENSIONS, TOLERANCES & ADD RIBS AND MISSING DIMENSION | 2025-04-11 | R.POUILLY
03 | UPDATE DIMENSION AND REMOVE WALL | 2025-01-14 | R.POUILLY
02 | REVIEW DRAFT ANGLE, DIMENSIONS, PCBA FLEX LOCATION, ADD MISSING DIMENSIONS | 2025-01-10 | R.POUILLY
01 | UPDATE DIMENSIONS, TOLERANCES, TIMERS, RAW MATERIAL MARK. LOCATION CHANGED | 2024-12-20 | R.POUILLY
REV | MODIFICATION LIST | DATE | DRAWN BY

GENERAL TOLERANCES : NFT58-000 - Cat.4 - Normale | | DESIGNATION : MIDDLE FRAME

VERIFIED BY : | APPROVED BY:

121 RUE DES HETRES Z.I. LA SAUSSAYE 45590 SAINT CYR EN VAL PHONE : +33 238 250 090 FAX : +33 238 250 091 www.altyor.fr | REFERENCE : 2282 - 002

- All geometry and dimensions are to derived from the CAD model
- All circled dimension are for the dimensional inspection

2282 PRODUCT : | FOLIO : 1/2

THIS DRAWING REMAINS PROPERTY OF ALTYOR SOLUTIONS. IT MAY BE NEITHER COPIED NOR INFORMED TO THIRD PERSONS OR COMPETITORS WITHOUT OUR APPROVAL.

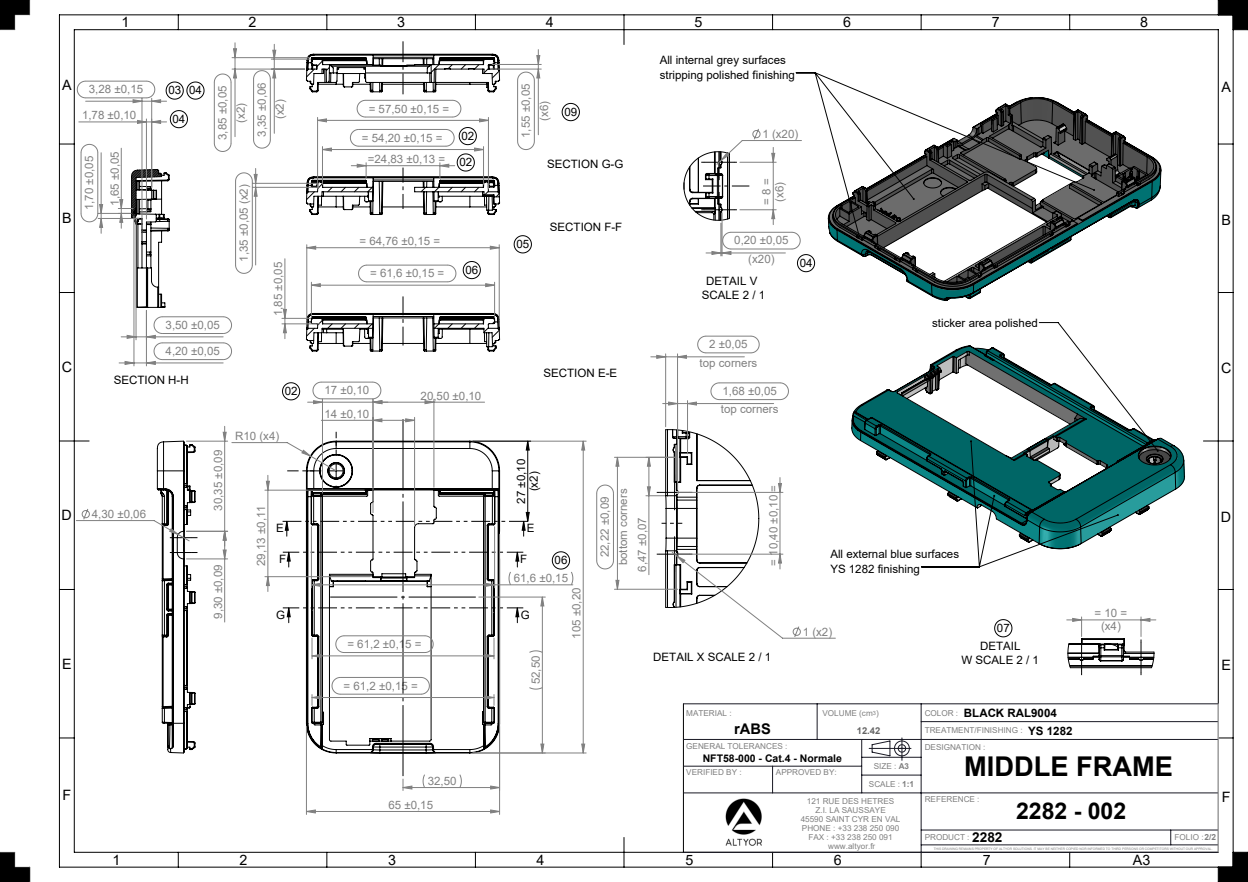
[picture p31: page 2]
SECTION E-E; SECTION F-F; SECTION G-G; bottom corners; 1,68 ±0,05 top corners; 2 ±0,05 top corners; DETAIL X SCALE 2 / 1; SECTION H-H; DETAIL V SCALE 2 / 1; W SCALE 2 / 1; rABS; BLACK RAL9004; TREATMENT/FINISHING :; VOLUME (cm3); COLOR :; MATERIAL :; SIZE : A3; SCALE :

All internal grey surfaces
stripping polished finishing

sticker area polished

All external blue surfaces
YS 1282 finishing

GENERAL TOLERANCES : NFT58-000 - Cat.4 - Normale | | DESIGNATION : MIDDLE FRAME

VERIFIED BY : | APPROVED BY:

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

2282 PRODUCT : | FOLIO : 2/2

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

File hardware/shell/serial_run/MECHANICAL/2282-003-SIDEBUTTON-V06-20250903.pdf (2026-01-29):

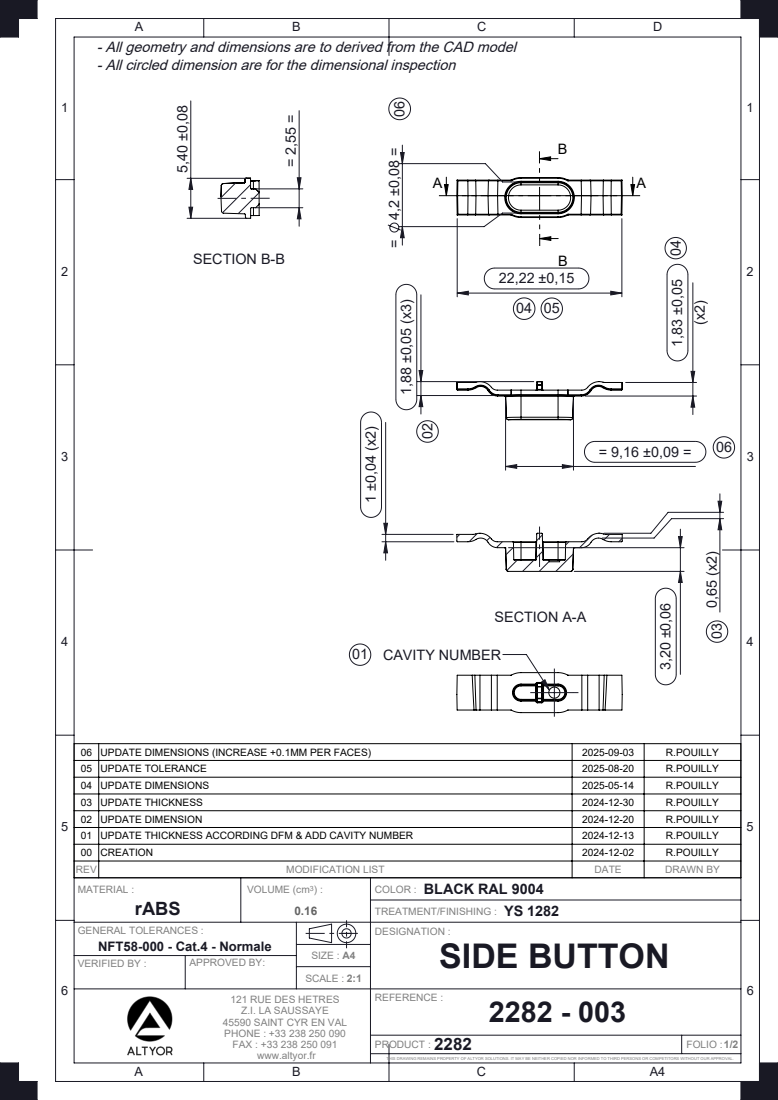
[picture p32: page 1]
SECTION A-A; SECTION B-B; CAVITY NUMBER; SCALE :; SIZE : A4; MATERIAL :; VOLUME (cm3) :; COLOR :; TREATMENT/FINISHING :; BLACK RAL 9004; rABS

- All geometry and dimensions are to derived from the CAD model
- All circled dimension are for the dimensional inspection

06 | UPDATE DIMENSIONS (INCREASE +0.1MM PER FACES) | 2025-09-03 | R.POUILLY
05 | UPDATE TOLERANCE | 2025-08-20 | R.POUILLY
04 | UPDATE DIMENSIONS | 2025-05-14 | R.POUILLY
03 | UPDATE THICKNESS | 2024-12-30 | R.POUILLY
02 | UPDATE DIMENSION | 2024-12-20 | R.POUILLY
01 | UPDATE THICKNESS ACCORDING DFM & ADD CAVITY NUMBER | 2024-12-13 | R.POUILLY
00 | CREATION | 2024-12-02 | R.POUILLY
REV | MODIFICATION LIST | DATE | DRAWN BY

GENERAL TOLERANCES : NFT58-000 - Cat.4 - Normale | | DESIGNATION : SIDE BUTTON

VERIFIED BY : | APPROVED BY:

121 RUE DES HETRES Z.I. LA SAUSSAYE 45590 SAINT CYR EN VAL PHONE : +33 238 250 090 FAX : +33 238 250 091 www.altyor.fr | REFERENCE : 2282 - 003

PRODUCT : | FOLIO : 1/2

THIS DRAWING REMAINS PROPERTY OF ALTYOR SOLUTIONS. IT MAY BE NEITHER COPIED NOR INFORMED TO THIRD PERSONS OR COMPETITORS WITHOUT OUR APPROVAL.

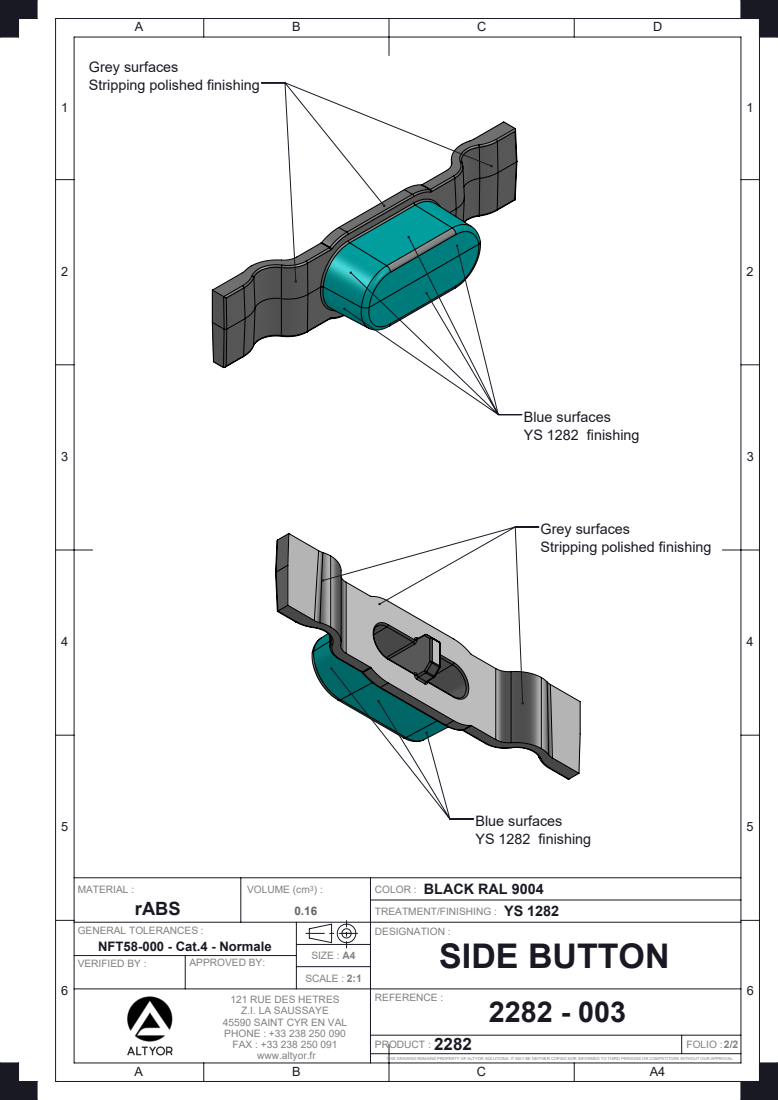
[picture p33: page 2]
Blue surfaces YS 1282 finishing; SCALE :; SIZE : A4; MATERIAL :; VOLUME (cm3) :; COLOR :; TREATMENT/FINISHING :; BLACK RAL 9004; rABS

Grey surfaces
Stripping polished finishing

GENERAL TOLERANCES : NFT58-000 - Cat.4 - Normale | | | DESIGNATION : SIDE BUTTON

VERIFIED BY : | APPROVED BY:

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

PRODUCT : | FOLIO : 2/2

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

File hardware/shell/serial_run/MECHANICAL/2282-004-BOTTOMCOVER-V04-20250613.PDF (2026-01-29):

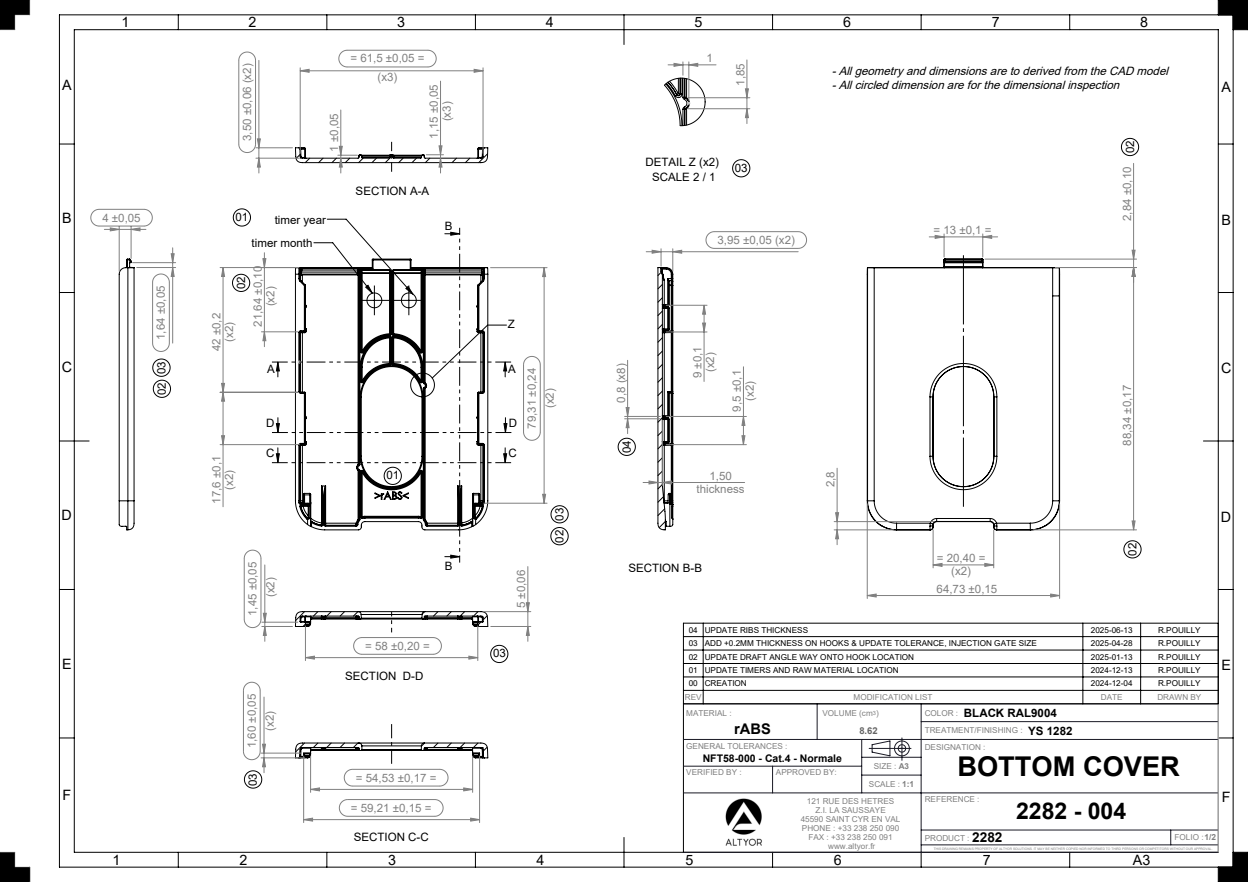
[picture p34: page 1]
timer month; timer year; SECTION A-A; thickness 9 ±0,1 (x2); SECTION B-B; SECTION C-C; SECTION D-D; DETAIL Z (x2) SCALE 2 / 1; rABS; BLACK RAL9004; TREATMENT/FINISHING :; VOLUME (cm3); COLOR :; MATERIAL :; SIZE : A3; SCALE :

- All geometry and dimensions are to derived from the CAD model
- All circled dimension are for the dimensional inspection

04 | UPDATE RIBS THICKNESS | 2025-06-13 | R.POUILLY
03 | ADD +0.2MM THICKNESS ON HOOKS & UPDATE TOLERANCE, INJECTION GATE SIZE | 2025-04-28 | R.POUILLY
02 | UPDATE DRAFT ANGLE WAY ONTO HOOK LOCATION | 2025-01-13 | R.POUILLY
01 | UPDATE TIMERS AND RAW MATERIAL LOCATION | 2024-12-13 | R.POUILLY
00 | CREATION | 2024-12-04 | R.POUILLY
REV | MODIFICATION LIST | DATE | DRAWN BY

GENERAL TOLERANCES : NFT58-000 - Cat.4 - Normale | | DESIGNATION : BOTTOM COVER

VERIFIED BY : | APPROVED BY:

121 RUE DES HETRES Z.I. LA SAUSSAYE 45590 SAINT CYR EN VAL PHONE : +33 238 250 090 FAX : +33 238 250 091 www.altyor.fr | REFERENCE : 2282 - 004

2282 PRODUCT : | FOLIO : 1/2

THIS DRAWING REMAINS PROPERTY OF ALTYOR SOLUTIONS. IT MAY BE NEITHER COPIED NOR INFORMED TO THIRD PERSONS OR COMPETITORS WITHOUT OUR APPROVAL.

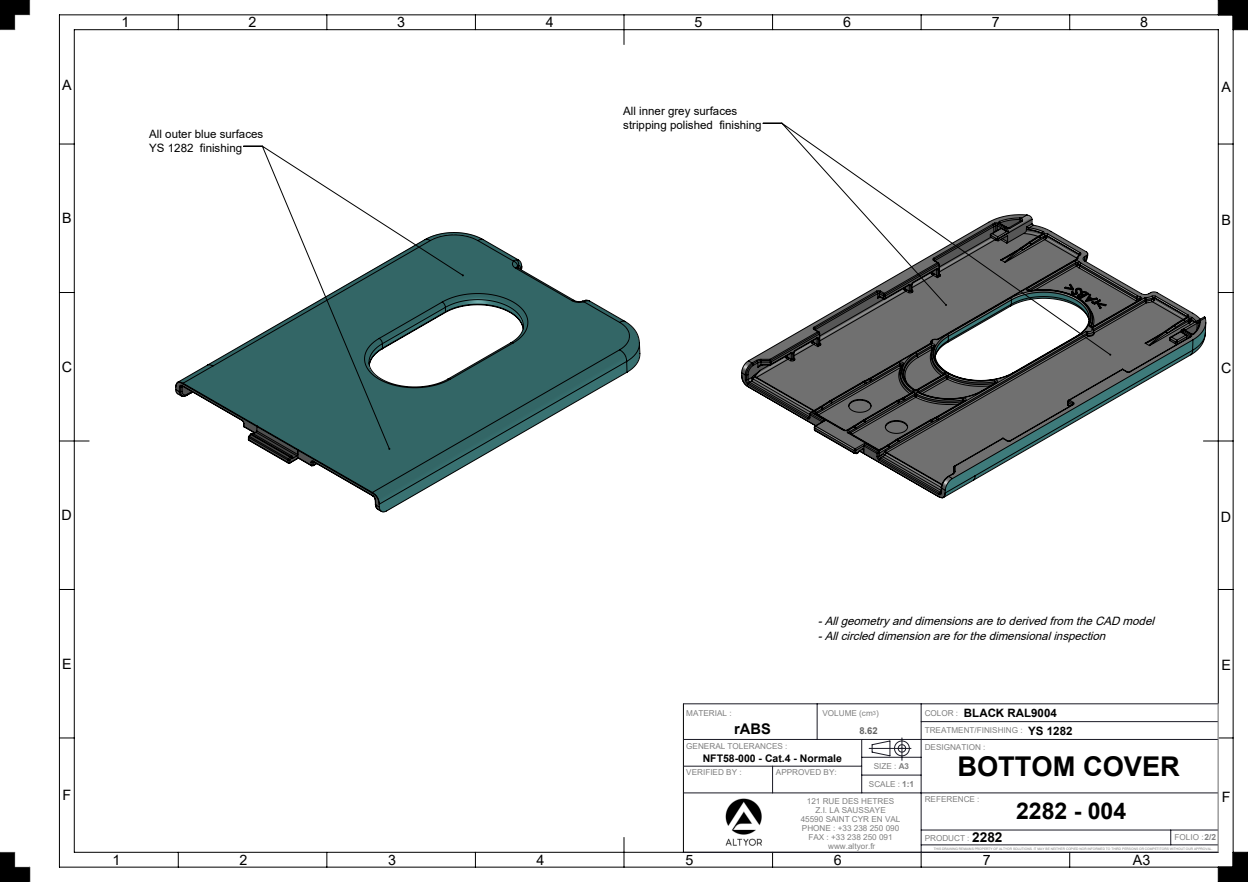
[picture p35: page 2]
rABS; BLACK RAL9004; TREATMENT/FINISHING :; VOLUME (cm3); COLOR :; MATERIAL :; SIZE : A3; SCALE :

All inner grey surfaces

stripping polished finishing All outer blue surfaces
YS 1282 finishing

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

GENERAL TOLERANCES : NFT58-000 - Cat.4 - Normale | | | DESIGNATION : BOTTOM COVER

VERIFIED BY : | APPROVED BY:

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

2282 PRODUCT : | FOLIO : 2/2

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



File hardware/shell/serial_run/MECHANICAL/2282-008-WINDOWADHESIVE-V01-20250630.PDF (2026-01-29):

SCALE :; SIZE : A4; TREATMENT/FINISHING :

dual adhesive tape

- All geometry and dimensions are to derived from the CAD model
- All circled dimension are for the dimensional inspection
Environemental specifications :
-Working specifications must be compliant from -10°C to 60°C

01 | UPDATE INNER &OUTER DIMENSIONS | 2025-06-30 | R.POUILLY
00 | CREATION | 2024-11-28 | R.POUILLY
REV | MODIFICATION LIST | DATE | DRAWN BY
MATERIAL : DOUBLE SIDED ADHESIVE TAPE | VOLUME (cm3) : 0.12 | BLACK COLOR :

GENERAL TOLERANCES : +/- 0.2 | | DESIGNATION : WINDOW ADHESIVE

VERIFIED BY : | APPROVED BY:

121 RUE DES HETRES Z.I. LA SAUSSAYE 45590 SAINT CYR EN VAL PHONE : +33 238 250 090 FAX : +33 238 250 091 www.altyor.fr | REFERENCE : 2282 - 008

PRODUCT : | FOLIO : 1/1

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

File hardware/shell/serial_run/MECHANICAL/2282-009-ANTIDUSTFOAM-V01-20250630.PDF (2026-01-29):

SCALE :; SIZE : A4; TREATMENT/FINISHING :

foam + dual adhesive tape

dual adhesive tape on this side

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

01 | UPDATE INNER & OUTER DIMENSIONS | 2025-06-30 | R.POUILLY
00 | CREATION | 2024-11-28 | R.POUILLY
REV | MODIFICATION LIST | DATE | DRAWN BY
MATERIAL : PE FOAM + SINGLE SIDE ADHESIVE TAPE | VOLUME (cm3) : 0.43 | BLACK COLOR :

GENERAL TOLERANCES : +/- 0.2 | | DESIGNATION : ANTI DUST FOAM

VERIFIED BY : | APPROVED BY:

121 RUE DES HETRES Z.I. LA SAUSSAYE 45590 SAINT CYR EN VAL PHONE : +33 238 250 090 FAX : +33 238 250 091 www.altyor.fr | REFERENCE : 2282 - 009

PRODUCT : | FOLIO : 1/1

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

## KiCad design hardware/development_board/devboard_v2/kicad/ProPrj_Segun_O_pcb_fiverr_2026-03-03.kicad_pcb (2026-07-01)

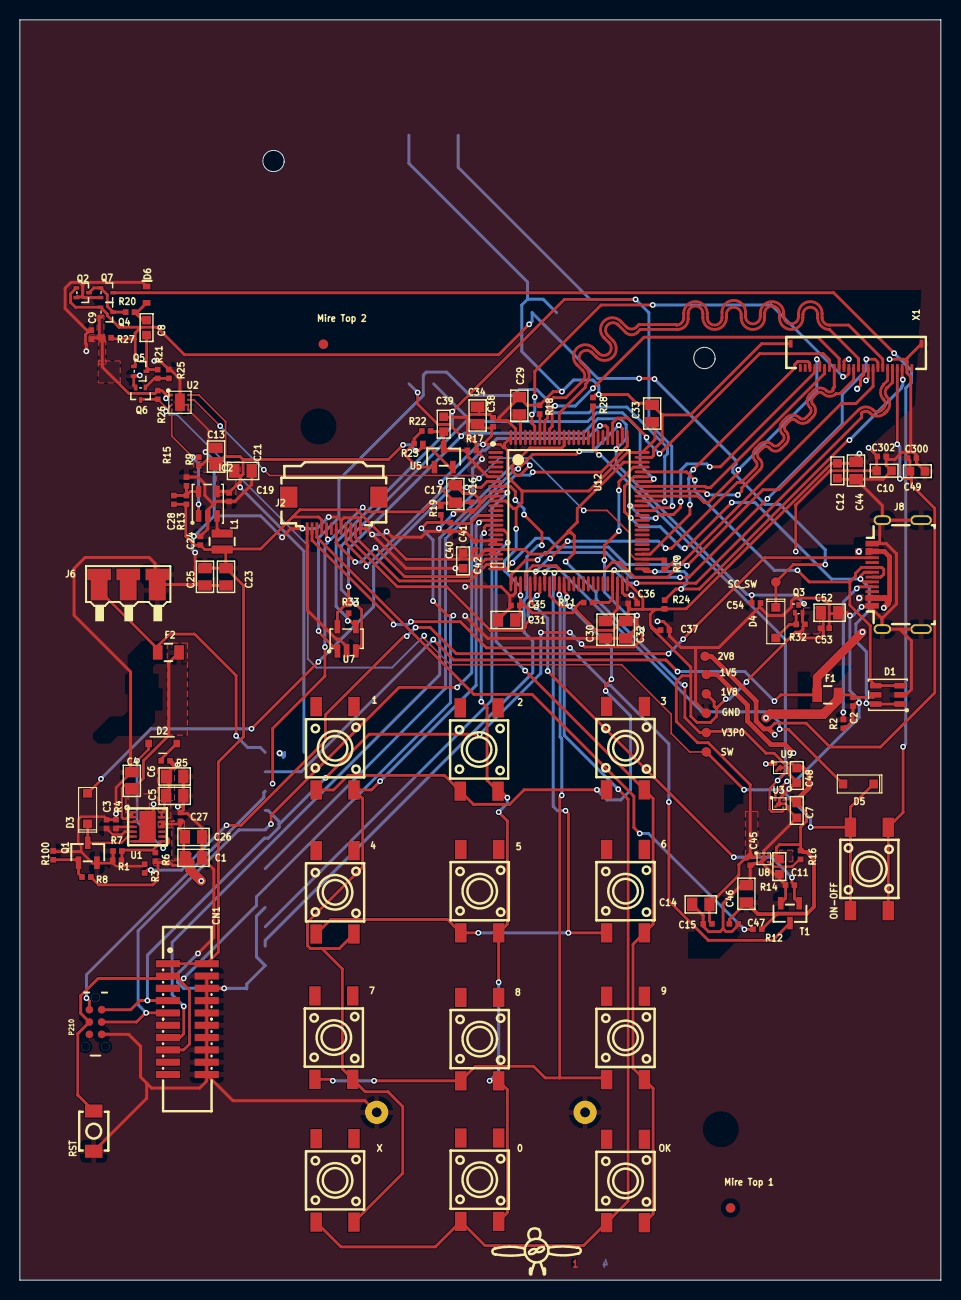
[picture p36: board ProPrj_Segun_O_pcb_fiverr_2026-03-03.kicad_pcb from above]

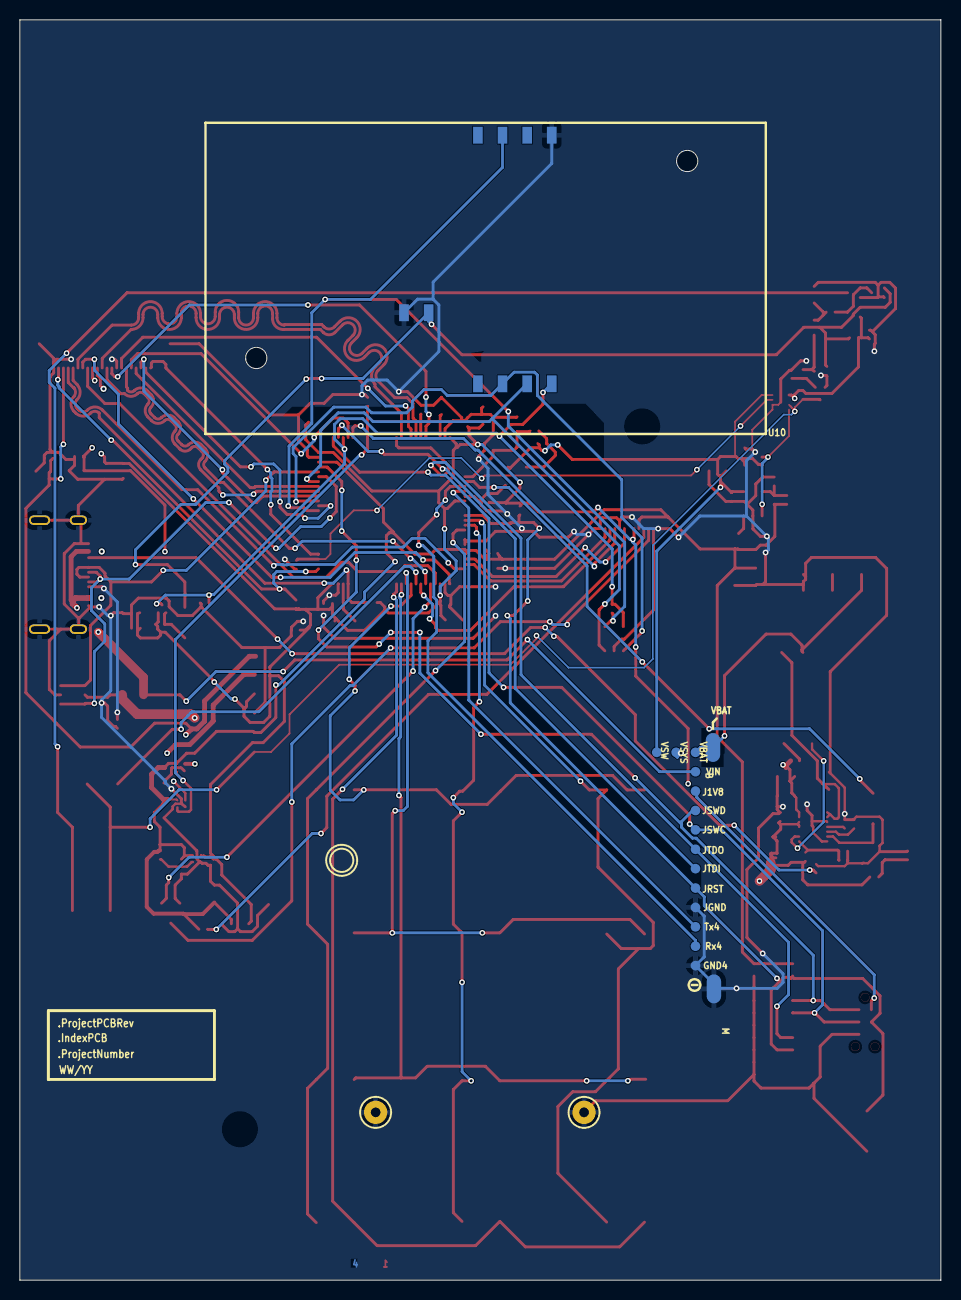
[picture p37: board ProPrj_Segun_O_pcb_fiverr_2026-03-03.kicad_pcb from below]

Board: 4 copper layers, 95.0 x 130.0 mm, 153 parts (17 on the bottom side), 85 nets.

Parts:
0, 1, 2, 3, 4, 5, 6, 7, 8, 9: KEY-SMD_4P-L6.0-W6.0-P3.90-LS9.0
1V5, 1V8, 2V8: TP; TESTPOINT_1MM
B: PLAGE_-_ROUGE
C1, C4, C5, C6, C13, C14, C17, C21, C23, C25, C26, C31, C32, C33, C34, C44, C46, C52: 4.7uF; 0805_-_CAPACITOR
C2, C9, C15, C16, C19, C24, C27, C35, C36, C37, C38, C40, C42, C45, C47, C53, C54, C300: 100nF; 0402_-_CAPACITOR
C3: 4.7uF; 0402_-_CAPACITOR
C7, C8, C10, C11, C12, C39, C41, C48: 1uF; 0603_-_CAPACITOR
C28: 9pF; 0402_-_CAPACITOR
C29, C30: 2.2uF; 0805_-_CAPACITOR
C49: 0603_-_CAPACITOR
C302: 0402_-_CAPACITOR
CN1: HX JN1.27-2x10 TP H4.9; CONN-SMD_HX-JN1.27-2X10-TP-H4.9
D1: 82400152; SOT23-6_0.95_VAR_AA
D2: LR_Y8SF-U1V2-1; OSRAM_LRY8SFU1V21
D3: MBR0530; SOD123_DIODE_INC
D4, D5: MBR0530T1G; SOD123_DIODE_INC
D6: BZX585-C3V0,115; SOD523_TOSHIBA
F1: BNP05000F000; 0805_-_FUSE
F2: 0ZCK0075FF2E; 0805_-_FUSE
GND: TESTPOINT_1MM
GND4: TP; TESTPOINT_1MM
IC2: SY8088IAAC; SOT23-5_0.95_VAR_AA
J1V8: TP; TESTPOINT_1MM
J2: FFC2B35-12-G; GCT_FFC2B35-12-G
J6: 1982633-1; TE_19826331
J8: U6252-35c; ANTENK_U6252-35C
JGND: TESTPOINT_1MM
JRST: TESTPOINT_1MM
JSWC: TESTPOINT_1MM
JSWD: TESTPOINT_1MM
JTDI: TESTPOINT_1MM
JTDO: TESTPOINT_1MM
L1: 2.2uH; CHILISON_BWF00252012
M: PLAGE_-_NOIRE
Mire Top 1, Mire Top 2: MIRE
OK: KEY-SMD_4P-L6.0-W6.0-P3.90-LS9.0
ON-OFF: KEY-SMD_4P-L6.0-W6.0-P3.90-LS9.0
P210: TC2030-MCP-NL
Q1: SOT23-VAR_AB
Q2: SOT-416-3
Q3: RZM002P02T2L; SOT-723
Q4, Q6, Q7: RE1C001ZPTL; SOT-416-3
Q5: RE1C001UNTCL; SOT-416-3
R1: ERTJ0EP473GM; 0402_-_RESISTOR
R2, R3, R4: 5.1kΩ; 0402_-_RESISTOR
R5: 200Ω; 0402_-_RESISTOR
R6: 40.2kΩ; 0402_-_RESISTOR
R7: 118kΩ; 0402_-_RESISTOR
R8, R11, R17, R18, R19, R20, R24: 10kΩ; 0402_-_RESISTOR
R9, R10, R14, R16, R28: 100kΩ; 0402_-_RESISTOR
R12: RC0402FR-0710RL; 0402_-_RESISTOR
R13: 205kΩ; 0402_-_RESISTOR
R15: 49.9kΩ; 0402_-_RESISTOR
R21, R22, R25, R32, R100: 220kΩ; 0402_-_RESISTOR
R23: 75kΩ; 0402_-_RESISTOR
R26: 750kΩ; 0402_-_RESISTOR
R27: 1MΩ; 0402_-_RESISTOR
R33: 11.5kΩ; 0402_-_RESISTOR
RST: SW-SMD_L4.0-W3.0-LS4.8
Rx4: TP; TESTPOINT_1MM
SC_SW: TESTPOINT_1MM
SW: TESTPOINT_1MM
T1: NTR3C21NZT1G; SOT23-VAR_AB
Tx4: TP; TESTPOINT_1MM
U1: MP2607DL-LF-P; QFN14-0.5-3S4
U2: XC6194AA05ER-G; TOREX_USP-8B06
U3: NCP115AMX150TCG; ON_SEMI_NCV8160AMX330TBG
U5: TLVH431AQDBZRG4; SOT23-VAR_AB
U7: ESDS312DBVR; SOT95P270X145-5N
U8: NCP115AMX180TCG; ON_SEMI_NCV8160AMX330TBG
U9: NCP115AMX280TCG; ON_SEMI_NCV8160AMX330TBG
U10: 5145300-3; SD-SMD_5145300-3
U12: STM32H573VIT6; LQFP-100_L14.0-W14.0-P0.50-LS16.0-BL
V3P0: TP; TESTPOINT_1MM
VBAT: TESTPOINT_1MM
VIN: TESTPOINT_1MM
VSW: TESTPOINT_1MM
VSYS: TESTPOINT_1MM
X: KEY-SMD_4P-L6.0-W6.0-P3.90-LS9.0
X1: HC-FPC-05-09-24RLTAG; HCTL_HC-FPC-05-09-24RLTAG

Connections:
$1N29: B.1, VBAT.1
$1N36: ON-OFF.3, ON-OFF.4
$1N37: ON-OFF.1, ON-OFF.2, SW.1
$2N6996: JRST.1, RST.2
/01POWER/BAT: C4.1, F2.2, U1.1 (BAT), U1.2 (BAT)
/01POWER/BAT_BSI: J6.2, J6.5
/01POWER/CC1: J8.A5 (CC1), R2.1
/01POWER/CC2: J8.B5 (CC2), R3.1, R3.2
/01POWER/USB_5V: F1.1, J8.A4_B9 (VBUS), J8.B4_A9 (VBUS)
/02MCU/MCU_BOOT0: R18.2, U12.94 (BOOT0)
/02MCU/VBAT: C39.2, R17.2, R22.1, U5.3 (A), U12.6 (VBAT)
/03PERIPHERALS/BL_A: J2.10, R12.1
/03PERIPHERALS/BL_K: J2.11, T1.3 (D)
CAM_D0: U12.68 (PA9), X1.19
CAM_D1: U12.64 (PC7), X1.21
CAM_D2: U12.54 (PB15), X1.22
CAM_D3: U12.66 (PC9), X1.20
CAM_D4: U12.79 (PC11), X1.18
CAM_D5: U12.92 (PB6), X1.16
CAM_D6: U12.95 (PB8), X1.14
CAM_D7: U12.90 (PB4), X1.12
CAM_HS: U12.29 (PA4), X1.9
CAM_I2C_SCL: R11.1, U12.47 (PB10)
CAM_I2C_SDA: R24.1, U12.51 (PB12)
CAM_PCLK: U12.31 (PA6), X1.17
CAM_PD: U12.26 (PA3), X1.8
CAM_RST: U12.25 (PA2), X1.6
CAM_VS: U12.93 (PB7), X1.7
CAM_XCLK: U12.67 (PA8), X1.13
GND: C1.2, C2.2, C3.2, C4.2, C5.2, C6.2, C7.1, C9.2, C10.1, C11.1, C12.1, C13.1, C14.1, C15.1, C16.1, C17.1, C19.2, C21.1, C23.1, C24.2, C25.1, C26.2, C27.2, C29.1, C30.1, C31.1, C32.1, C33.1, C34.1, C35.1, C36.1, C37.1, C38.1, C39.1, C40.2, C41.1, C42.1, C44.1, C45.1, C46.1, C47.1, C48.1, C49.2, C52.1, C53.1, C54.1, C300.1, C302.2, CN1.4, CN1.6, CN1.8, CN1.10, CN1.12, CN1.14, CN1.16, CN1.18, CN1.20, D1.2 (GND), GND.1, GND4.1 (PT), IC2.2 (GND), J2.1, J2.5, J2.12, J6.1, J6.4, J8.A1_B12 (GND), J8.B1_A12 (GND), J8.S1 (SHELL), J8.S2 (SHELL), J8.S3 (SHELL), J8.S4 (SHELL), JGND.1, M.1, P210.6, Q1.2, Q2.2, Q5.2 (S), Q6.2 (S), Q7.2 (S), R1.1, R2.2, R4.1, R7.1, R10.1, R14.1, R15.1, R17.1, R18.1, R25.1, R28.1, R100.1, RST.1, T1.2 (S), U1.3 (MODE), U1.7 (GND), U1.TH_PAD (GND), U2.5 (GND), U2.6 (TEST), U2.TH_PAD, U3.2 (GND), U3.5 (EP), U7.2 (GND), U8.2 (GND), U8.5 (EP), U9.2 (GND), U9.5 (EP), U10.C5, U10.C10, U12.10 (VSS), U12.19 (VSSA), U12.20 (VREF-), U12.27 (VSS), U12.49 (VSS), U12.74 (VSS), U12.99 (VSS), X1.0, X1.2, X1.15
JTCK_SWCLK: CN1.9, JSWC.1, P210.4, U12.76 (PA14)
JTDI: JTDI.1, U12.77 (PA15)
JTDO_SWO: CN1.13, JTDO.1, U12.89 (PB3)
JTMS_SWDIO: CN1.7, JSWD.1, P210.2, U12.72 (PA13)
KBD_C0: 3.2, 6.2, 9.2, OK.2, U12.17 (PC2)
KBD_C1: 0.2, 2.2, 5.2, 8.2, U12.16 (PC1)
KBD_C2: 1.2, 4.2, 7.2, U12.15 (PC0), X.2
KBD_R0: 0.4, OK.4, U12.37 (PB2), X.4
KBD_R1: 7.4, 8.4, 9.4, U12.36 (PB1)
KBD_R2: 4.4, 5.4, 6.4, U12.35 (PB0)
KBD_R3: 1.4, 2.4, 3.4, U12.34 (PC5)
MCU_RST: CN1.3, CN1.15, P210.3
MCU_SC_PRES: C54.2, Q3.3 (D), R33.2, U7.5 (I/O2), U12.78 (PC10)
MCU_USB2_N: D1.1 (I/O1), D1.6 (I/O1), J8.A7 (DN1), J8.B7 (DN2), U12.70 (PA11)
MCU_USB2_P: D1.3 (I/O2), D1.4 (I/O2), J8.A6 (DP1), J8.B6 (DP2), U12.71 (PA12)
unnamed: F2.1, J6.3, J6.6
unnamed: C29.2, U12.98 (VCAP)
unnamed: C30.2, U12.48 (VCAP)
unnamed: D2.1 (C), U1.9 (~STAT2~)
unnamed: Q3.1 (G), R32.1
unnamed: Q6.3 (D), R26.1, U2.3 (SW)
unnamed: C8.2, R20.2
unnamed: C28.1, IC2.5 (FB), R13.1, R15.2
unnamed: IC2.3 (L), L1.1
unnamed: Q4.2 (S), Q7.1 (G), R20.1
unnamed: C8.1, Q5.3 (D), R21.1
unnamed: Q6.1 (G), R21.2, R25.2
unnamed: R8.1, R100.2
unnamed: Rx4.1 (PT), U12.8 (PC14-OSC32_IN)
unnamed: Tx4.1 (PT), U12.9 (PC15-OSC32_OUT)
unnamed: R4.2, U1.4 (ICHSET)
unnamed: R1.2, R6.1, R7.2, U1.8 (NTC)
unnamed: C3.1, U1.5 (TMR)
unnamed: R22.2, R23.1, U5.1 (REF)
unnamed: R16.1, U8.3 (EN)
unnamed: C40.1, R19.2, U12.14 (NRST)
PWR_CAM_EN: R28.2, U9.3 (EN), U12.83 (PD2)
PWR_KILL: R10.2, U2.7 (SHDN), U12.53 (PB14)
SCR_BL_PWM: R14.2, T1.1 (G), U12.30 (PA5)
SCR_D/C: J2.6, U12.23 (PA0)
SCR_RST: J2.2, U12.24 (PA1)
SCR_SPI_MOSI: J2.3, U12.32 (PA7)
SCR_SPI_SCK: J2.4, U12.80 (PC12)
SC_PRES_SW: Q2.1, Q4.1 (G), Q5.1 (G), R27.1, SC_SW.1, U10.C9
SC_RST: U7.3 (NC), U12.69 (PA10)
SC_USART_CLK: U7.1 (NC), U12.65 (PC8)
SC_USART_TX: R33.1, U7.4 (I/O1), U12.63 (PC6)
SYS_PG: IC2.1 (EN), R9.1, U2.4 (PG)
V1P5: 1V5.1 (PT), C10.2, C302.1, U3.1 (OUT), X1.10
V1P8: 1V8.1 (PT), C12.2, C14.2, C15.2, C16.2, C17.2, C31.2, C32.2, C33.2, C34.2, C35.2, C36.2, C37.2, C38.2, C44.2, C45.2, C52.2, C53.2, J1V8.1 (PT), J2.8, P210.1, Q3.2 (S), R11.2, R19.1, R24.2, R32.2, U8.1 (OUT), U12.11 (VDD), U12.28 (VDD), U12.50 (VDD), U12.75 (VDD), U12.100 (VDD), X1.11
V2P8: 2V8.1 (PT), C49.1, C300.2, U9.1 (OUT), X1.4
V3P0: C7.2, C11.2, C23.2, C24.1, C25.2, C28.2, C41.2, C42.2, C46.2, C47.2, C48.2, CN1.1, CN1.2, J2.9, L1.2, R12.2, R13.2, R16.2, U3.4 (IN), U8.4 (IN), U9.4 (IN), U12.21 (VREF+), U12.22 (VDDA), U12.73 (VDDUSB), V3P0.1 (PT)
VSYS: C5.1, C6.1, C9.1, Q4.3 (D), R5.1, R5.2, R26.2, R27.2, U1.13 (SYS), U1.14 (SYS), U2.1 (VIN), VSYS.1
VSYS_SWITCHED: C13.2, C19.1, C21.2, IC2.4 (VIN), R9.2, R23.2, U2.8 (VOUT), U5.2 (C), VSW.1
VUSB: C1.1, C2.1, C26.1, C27.1, D1.5 (VBUS), F1.2, R6.2, R8.2, U1.11 (IN), U1.12 (IN)

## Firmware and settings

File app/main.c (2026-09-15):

#include "common.h"
#include "FreeRTOS.h"
#include "task.h"
#include "hal.h"

#include "core/settings.h"

#define USB_STACK_SIZE 800
#define USB_TASK_PRIO 1

#define CORE_STACK_SIZE 2048
#define CORE_TASK_PRIO 2

#define UI_STACK_SIZE 6000
#define UI_TASK_PRIO 3

APP_DEF_TASK(usb, USB_STACK_SIZE);
APP_DEF_TASK(core, CORE_STACK_SIZE);
APP_DEF_TASK(ui, UI_STACK_SIZE);

#define FW_MAJOR 1
#define FW_MINOR 4
#define FW_PATCH 0

// Beta version. 0 means release.
// Although not customary, to keep downgrade protection simple betas of the next release
// share the main version number with the current stable release
#define FW_BETA 0

__attribute__((section(".fw_signature"))) __attribute__((__used__)) const uint8_t FW_SIGNATURE[64];
__attribute__((section(".fw_version"))) __attribute__((__used__)) const uint8_t FW_VERSION[4] = { FW_MAJOR, FW_MINOR, FW_PATCH, FW_BETA };

int main(void) {
  hal_init();
  settings_load();

  APP_CREATE_TASK(usb, USB_TASK_PRIO);
  APP_CREATE_TASK(core, CORE_TASK_PRIO);
  APP_CREATE_TASK(ui, UI_TASK_PRIO);

  vTaskStartScheduler();

  while(1) {
    __asm volatile ("nop");
  }
}

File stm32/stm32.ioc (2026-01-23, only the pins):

Mcu.UserName=STM32H573VITx
PA0.GPIO_Label=GPIO_LCD_CD
PA0.Signal=GPIO_Output
PA1.GPIO_Label=GPIO_LCD_RST
PA1.Signal=GPIO_Output
PA10.GPIO_Label=GPIO_CARD_RST
PA10.Signal=GPIO_Output
PA11.Signal=USB_DM
PA12.Signal=USB_DP
PA13(JTMS/SWDIO).GPIO_Label=SWDIO
PA13(JTMS/SWDIO).Signal=DEBUG_JTMS-SWDIO
PA14(JTCK/SWCLK).GPIO_Label=SWCLK
PA14(JTCK/SWCLK).Signal=DEBUG_JTCK-SWCLK
PA2.GPIO_Label=GPIO_CAMERA_RST
PA2.Signal=GPIO_Output
PA3.GPIO_Label=GPIO_CAMERA_PWDN
PA3.Signal=GPIO_Output
PA4.Signal=DCMI_HSYNC
PA5.GPIO_Label=PWM_LCD_BL
PA5.Signal=S_TIM2_CH1
PA6.Signal=DCMI_PIXCLK
PA7.Signal=SPI6_MOSI
PA8.GPIO_Label=CAM_XCLK
PA8.Signal=RCC_MCO_1
PA9.Signal=DCMI_D0
PB0.GPIO_Label=GPIO_KEYPAD_ROW_1
PB0.Signal=GPIO_Output
PB1.GPIO_Label=GPIO_KEYPAD_ROW_2
PB1.Signal=GPIO_Output
PB10.Signal=I2C2_SCL
PB12.Signal=I2C2_SDA
PB14.GPIO_Label=GPIO_PWR_KILL
PB14.Signal=GPIO_Output
PB15.Signal=DCMI_D2
PB2.GPIO_Label=GPIO_KEYPAD_ROW_3
PB2.Signal=GPIO_Output
PB3(JTDO/TRACESWO).GPIO_Label=SWO
PB3(JTDO/TRACESWO).Signal=DEBUG_JTDO-SWO
PB4(NJTRST).Signal=DCMI_D7
PB6.Signal=DCMI_D5
PB7.Signal=DCMI_VSYNC
PB8.Signal=DCMI_D6
PC0.GPIO_Label=GPIO_KEYPAD_COL_2
PC0.Signal=GPIO_Input
PC1.GPIO_Label=GPIO_KEYPAD_COL_1
PC1.Signal=GPIO_Input
PC10.GPIO_Label=GPIO_SC_PRES
PC10.Signal=GPXTI10
PC11.Signal=DCMI_D4
PC12.Signal=SPI6_SCK
PC13.GPIO_Label=GPIO_VUSB_OK
PC13.Signal=GPXTI13
PC2.GPIO_Label=GPIO_KEYPAD_COL_0
PC2.Signal=GPIO_Input
PC4.GPIO_Label=GPIO_HALT_REQ
PC4.Signal=GPXTI4
PC5.GPIO_Label=GPIO_KEYPAD_ROW_0
PC5.Signal=GPIO_Output
PC6.Signal=USART6_TX
PC7.Signal=DCMI_D1
PC8.Signal=USART6_CK
PC9.Signal=DCMI_D3
PD2.GPIO_Label=GPIO_CAM_EN
PD2.Signal=GPIO_Output

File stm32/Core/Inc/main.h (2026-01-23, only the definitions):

#define KEYPAD_POLL_MS 5
#define SC_DEFAULT_PSC 25
#define SC_DEFAULT_BAUD_RATE 10752
#define HALT_REQ_MS 10
#define GPIO_VUSB_OK_Pin GPIO_PIN_13
#define GPIO_VUSB_OK_GPIO_Port GPIOC
#define GPIO_VUSB_OK_EXTI_IRQn EXTI13_IRQn
#define GPIO_KEYPAD_COL_2_Pin GPIO_PIN_0
#define GPIO_KEYPAD_COL_2_GPIO_Port GPIOC
#define GPIO_KEYPAD_COL_1_Pin GPIO_PIN_1
#define GPIO_KEYPAD_COL_1_GPIO_Port GPIOC
#define GPIO_KEYPAD_COL_0_Pin GPIO_PIN_2
#define GPIO_KEYPAD_COL_0_GPIO_Port GPIOC
#define GPIO_LCD_CD_Pin GPIO_PIN_0
#define GPIO_LCD_CD_GPIO_Port GPIOA
#define GPIO_LCD_RST_Pin GPIO_PIN_1
#define GPIO_LCD_RST_GPIO_Port GPIOA
#define GPIO_CAMERA_RST_Pin GPIO_PIN_2
#define GPIO_CAMERA_RST_GPIO_Port GPIOA
#define GPIO_CAMERA_PWDN_Pin GPIO_PIN_3
#define GPIO_CAMERA_PWDN_GPIO_Port GPIOA
#define PWM_LCD_BL_Pin GPIO_PIN_5
#define PWM_LCD_BL_GPIO_Port GPIOA
#define GPIO_HALT_REQ_Pin GPIO_PIN_4
#define GPIO_HALT_REQ_GPIO_Port GPIOC
#define GPIO_HALT_REQ_EXTI_IRQn EXTI4_IRQn
#define GPIO_KEYPAD_ROW_0_Pin GPIO_PIN_5
#define GPIO_KEYPAD_ROW_0_GPIO_Port GPIOC
#define GPIO_KEYPAD_ROW_1_Pin GPIO_PIN_0
#define GPIO_KEYPAD_ROW_1_GPIO_Port GPIOB
#define GPIO_KEYPAD_ROW_2_Pin GPIO_PIN_1
#define GPIO_KEYPAD_ROW_2_GPIO_Port GPIOB
#define GPIO_KEYPAD_ROW_3_Pin GPIO_PIN_2
#define GPIO_KEYPAD_ROW_3_GPIO_Port GPIOB
#define GPIO_PWR_KILL_Pin GPIO_PIN_14
#define GPIO_PWR_KILL_GPIO_Port GPIOB
#define CAM_XCLK_Pin GPIO_PIN_8
#define CAM_XCLK_GPIO_Port GPIOA
#define GPIO_CARD_RST_Pin GPIO_PIN_10
#define GPIO_CARD_RST_GPIO_Port GPIOA
#define SWDIO_Pin GPIO_PIN_13
#define SWDIO_GPIO_Port GPIOA
#define SWCLK_Pin GPIO_PIN_14
#define SWCLK_GPIO_Port GPIOA
#define GPIO_SC_PRES_Pin GPIO_PIN_10
#define GPIO_SC_PRES_GPIO_Port GPIOC
#define GPIO_SC_PRES_EXTI_IRQn EXTI10_IRQn
#define GPIO_CAM_EN_Pin GPIO_PIN_2
#define GPIO_CAM_EN_GPIO_Port GPIOD
#define SWO_Pin GPIO_PIN_3
#define SWO_GPIO_Port GPIOB

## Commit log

2025-01-21 add button test
2025-01-24 add usb power test
2025-02-27 align pin and puk dialog to design
2025-03-03 update STM32HAL to 1.5.0
2025-03-10 implement lower/upper case keyboard
2025-03-12 add PIN glyphs to icons
2025-03-18 align PIN confimation to design
2025-03-19 replace battery icons
2025-03-21 implement device info dialog
2025-03-24 align auth flow to design
2025-03-25 move battery threshold defs
2025-03-27 invert qr and version prompt
    [updater.c]
2025-03-27 correct dev name in QR
    [core.c]
2025-04-08 add duress pin during setup
2025-04-16 add missing return value
    [core.c]
2025-04-16 make duress pin flow more explicit
2025-05-15 implement abi db encoder
2025-05-28 added cancel button to QR screens
2025-05-28 fixed usb handling outside of main menu
    [core.c]
2025-05-28 Create electronics-and-bom
2025-06-03 fix cancel interaction in qr screens
    [auth.c, updater.c]
2025-06-04 db update now correctly differentiate between invalid data and user cancel
    [updater.c]
2025-06-16 slightly shorter long press
    [keypad.c]
2025-06-19 reviewed folder structure and added new designs
    new designs
    - shell pilot run mechanical parts
    - development board v1 design (bom, schematics, gerber)
    - v1 of shell packaging die cuts.
    [00 Structure.SchDoc, 01 POWER.SchDoc, 02 MCU.SchDoc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]
2025-06-20 Rename print_sample_RV.ai to print_sample_RV.ai (#122)
    rename directory that breaks repo on windows
2025-06-25 check that duress PIN and main PIN do not match
2025-07-08 align SPI clock config to constraints
2025-08-07 add prototype keycard-based signing
2025-08-11 use VUSB_OK to determine charging status
2025-08-19 default to chainID 1 for legacy tx
2025-08-19 change PID
2025-08-19 move chainid initialization
2025-08-19 fix some usb-related functions
    [core.c]
2025-09-17 add skip help settings
    [auth.c, core_task.c]
2025-10-09 add device csv script
2025-10-23 filter non-eth chains/tokens
2025-10-28 make verifyingContract and chainId optional in EIP712Domain
2026-01-28 Add serial run hardware and mechanical files, remove spaces from filenames
    - Added new serial_run directory with hardware documentation
    - Renamed files in pilot_run and prototype_P2 to remove spaces
    - Updated electronics, mechanical parts, and BOM files
    [00 Structure.SchDoc, 00Structure.SchDoc, 01 POWER.SchDoc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]
2026-01-29 Add KCP-2282 schematic V3.8 and updated assembly STEP file
    [00Structure.SchDoc, 01POWER.SchDoc, 02MCU.SchDoc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]
2026-01-29 Revise readme for Keycard Shell and deprecation notice
    Updated the readme to reflect the deprecation of pilot_run and prototype_v2 versions, and improved section formatting.
2026-02-02 Add PCB doc files for FLX-2282-611 and KCP-2282-601
    [FLX-2282-611-PCBV3.3.PcbDoc]
2026-02-02 Update KCP-2282 schematic V3.8 assets
    [00Structure.SchDoc, 01POWER.SchDoc, Folio01.SchDoc]
2026-02-02 Update readme with layout update instructions
    Added instructions for updating the development board layout.
2026-02-04 fix alternative account gen
    [core.c, main.c]
2026-02-09 add check to bip32 length when getting parent fingerprint
2026-03-10 show fingerprint when no card name set
2026-03-26 use ARM GCC Toolchain 15.2.rel1 and automate download
2026-04-14 add devboard v2 hardware design files
    Add the full devboard v2 manufacturing and design package so the latest board revision artifacts are versioned with the project.
    [1_01POWER.kicad_sch, 2_02MCU.kicad_sch, 3D_KCP-2282-601-PCBV3.8_2026-03-03.step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]
2026-07-01 Add devboard v2 gerbers with USB layout fix.
    Update KiCad PCB copper around the USB area and export manufacturing files to Gerber_KCP-2282-601-PCBV3.8_Fixed_USB.
    [ProPrj_Segun O pcb fiverr_2026-03-03-Board Outline Layer.gm1, ProPrj_Segun O pcb fiverr_2026-03-03-Bottom Layer.gbl, ProPrj_Segun O pcb fiverr_2026-03-03-Botto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]
2026-07-01 Rename devboard v2 files to remove spaces from paths.
    Replace spaces with underscores in KiCad, gerber, and footprint filenames so the branch can be committed and pushed on GitHub without path issues.
    [1_01POWER.kicad_sch, 2_02MCU.kicad_sch, 3_03PERIPHERALS.kicad_sch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]
2026-08-24 better unblock pin handling
2026-09-15 more guided verify flow
2026-09-29 fix fingerprint sizing
2026-10-15 Document the main board version of the first production (#231)
    Units built in December 2025 use PCB V3.7, whose files are in pilot_run.
    serial_run holds V3.8 (longer USB-C pads), not produced yet.
2026-11-10 change dma interrupt preempt prio
2026-11-11 groundwork to enable more tests
2026-11-12 2-step device verification

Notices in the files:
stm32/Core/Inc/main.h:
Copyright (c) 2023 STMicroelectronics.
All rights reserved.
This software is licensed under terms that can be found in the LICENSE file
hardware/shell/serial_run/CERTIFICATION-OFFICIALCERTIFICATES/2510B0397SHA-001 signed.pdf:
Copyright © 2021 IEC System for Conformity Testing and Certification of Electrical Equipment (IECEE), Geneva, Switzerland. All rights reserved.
